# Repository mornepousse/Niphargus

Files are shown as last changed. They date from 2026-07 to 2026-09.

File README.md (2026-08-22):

<p align="center">
  <picture>
    <source media="(prefers-color-scheme: dark)" srcset="images/niphargus_logo_white.svg">
    Niphargus
  </picture>
</p>

<h1 align="center">Niphargus</h1>

<p align="center">
  <em>The cave shrimp: blind, discreet, indestructible.</em><br>
  <em>La crevette des cavernes : aveugle, discrète, indestructible.</em>
</p>

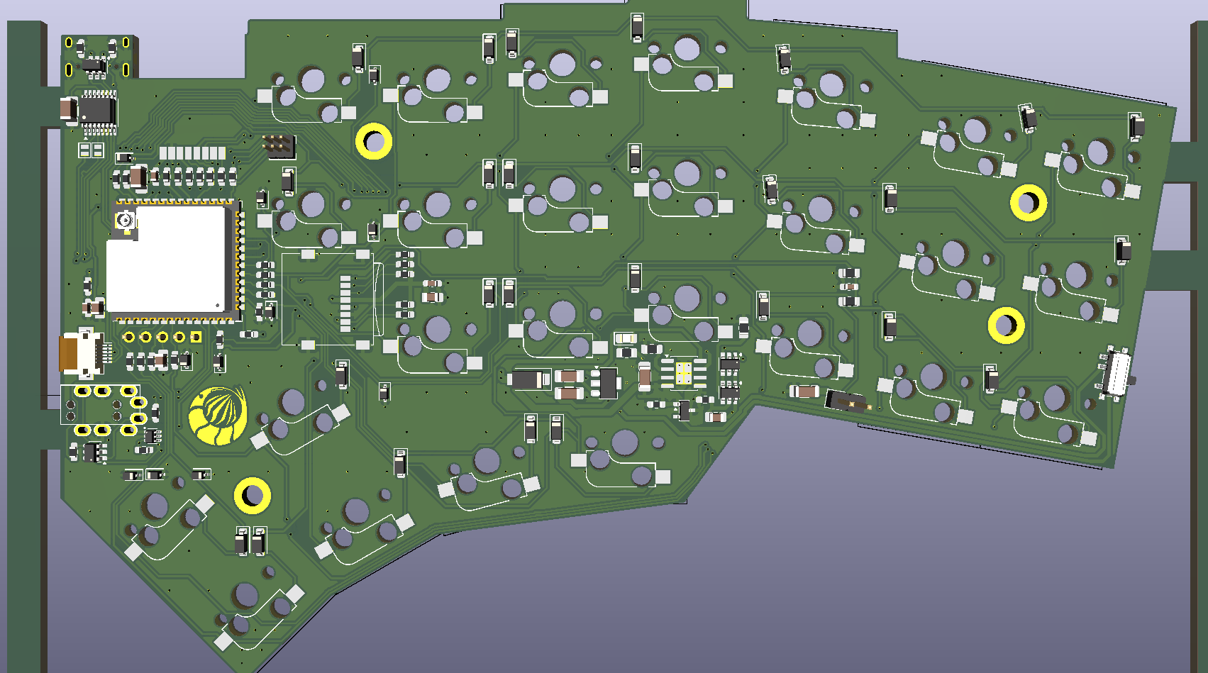
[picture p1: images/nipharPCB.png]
Niphargus PCB v2


---

## English

Niphargus is a thin, unkillable wireless split keyboard.

- **Two self-contained halves** — one ESP32-S3-WROOM-1 + nRF24L01+ and a 16340
  cell each, matrix scanning in deep sleep (RTC domain), the
  [KeSp dongle](https://github.com/mornepousse/KeSp_dongle) on the host side.
- **Wired fallback** — direct USB-C plus a TRRS jack between halves: *plugging it
  back in must be enough*. A 5 V handshake on the link makes hot-plug spark-free.
- **ESD hardening throughout** — TVS diodes on USB and TRRS, 100 Ω in series on
  every matrix line, careful ground planes. The static discharge you bring back
  to the keyboard will no longer crash it.
- **Sharp Memory LCD** (right half) for layer and battery status: holds its image
  at a few µA and never flickers. **Azoteq TPS43 trackpad** (left half), over I²C.
- **The survival kit** — an ESP32-P4 vault behind a CH334R USB hub: multi-ISO boot
  key, PGP token, storage. It only powers up when the keyboard is plugged in.

A complete redesign of the **Rouge-Gorge** (v1, 2022), a Jorne / Kyria rev2
derivative that was never built. This repository carries the full history:
Rouge-Gorge → rili → Niphargus.

**Status (2026-08)** — v2 schematic complete and reviewed, board routed, ERC and
DRC clean. Case in progress (see below). Firmware to follow.

## Français

Niphargus est un clavier split sans fil, fin et increvable.

- **Deux moitiés autonomes** — ESP32-S3-WROOM-1 + nRF24L01+ et une batterie 16340
  chacune, scan de la matrice en sommeil profond (domaine RTC),
  [dongle KeSp](https://github.com/mornepousse/KeSp_dongle) côté hôte.
- **Repli filaire** — USB-C direct et jack TRRS entre les moitiés : *rebrancher
  doit suffire*. Une poignée de main 5 V sur le lien évite les étincelles au branchement à chaud.
- **Robustesse ESD partout** — TVS sur USB et TRRS, 100 Ω série sur chaque ligne
  de matrice, plans de masse soignés. La décharge que vous ramenez au clavier ne
  le plantera plus.
- **Écran Sharp Memory LCD** (moitié droite) pour le calque et l'état des batteries :
  tient l'image à quelques µA sans jamais clignoter. **Trackpad Azoteq TPS43**
  (moitié gauche), en I²C.
- **La trousse de secours** — un coffre ESP32-P4 derrière un hub USB CH334R : clé
  bootable multi-ISO, token PGP, stockage. Il ne s'allume qu'en filaire.

Refonte complète du **Rouge-Gorge** (v1, 2022), un dérivé du Jorne et du Kyria
rev2 resté sur le papier. Le dépôt porte tout l'historique :
Rouge-Gorge → rili → Niphargus.

**État (2026-08)** — schéma v2 terminé et relu, carte routée, ERC et DRC au vert.
Boîtier en cours (ci-dessous). Firmware à suivre.

---

## Repository layout · Organisation du dépôt

| Path | Contents |
|---|---|
| `hardware/pcb/` | KiCad project — `niphar.kicad_pro` (schematic, board, footprints) |
| `hardware/order-*.csv` | Part orders: TME, LCSC, AliExpress |
| `hardware/kit-jlcpcb/` | Gerbers, BOM and CPL for JLCPCB |
| `case/` | Case generator and CAD output |
| `scripts/` | Anti-regression checks |
| `docs/` | Design specs and plans |

### Case · Boîtier

Three parts: a **CNC-machined 8.5 mm aluminium frame**, sandwiched between two
**2 mm polycarbonate plates**, 12.5 mm overall. The 16340 cell sits *beside* the
board, in a pocket milled into the frame itself.

Trois pièces : un **cadre aluminium usiné de 8,5 mm** pris entre deux **plaques
polycarbonate de 2 mm**, 12,5 mm hors tout. La 16340 se loge *à côté* de la carte,
dans une poche fraisée à même le cadre.

The frame outline is **not computed — it is drawn**. Edit `case/case_outline.svg`
(KiCad coordinates, 1 unit = 1 mm), then run:

Le contour du cadre n'est **pas calculé, il est dessiné**. Éditez
`case/case_outline.svg` (repère KiCad, 1 unité = 1 mm), puis lancez :

```sh
freecad --console case/gen_case.py
```

This regenerates the `.FCStd`, the STEP, the STL files and `case_plan.svg`.

### Anti-regression · Anti-régression

```sh
./scripts/check.sh --fast   # schematic ERC against the committed baseline
./scripts/check.sh          # + full board DRC
./scripts/install-hooks.sh  # once per clone: pre-push runs the full check
```

Green means *never more ERC/DRC errors or warnings than the committed baseline*
(`.tripwire-kicad-baseline`). CI is pinned to KiCad 10.0.4 with its own reference.

Vert signifie *jamais plus d'erreurs ni de warnings ERC/DRC que la référence
committée*. La CI est épinglée sur KiCad 10.0.4 avec sa propre référence.

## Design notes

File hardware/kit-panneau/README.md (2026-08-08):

# Kit de fabrication

> **Commandé le 2026-08-08 chez JLCPCB — 60,83 €.** Avant de souder, lire
> [`AU-MONTAGE.md`](AU-MONTAGE.md) : **J6 se soude par le dessous**, le monter
> par le dessus inverse Tip et Sleeve.

Après devis, on commande les deux cartes **séparément**, et le clavier dans sa
version **compacte**.

| Zip | Ce que c'est | Dimensions | Designs | Prix |
|---|---|---|---|---|
| `niphargus-gerbers.zip` | le clavier, 2 moitiés sécables | 340,9 × 104,8 | 2 | 54,78 € |
| `conchodytes-seul-gerbers.zip` | la souris | 39,0 × 81,5 | 1 | 6,06 € |

**60,84 €**, contre 70,89 € pour le panneau commun de départ. Le raisonnement
chiffré est dans `COMPARATIF.md`.

## Le panneau du clavier

340,9 × 104,8 mm, 4 couches, **357,3 cm²**. Les deux moitiés sont côte à côte,
la droite tête-bêche, séparées par une fente de 2,5 mm et reliées par deux
ponts de ~6,5 mm munis chacun d'un `MouseBite-Slot` à double rang.

Le tête-bêche n'est pas cosmétique : remise dans le même sens, la moitié droite
ne touche la gauche que sur **1,75 mm** — les deux bords en vis-à-vis sont
biseautés et divergents. Tête-bêche ils sont parallèles sur **70 mm**, de quoi
poser de vrais ponts, pour 1,6 cm² de plus.

⚠️ **Les mouse-bites vont au milieu du tab, jamais au ras du bord de carte** :
là, ils tombent dans le plan de masse (35 `hole_clearance`, vérifié). Ici les
perçages sont à 0,45 mm du bord, au-dessus du minimum JLC de 0,3. Et après en
avoir posé, **refiller les zones** — sinon 28 `hole_clearance` de plus, que le
refill dissout.

Empreintes réutilisables dans `MaeLid` : `MouseBite_4x0.5mm`, `_5x0.5mm`,
`_6x0.5mm`.

## Le panneau commun, écarté

`scripts/merge_panel.py` sait loger la souris dans le vide du panneau clavier.
La technique fonctionne — contour refermé autour des tabs, 76 mouse-bites — mais
le surcoût du 3ᵉ design (14,21 €) dépasse le prix de la souris seule (6,06 €).
Conservé pour le jour où le rapport de prix changerait.

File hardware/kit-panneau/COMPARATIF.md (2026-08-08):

# Comparatif de commande — à remplir avec les devis JLCPCB

Trois variantes exportées pour comparer le coût réel du multi-design.

| Zip | Contenu | Dimensions | Surface | Designs | Prix (vert, 2026-08) |
|---|---|---|---|---|---|
| `niphargus-gerbers.zip` | **clavier horizontal, retenu** | 340,9 × 104,8 | 357,3 cm² | **2** | **54,78 €** |
| *(clavier compact empilé)* | même design, moitiés imbriquées | 169,2 × 198,2 | 335 cm² | 2 | 53,65 € |
| `conchodytes-seul-gerbers.zip` | **souris, retenue** | 39,0 × 81,5 | 31,8 cm² | **1** | **6,06 €** |
| *(ancien panneau 185,4 × 212,3)* | clavier avant re-panneautage | | 393,5 cm² | 2 | 56,68 € |
| *(panneau commun, écarté)* | clavier + souris | 185,4 × 212,3 | 393,5 cm² | 3 | 70,89 € |

## Décision : commander séparément, avec le panneau horizontal

**Commandé le 2026-08-08 : 60,83 €.**

Devis JLCPCB, 4 couches vert, août 2026 :

```
   A  panneau commun 3 designs                        70,89 EUR
   B  clavier 394 cm2 empile   + souris        56,68 + 6,06 = 62,74 EUR
   C  clavier 335 cm2 empile   + souris        53,65 + 6,06 = 59,71 EUR
   D  clavier 357 cm2 horizontal + souris      54,78 + 6,06 = 60,84 EUR  <-- retenu
```

**10,05 EUR d'economie** entre le point de depart et la solution retenue.

Le panneau horizontal coute **1,13 EUR de plus** que l'empile (option C) : il a
6,4 % de surface en plus, l'imbrication verticale des deux moities n'etant pas
reproductible cote a cote. Il a ete retenu pour sa forme, pas pour son prix.

La repartition est instructive :

- **8,15 EUR** viennent du seul fait de **ne pas panneauter la souris avec le
  clavier**. Ajouter la souris au panneau coute 14,21 EUR de surcout
  multi-design alors que la carte seule vaut 6,06 EUR : on la paierait 2,3 fois
  son prix, pour une surface identique au millimetre.
- **1,90 EUR** viennent du **re-panneautage du clavier**, passe de 394 a
  357 cm2 en posant les deux moities cote a cote, la droite tete-beche, rails
  supprimes. Le prix ne suit pas la surface : le surcout multi-design est un
  forfait qui pese davantage que les cm2 gagnes — un detour par un panneau
  empile a 335 cm2 n'a rendu que 1,13 EUR de plus.

Le second point vaut d'etre retenu pour la suite : **sur un petit panneau,
economiser un design rapporte plus qu'economiser de la surface.**

Le panneau commun et `scripts/merge_panel.py` sont conserves — la technique est
au point et resservira si le rapport de prix change — mais ce n'est pas ce
qu'on commande.

### Conséquence heureuse

La souris n'est plus contrainte par le panneau du clavier. La limite de **42 mm**
de largeur, qui pesait sur la mesure de la coque M100, **disparait** : son
contour definitif pourra faire la taille necessaire.

## Ce que dit JLCPCB

Sont comptés comme designs différents les cartes dont *« les pistes, la
sérigraphie ou le masque diffèrent, dès lors qu'elles peuvent être séparées »* —
v-cut, fraisage **ou trous de perçage**. Nos mouse-bites suffisent donc à
déclencher le comptage.

Les deux moitiés du clavier étant miroir l'une de l'autre, elles comptent pour
**deux designs** à elles seules : même sans la souris, on n'est jamais à 1.

La seule échappatoire documentée — *« placer les designs dans un contour
rectangulaire, sans v-cut, tabs ni fraisage »* — ne s'applique pas ici : notre
contour épouse la forme des claviers (438 mm de bord droit sur 795 mm de
périmètre) et comporte 147 segments de fraisage intérieur. On recevrait sinon
une plaque brute à découper soi-même.

Plafond : 10 designs par panneau. On est à 3.

Sources : [What Counts as Different Designs](https://jlcpcb.com/help/article/different-design-in-your-pcb-files) ·
[In what cases will there be charged extra?](https://jlcpcb.com/help/article/in-what-cases-will-there-be-charged-extra)

## Non vérifié

Les cotes exigées pour les mouse-bites (diamètre, pas, nombre par tab)
n'apparaissent dans aucun de leurs articles — seul le v-cut est détaillé
(70 × 70 mm mini, 2 mm entre lignes parallèles). Les nôtres sont à **Ø 0,5 mm au
pas de 0,75**, valeurs d'usage courant. Si leur revue de fichiers tique, ce sont
`BITE_D` et `BITE_P` dans `scripts/merge_panel.py`.

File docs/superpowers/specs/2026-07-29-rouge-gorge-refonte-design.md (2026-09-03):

# Rouge-Gorge v2 — Design de la refonte

**Date** : 2026-07-29 · **Statut** : BROUILLON — sections en attente de validation par Mae, 3 points ouverts · **Auteure des décisions** : Mae

---

## 1. Le produit

Rouge-Gorge v2 est un clavier split **petit, bas et durable**, full wireless, qui est aussi une
**trousse de secours d'informaticien**. C'est UN produit avec DES modes — pas des variantes :

| Mode | Déclencheur | Comportement |
|---|---|---|
| **Sans-fil** | pas de câble (VBUS absent) | Clavier pur et sobre : frappes → nRF24 → dongle KaSe. USB, SD, C6 éteints. Veille en µA. |
| **Filaire** | câble USB branché (VBUS présent) | Multi-outil : clavier USB HID direct (boot protocol, utilisable au BIOS) + coffre (stockage bootable, token PGP) + **recharge**. Alimentation par le câble. |

La bascule est automatique (détection VBUS), sans bouton ni réglage : « **rebrancher doit suffire** ».
Le système complet = **deux moitiés + le dongle**. Pas de troisième objet.

Ce qui disparaît de l'ancien design : le ProMicro, les LEDs SK6812 (per-key et underglow), l'OLED,
les headers.

## 2. Architecture système

```
┌──────────── moitié G ────────────┐        ┌──────────── moitié D ────────────┐
│ ESP32-S3 (cœur clavier)          │        │ ESP32-S3 (cœur clavier)          │
│  · matrice (scan ULP en sommeil) │        │  · matrice (scan ULP en sommeil) │
│  · nRF24L01+ (SPI)      16340 ▭  │        │  · nRF24L01+ (SPI)      16340 ▭  │
│  · USB-C (HID + charge)          │◄─lien─►│  · USB-C (HID + charge)          │
└───────────────┬──────────────────┘ filaire└──────────────┬───────────────────┘
                │ nRF24 ESB (protocole KaSe)                │
                ▼                                           ▼
        ┌─────────────────── dongle KaSe (ESP32-S3, 2 radios) ────────────────┐
        │ USB HID vers l'hôte · hub CH334R                                    │
        │ [OUVERT] coffre P4 greffé derrière le hub ?                         │
        └─────────────────────────────────────────────────────────────────────┘
```

- **Cœur de chaque moitié : ESP32-S3** (module WROOM soudé à plat). Rôle HID-seul + radio — le rôle
  exact du « smart keyboard » KaSe déjà éprouvé en production (routage `usb_presence`, relais nRF24,
  pairing). Sleep archi-connu (~7 µA deep / ~240 µA light), ULP-RISC-V pour scanner la matrice en
  sommeil sans perdre la première frappe.
- **Coffre : module JC-ESP32P4-M3** (stock Mae) — USB 2.0 **haute vitesse** + digital signature
  peripheral + key management unit. Il porte le stockage et le token PGP.
- **[OUVERT №1 — la maison du coffre]** : (D) greffé derrière le CH334R du dongle (révision du
  dongle ; moitiés pures et plates ; P4 alimenté par l'hôte → conso hors équation ; « une prise =
  clavier + ISO + identité » au BIOS) **ou** (C) en mezzanine dans le volume du tube 16340 d'une
  moitié (autonome, mais surface/volume dans l'objet le plus contraint). Donnée qui tranche :
  port libre/récupérable sur le CH334R du dongle actuel, et dongle révisable ou non.
- Leçon fondatrice (échec vécu sur le dongle S3 : composite HID+PGP → clavier qui lague) :
  **l'important et l'accessoire ne partagent jamais un même device USB**. D'où le hub (CH334R,
  USB2 HS, facile à souder — éprouvé par Mae) et les siliciums séparés.

## 3. Modes & stabilité — « le clavier est là coûte que coûte »

Hiérarchie de disponibilité à quatre étages :

| Étage | Mécanisme | Garantie |
|---|---|---|
| 0 | Matrice scannée par l'ULP du S3 | une frappe est toujours captée |
| 1 | **Deux chemins vers l'hôte sur siliciums séparés** : USB direct / radio→dongle | la panne d'un chemin n'emporte pas l'autre |
| 2 | Features sacrifiables ; boot **clavier-d'abord**, features après | un crash de feature = redémarrage de la feature, pas du clavier |
| 3 | Watchdog matériel + brown-out | pire cas absolu : clignement < 1 s, auto-réparé |

L'isolation absolue sur un même chip n'existe pas ; la garantie du produit est : **aucune panne de
feature ne prive le PC des frappes plus d'une seconde**. (En mode filaire, la radio peut rester en
veille chaude comme chemin de secours — le câble paie le courant.)

## 4. Alimentation

**Cellule : 16340 (~700 mAh), en tube le long d'un bord du PCB** — le corps du clavier reste bas,
la bosse est un cylindre assumé en bordure (arrière = tilt naturel ; bord exact à dessiner).
Cellules souvent non protégées → protection sur PCB.

Chaîne : `16340 → DW01A+FS8205 (protection) → TP4056 SOP-8 (~500 mA) + load-sharing P-FET
→ régulateur 3,3 V → système`

- **Load-sharing obligatoire** : brancher = utiliser ET charger (le mode filaire l'exige).
- **Régulateur : MCP1700-3302 (SOT-23)** [VALIDÉ Mae] — 1,6 µA de repos (l'auto-décharge de la
  cellule fuit ~20× plus), 250 mA, soudable au fer, banal et remplaçable. Conséquence assumée :
  la radio WiFi/BLE du S3 ne sera jamais utilisée (pics 350-500 mA hors budget) — le lien est le
  nRF24, les mises à jour passent par USB. Coût vs buck-boost : ~3-4 jours d'autonomie par cycle.
- Jauge : diviseur haute impédance → ADC → champ `batt_dV` du heartbeat KaSe (déjà prévu au protocole).
- **Interrupteur : slide mécanique (type MSK-12C02), coupure côté système** [VALIDÉ Mae] — la
  charge reste possible clavier éteint (~3 µA résiduels), état visible, zéro firmware ; encastré
  dans le chant pour survivre au sac. Raison d'être : le transport (touches martelées = réveils +
  retries radio), pas la veille.
- Budget : ~50-80 mAh/jour de bureau → **1 à 3 semaines** d'autonomie.

## 5. Lien inter-moitiés (mode filaire uniquement)

En sans-fil, les moitiés ne se parlent pas (chacune → dongle). Le lien ne sert qu'au fallback
filaire : la moitié branchée reçoit les frappes de l'autre. **4 lignes : GND, UART croisé (TX/RX),
5 V commuté.**

**Décision : 5 V « en poignée de main »** — le contact d'alim est mort par défaut ; après
reconnaissance UART (« t'es bien ma moitié ? »), la moitié nourrie au câble ferme un **load switch
intégré** (classe AP22802/SiP32431 : limitation de courant + soft-start) et envoie le 5 V, qui
**recharge la moitié d'en face**. Un court-circuit de branchement à chaud est physiquement
impossible — c'est la réponse définitive au tueur historique de splits.

**[OUVERT №2 — le connecteur]** : jack TRRS (banal, câble remplaçable partout, mais raclage à
l'insertion et vulnérable à l'arrachage) **vs** magnétique pogo (hot-plug sûr mécaniquement,
se détache au lieu de casser, ~3 mm de haut, mais câble propriétaire ; candidat AliExpress trouvé
par Mae — specs à relever : ≥ 4 contacts, ≥ 0,5-1 A, forme embase/câble, détrompage).
Option protos : **double empreinte**, l'usage tranche.

## 6. ESD — l'exigence historique

Le scénario à tuer : l'utilisateur revient chargé de quelques kV, touche le clavier, le clavier
plante jusqu'au débranchage. Défense en couches, de l'extérieur vers l'intérieur :

| Couche | Mesure | Note |
|---|---|---|
| 0 · paratonnerre | plans de masse pleins cousus de vias ; vis sur pads GND ; plaque (alu de préférence) reliée à GND | le châssis avale la décharge avant les pistes |
| 1 · douaniers | TVS à **2 mm de chaque connecteur** : USBLC6-2 (USB-C), array 4 lignes type SRV05-4 (lien inter-moitiés), array sur SD si slot exposé | ~1 €, trois boîtiers |
| 2 · organes vitaux | CHIP_PU / lignes boot : RC + pistes courtes (+ TVS si proches d'un connecteur) | la ligne qui fait « planté sans reset » |
| 3 · matrice | ~100 Ω série sur les 11 lignes de matrice | les clamps internes digèrent le résidu |
| 4 · curatif | la hiérarchie de stabilité (§3) | une décharge exotique = clignement, pas une mort |

Surcoût total ≈ 2 €, zéro épaisseur. L'ancien design comptait 199 violations de cuivre en bord de
PCB (amorçages potentiels) — déjà en cours d'éradication dans le chantier KiCad, mesurée par la
baseline tripwire.

## 7. Mécanique

La leçon des claviers précédents : **le PCB trop haut casse les boîtiers** — coupable : le ProMicro
sur headers (12-14 mm sous PCB). Règles de la v2 :

- **Zéro header.** Tout SMD soudé à plat ; modules en découpe de PCB si besoin ; USB-C mid-mount ;
  le jack/connecteur inter-moitiés peut vivre côté touches sous la plaque (5 mm d'air en MX).
- **Dégagement sous PCB ≈ 3,5 mm** (plancher naturel = sockets hotswap 1,9 mm ; modules 3,2-3,4 mm).
- **Construction sandwich** : plaque + entretoises + fond, vis en compression pure — plus de coque
  imprimée qui fend. Plaque alu = collecteur ESD en bonus.
- Switches : **mix MX/Choc par position** (footprints hybrides existants) — en sachant que la
  hauteur du case suit le plus haut des deux.
- Le tube 16340 en bordure est le seul relief ; il peut porter le tilt.

## 8. USB filaire — la trousse de secours

Une prise branchée au BIOS d'une machine quelconque donne :

- **Le clavier** : HID *boot protocol* (dialecte BIOS) depuis le S3 de la moitié branchée — ou
  depuis le dongle.
- **Le médium d'installation** : le coffre P4 expose la SD en MSC (SDIO 4 bits, ~20-40 Mo/s réels
  — classe « bonne clé USB 2 », largement suffisant pour booter/installer). **Multi-ISO par Ventoy
  sur la SD** : le firmware reste un MSC bête, la collection d'ISO se gère par glisser-déposer.
  Volume « config » possible en plus sur la flash 16 Mo du module (keymap éditable en fichier).
- **L'identité** : token PGP sur le silicium crypto du P4 (DS peripheral + KMU : clé privée jamais
  lisible par le firmware ; secure boot + flash encryption). Confirmation de présence par
  appui-touche — le clavier a déjà les boutons.
- **Mode lecture seule** (switch physique ou bascule) : la clé de secours devient inviolable sur
  machine douteuse.
- Débit et latence cohabitent sans se gêner : le HID (8 ko/s, endpoints interrupt réservés par le
  protocole USB) est intouchable par les transferts bulk ; le plafond réel est la SD, pas le hub.
- La SD est **coupée électriquement en mode sans-fil** (transistor commandé par VBUS) : zéro fuite
  sur la batterie.

## 9. Radio

- nRF24L01+ du stock, posés à plat (découpe PCB), **protocole KaSe intact** : ESB 1 Mbps, CRC 16,
  adresses 5 octets, DPL, ARC 15/ARD 500 µs ; trames PKT_KEY/PKT_HEARTBEAT (bitmap 5×7 — couvre la
  matrice, batt_dV, link_q).
- **Pairing runtime KaSe** (canal 40, set_id dérivé du MAC du dongle, canaux 80-119) : l'isolation
  entre Rouge-Gorge et les claviers KaSe voisins est déjà résolue par construction.
- ⚠ **Corrigé le 2026-08-19** : Rouge-Gorge n'occupe **qu'un seul slot** du dongle.
  Le second appartient à la souris **Conchodytes**, qui vise le même récepteur. En
  conséquence les moitiés ne passent plus toutes deux par le dongle : la droite
  émet en direct vers la gauche, qui porte le moteur keymap et parle seule au
  dongle. Voir le design firmware dans KeSp_firmware
  (`docs/superpowers/specs/2026-08-19-niphargus-firmware-design.md`).
- Plus tard, optionnel : canal ESP-NOW « info » via le C6 du module P4 (antenne IPEX déjà sur le
  module) — coût hardware nul aujourd'hui.

## 10. Chantier & validation

- **Tripwire** : la baseline ERC/DRC (`.tripwire-kicad-baseline`) mesure la fonte des violations
  pendant la refonte — objectif **zéro** à la fin. Arbre rouge en cours de chirurgie = normal ;
  push WIP : `--no-verify`.
- **Si le coffre finit en moitié** (option C) : manip « composite sous charge » sur carte porteuse
  P4 obligatoire avant routage (leçon S3 : on ne croit plus le papier, on mesure). Si coffre au
  dongle (option D) : cette manip disparaît, chaque micro n'a qu'un rôle.
- **Ordre des protos** : PCB des moitiés d'abord (le cœur ne dépend d'aucun point ouvert) ; la
  maison du coffre se décide en parallèle.
- Après validation de ce design : plan d'implémentation détaillé (schéma → layout → case), puis le
  firmware (hors périmètre de ce document).

## Points ouverts (récapitulatif)

1. **Maison du coffre P4** : dongle révisé (D) vs mezzanine dans la bosse (C) — donnée décisive :
   port libre sur le CH334R du dongle, dongle révisable ?
2. **Connecteur inter-moitiés** : TRRS vs magnétique pogo (specs du candidat AliExpress à relever) ;
   option double empreinte sur protos.
3. **Micro-choix de schéma restants** : bord exact du tube 16340 et type de contacts cellule,
   layout final des touches. (Régulateur et interrupteur : tranchés — voir §4.)

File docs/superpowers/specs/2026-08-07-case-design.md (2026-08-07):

# Boîtier Niphargus — conception mécanique

*Brainstorm du 2026-08-07 (Mae + Claude). Toutes les cotes internes sont mesurées sur
`hardware/pcb/niphar.kicad_pcb` dans son état routé, pas estimées.*

## 1. Intention

Reprendre l'objectif d'origine — **fin et durable** — sans reproduire l'échec des v1 (coque
imprimée qui fend, PCB mal soutenu). Trois pièces, aucune imprimée, et une silhouette qui
tire parti du seul relief inévitable : la pile.

## 2. Structure retenue : trois pièces

| Pièce | Matière | Épaisseur | Fabrication |
|---|---|---|---|
| Plaque à switchs | polycarbonate transparent | **2,0 mm** | découpe |
| Cadre (logement accu compris) | **aluminium usiné** | **8,5 mm** | CNC — test JLCPCB |
| Fond | polycarbonate transparent | **2,0 mm** | découpe |

**Clavier plat à 12,5 mm hors tout.** Le logement de l'accu est usiné *dans* le bloc du
cadre, il n'est plus une pièce rapportée ; la trappe a disparu — l'accu dépasse par une
fenêtre de la plaque haute. Choix Mae du 2026-08-07 : plaque à 2 mm (et non 1,5) — les
clips MX ne se verrouillent donc pas, les switchs sont tenus par les sockets hotswap.

**Assemblage** : 6 vis M3 traversantes (Ø3,2) plaque → cadre → fond, positionnées par Mae.
Attention, les 4 vis de coin n'ont que **1,4 mm de matière** autour du perçage : à élargir
localement avant usinage (les 2 autres sont à +1,9 et +2,4 mm).

## 3. Empilage interne (cotes mesurées sur la carte routée)

```
        ┌───────────────────────┐  plaque PC 2,0        z 8,5 → 10,5
        │   3,4 mm  (norme MX)  │  ← module P4 (3,2) y tient à 0,2 près
   ─────┼───────────────────────┼─────  PCB 1,6         z 3,5 → 5,1
cadre   │   3,5 mm              │  ← module S3 3,1 · nRF24 · interrupteur · microSD
  8,5   └───────────────────────┘  fond PC 2,0          z -2 → 0
```

Jeu autour du PCB : **0,5 mm** (tolérance fraisage PCB ±0,2 + usinage ±0,1). Le PCB est
positionné par les 4 vis M3, pas par le cadre.

**Jack TRRS** : sort **par le dessus** (côté touches), décision Mae du 2026-08-07 —
ouverture de z=5,1 à 8,5 dans le chant, plus un dégagement de 7,5 mm dans la plaque haute.
Le fichier PCB place pourtant `J6` en `B.Cu` : si le jack est bien monté sur le dessus,
c'est **le footprint qui est sur la mauvaise face**, à corriger avant de commander.
Réserve de cote : au-dessus du PCB il n'y a que 3,4 + 2 = 5,4 mm, contre ~6,3 mm de jack
au catalogue — à mesurer au pied à coulisse.

## 4. Accu : À CÔTÉ de la carte, pas dessous

La 16340 (Ø16,5 × 34,5) est logée **hors du contour du PCB**, le long du bord inférieur
gauche (segment 27,4·90 → 81,4·80,3, pente −10°), sous les touches SW5/SW14/SW21 au sens
du plan. Centre à ~53,6 · 96,5, axe à 11 mm du bord. Le cadre s'élargit localement au lieu de s'épaissir, en restant à 8,5 mm.
Poche **rectangulaire débouchante** (37 × 17,5, coins R3 — une passe de fraise), l'accu
repose sur la plaque de fond transparente et dépasse par une fenêtre de la plaque haute.
Plus de fond à usiner, plus de trappe. La séparation entre la poche et la cavité du PCB
a été **supprimée** (123 mm²) pour gagner en encombrement, en gardant un **pontet de 6 mm
à chaque bout** — sans lui le bloc se détache du cadre.

**Repères** : KiCad et FreeCAD partagent x (horizontal), y (vertical), z (profondeur) ;
seule différence, y pointe vers le bas dans KiCad et vers le haut dans FreeCAD — le
générateur convertit (y_fc = −y_kicad), les plans SVG restent en repère KiCad.

## 5. Fabrication : prototype d'abord

1. **Proto plexi/PC découpé** : les trois pièces à plat (cadre en couches empilées pour
   simuler les 8,5 mm), pour valider ajustement, ouvertures, ergonomie et sens du biseau.
   Bon marché, jetable, aucun engagement.
2. **Cadre alu CNC** ensuite, une fois la géométrie éprouvée. Devis instantané et gratuit
   chez JLC en téléversant un STEP. Ordre de grandeur attendu : **60-150 € les deux
   moitiés** anodisées. Leviers de prix : épaisseur brute, nombre de bridages, rayons
   intérieurs (viser **R ≥ 3 mm**), anodisation.
3. **Repli** si le devis pique : cadre en deux couches découpées (profil en escalier au
   lieu du coin).

**Règle de dessin CNC** : pas d'angle intérieur vif — la fraise est ronde. Un dessin pensé
pour l'impression 3D ne s'usine pas.

## 6. Modèle 3D — `case/`

**Le contour du cadre n'est plus calculé, il est dessiné.** `case/gen_case.py`
(`freecad --console`) lit `case/case_outline.svg`, le SVG que Mae édite, et en tire
les trois solides + `case_plan.svg` de contrôle.

Ce que le script lit dans le SVG, identifié par la taille de l'emprise : contour extérieur,
contour intérieur, contour du PCB (repère), 26 découpes de touches, rectangle de l'accu,
et les trous Ø3,2 des vis. Le calage sur le repère KiCad est `DX,DY = -28,030 / -137,600`,
**validé à 0,009 mm** en recoupant les 26 découpes avec la position des switchs.

Ce que le script ajoute lui-même : les ouvertures USB-C / TRRS / interrupteur, percées
**perpendiculairement au chant** (normale au bord le plus proche — prendre la direction du
point le plus proche donnait un angle faux), et les dégagements de la plaque haute.

**Piège vérifié** : l'origine d'un footprint KiCad n'est pas son centre. `U16` (module P4)
est décalé de **20,51 mm**, `J12` de 5,08 mm. Toujours calculer l'emprise réelle des pads.
Dégagements actuels : module P4 28,8 × 29,2 à (172,16 · 53,68) ; connecteur écran `J12`
(header 1×05) 3,7 × 13,9 à (171,46 · 69,98).

L'ancien générateur paramétrique `gen_pd.py` (contour par offset du PCB) a été supprimé
le 2026-08-07 ; il reste dans l'historique git si besoin.

**Contenu du dossier** : `gen_case.py` et `case_outline.svg` sont les deux **sources** —
tout le reste est régénéré à partir d'elles (`.FCStd`, `.step`, `.stl`, `case_plan.svg`).

Généré **par script paramétrique** (CadQuery/build123d ou `freecadcmd`, en shell éphémère
NixOS) à partir des cotes réelles du PCB : contour, trous de montage, positions des
connecteurs. Un paramètre change → le STEP se régénère. `kicad-cli pcb export step` fournit
en plus le PCB complet avec ses composants comme référence d'encombrement.

## 7. Points de fixation

4 trous M3 par moitié, déjà sur la carte : (40,3 · 49,6) (43,7 · 68,2) (139,5 · 40,3)
(157,9 · 94,0) — repère KiCad. Ce sont des `MountingHole_3.2mm_M3_DIN965_Pad`, donc
**reliés à GND** : les vis participent au chemin ESD dès que le cadre est en alu.

**Non tranché** : vis traversantes plaque→fond avec le cadre en compression, ou taraudage
dans le cadre alu. Le nombre de points est peut-être à revoir (4 par moitié sur
177 × 108 mm, à confirmer au proto — une plaque PC de 2 mm fléchit).

## 8. Ouvertures à dessiner

Dans le chant du cadre : **USB-C** (côté touches), **jack TRRS** (côté fond),
**interrupteur à glissière** (accès latéral, doit pouvoir être actionné). Dans les plaques :
**trackpad** (43 mm, côté gauche), **écran Sharp** (côté droit), **fente microSD** (accès
au coffre P4), découpe-berceau du jack dans le fond, éventuelles lucarnes de dégagement.

Positions relevées sur la carte (repère KiCad, moitié gauche) : USB-C (181 · 26) ·
TRRS (187 · 80) · interrupteur (28 · 76) · trackpad (182 · 73) · microSD (145 · 64) ·
module P4 (158 · 68) · connecteur pile (67 · 80).

## 9. Reste à faire

- [ ] **Élargir la paroi autour des 4 vis de coin** (1,4 mm de matière, trop peu pour du PC)
- [ ] **Capot polycarbonate de protection** par-dessus le module P4 et l'écran (Mae, plus tard)
- [ ] Vérifier la face de `J6` dans KiCad (`B.Cu` alors que le jack sort par le dessus)
- [ ] Trancher le sens du biseau (au proto)
- [ ] Dessiner les ouvertures aux vraies cotes des connecteurs
- [ ] Vérifier au pied à coulisse la hauteur réelle du jack MJ-4PP-9 (6,3 mm = valeur catalogue)
- [ ] Choisir la finition (anodisation : couleur, satiné/brossé)
- [ ] Générer le premier STEP et relever le devis JLC

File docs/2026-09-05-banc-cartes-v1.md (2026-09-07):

# Banc v1 — relevés et pistes ouvertes (5 septembre 2026)

Tout ce qui suit attend un multimètre. Rien n'est à faire avant d'avoir mesuré :
les deux pannes ci-dessous ont chacune plusieurs causes possibles, et deux
d'entre elles ne coûtent rien à écarter.

---

## 1. Point de chauffe sur U21 — RÉSOLU (LDO remplacé), PCB CORRIGÉ

> **U21 remplacé, la moitié droite fonctionne.** Le pontage de masque avait mis
> `GND`, l'entrée et la sortie `+3.3V_D` en court : le régulateur y est passé.
> Un HT7833 neuf et le rail remonte.
>
> ⚠️ **Le défaut de masque est TOUJOURS sur la carte.** Le composant neuf est
> posé sur les mêmes trois pastilles, sans vernis entre elles. Ça fonctionne
> aujourd'hui parce que la soudure ne ponte pas — rien ne garantit que ça tienne
> à un cycle thermique, une reprise au fer ou un choc. **Isoler les pastilles**
> (vernis, kapton) reste à faire, ici et sur toutes les moitiés droites déjà
> fabriquées.
>
> Le PCB est corrigé pour les fabrications suivantes (commit `53564e4`).

**Symptôme** : gros point de chauffe sur U21, le LDO 3,3 V de la moitié droite.

**Cause**, nommée par le DRC de KiCad lancé avec `--refill-zones` :

```
[error] L'ouverture du masque de soudure de dessous relie des elements
        de nets differents
    - Pad 1 [GND]         de U21
    - Pad 2 [Net-(D51-K)] de U21
[error] idem entre Pad 2 [Net-(D51-K)] et Pad 3 [+3.3V_D]
```

Les trois pastilles de U21 partageaient **une seule ouverture de masque** :
GND, l'entrée et la sortie 3,3 V sans vernis entre elles, du cuivre nu continu.
La soudure ponte toute seule.

**Origine** : les trois pads portaient une rotation de 180° que la sérigraphie
et le contour Fab n'avaient pas. Sur les pads 1 et 3, roundrect symétriques,
sans effet — **GND et la sortie ne sont PAS interverties, le composant est dans
le bon sens, ne le retourne pas.** Mais le pad 2 est un pad `custom` : son
polygone de languette, retourné, étalait une ouverture de masque par-dessus les
trois pastilles.

U20, le même LDO à gauche, n'avait pas l'anomalie : empreinte à 180 et pads à
180, soit 0 d'écart. U21 était à 0 avec des pads à 180.

**Corrigé** dans le commit `53564e4` : suppression des trois rotations de pad.
3 violations disparues, aucune nouvelle.

### Ce qui reste à faire sur la carte physique

C'est un défaut de fabrication, pas de montage — **toutes les moitiés droites
déjà fabriquées sont concernées**.

1. Dessouder le pontage entre les pastilles de U21 (tresse, puis loupe).
2. Le cuivre nu reste : un peu de vernis ou de kapton entre les pastilles évite
   que ça re-ponte au remontage.
3. Avant de réalimenter : pas de court franc entre pad 2 et pad 1, ni entre
   pad 2 et pad 3.

### Reste ouvert

`courtyards_overlap` entre **U21 et C23** — le condensateur chevauche le
régulateur depuis son déplacement. Le remettre à son ancienne position
supprime le chevauchement mais laisse une piste en l'air (`track_dangling` sur
`Net-(D51-K)`) : le routage a suivi la nouvelle place. À replacer proprement
dans KiCad, avec le routage.

---

## 2. Aucune tension sur la moitié gauche en mode batterie — RÉSOLU

> **CAUSE : la broche 1 de Q4 (FS8205) n'était pas soudée.**
>
> Broche 1 = `S1` = `-BATT`, la source du FET de décharge. Patte en l'air, donc
> aucun chemin de retour pour la batterie — ni en décharge, ni en charge.
> Ressoudée, la moitié gauche démarre sur batterie.
>
> **Pourquoi la continuité ne l'a pas vu.** `U23 pad 6 ↔ Q4 pad 1` bipait
> correctement : une broche non soudée **repose** sur sa pastille, et la pointe
> de touche l'y écrase. Le contact se fait pendant la mesure et disparaît dès
> qu'on retire la pointe. **Aucun test de continuité ne peut attraper une
> soudure froide sur une patte posée.** Il faut un contrôle visuel, ou pousser
> la patte latéralement pendant la mesure.
>
> **Ce qui a fini par le trahir** : le pont maintenu entre `-BATT` et `GND`
> faisait passer OD à 3,5 V, mais l'état ne tenait pas au retrait du pont. Or si
> FET1 conduisait, son canal maintiendrait `GND` sur `-BATT` et l'état
> s'auto-entretiendrait. Il ne tenait pas ⇒ la commande arrivait, le canal ne
> conduisait pas ⇒ le défaut était dans Q4 ou ses soudures de puissance, pas
> dans le pilotage.
>
> Le reste de la chaîne était sain et se comportait logiquement : `GND`
> flottait faute de retour, CS lisait 0,5 à 2,2 V selon la charge — bien
> au-dessus du seuil de 150 mV — donc le DW01A coupait la décharge et gardait la
> charge ouverte. Comportement conforme à sa datasheet du début à la fin.

### Ce qui reste vrai et vérifié dans l'analyse ci-dessous

Le brochage du DW01A et celui du FS8205 ont été contrôlés sur les datasheets
fabricant à cette occasion. **Ils sont justes** — c'est consigné plus bas et ça
reste valable pour toute panne future sur cette chaîne.

---

### Analyse d'origine (conservée)

**Symptôme** : rien en batterie sur la gauche. Tout fonctionne sur USB.

### Le design est hors de cause — vérifié, sourcé

C'était l'inquiétude légitime : si le symbole maison `rouge_gorge:FS8205` avait
un brochage faux, c'était toutes les cartes à refaire. **Ce n'est pas le cas.**

**DW01A** — datasheet H&M Semiconductor, celle citée dans le schéma
(`https://hmsemi.com/downfile/DW01A.PDF`), section *Pin Configuration* :

| Broche | Symbole | Câblage de U23 | |
|---|---|---|---|
| 1 | OD — grille du FET de décharge | `Net-(Q4-G1)` | OK |
| 2 | CS — sense de courant | → R73 **1 k** → `GND` | OK |
| 3 | OC — grille du FET de charge | `Net-(Q4-G2)` | OK |
| 4 | TD — broche de test | non connectée | OK |
| 5 | VCC — via une résistance R1 | ← R70 **100 Ω** ← `+BATT` | OK |
| 6 | GND | `-BATT` | OK |

Le *Typical Application Circuit* de la même datasheet donne R1 = 100 Ω et
R2 = 1 kΩ : les valeurs de la carte au composant près. Et la masse du DW01A va
bien au négatif de la **cellule** pendant que CS va au négatif du **système**.

**FS8205** — deux fabricants indépendants, tous deux avec un dessin numéroté :

- JSCJ/JCET *CJL8205A Rev 2.0*, section *Equivalent Circuit*, broches
  numérotées directement sur le schéma
- UMW *8205A*, dessin *SOT23-6 top view* avec le repère de broche 1

| pad | Câblage de Q4 | Fonction | UMW | JSCJ |
|---|---|---|---|---|
| 1 | `-BATT` | S1 | OK | OK |
| 2 | drains | D1/D2 | OK | OK |
| 3 | `GND` | S2 | OK | OK |
| 4 | `Net-(Q4-G2)` | G2 | OK | OK |
| 5 | drains | D1/D2 | OK | OK |
| 6 | `Net-(Q4-G1)` | G1 | OK | OK |

> **Ne pas se fier aux recherches web sur ce composant.** Trois recherches ont
> donné trois brochages différents, tous faux, dont un qui inversait précisément
> les broches 1 et 6 — de quoi condamner un lot de cartes à tort. Seuls les PDF
> lus directement font foi. Même leçon que pour le XC6206 sur Conchodytes.

### La topologie, et pourquoi le symptôme est cohérent

```
J10 pad1 = -BATT ──> Q4 FS8205 ──> GND
J10 pad2 = +BATT ──> Q2 AO3407 ──> SW54 ──> D52-K ──> U20 VIN
                └──> R70 100R ──> VCC du DW01A
```

**Le FS8205 est dans le chemin de MASSE**, entre `-BATT` et `GND`. S'il ne
conduit pas, la batterie n'a aucun retour : on lit la cellule sur J10 et zéro
partout ailleurs. Sur USB tout marche, la masse venant du connecteur. C'est
exactement le symptôme.

### Mesures à faire, batterie branchée et USB débranché

| # | Mesure | Attendu | Sinon |
|---|---|---|---|
| 1 | `-BATT` ↔ `GND` | ≈ 0 V | tension pleine → chemin de masse ouvert, c'est là |
| 2 | J10 pad 2 ↔ pad 1 | 3,0 – 4,2 V | < 2,4 V → cellule sous le seuil, protection verrouillée |
| 3 | U23 broche 5 (bornes de R70) | ≈ Vbat | 0 V → R70 ou DW01A absent/mort |
| 4 | U23 broches 1 et 3 | ≈ Vbat | 0 V → protection en sécurité, ou pas de VCC |

**Commencer par la 1**, c'est elle qui oriente tout le reste.

### Le test gratuit, à faire en premier

Le **verrouillage par décharge profonde** du DW01A : détection à 2,40 V,
remise en service à 3,0 V (datasheet, *Product Name List*). Sous le seuil la
protection coupe la masse et ne se réarme **qu'à l'application d'un chargeur**.
Symptôme : rien en batterie, tout va bien en USB, indéfiniment.

Brancher l'USB dix minutes, débrancher, retenter. Si ça repart, c'était ça, et
il n'y a rien à réparer.

### La question qui vaut dix mesures

**Est-ce que la moitié droite fonctionne sur batterie ?** Même circuit, mêmes
composants, même symbole. Si la droite marche, la panne est locale à gauche.

---

## 3. Le ratchet de check.sh n'a pas vu le défaut de U21

Quand le déplacement de C23 a été poussé (`15e3549`), `check.sh` était vert. Le
DRC était pourtant passé de 473 à 164 violations : un recalcul de zones avait
effacé des centaines de warnings de remplissage, et **quatre erreurs neuves sont
passées sous cette amélioration globale**, dont le chevauchement U21/C23.

Le ratchet compare des **comptes**. Il ne peut pas voir une erreur critique
apparaître pendant qu'une centaine d'autres disparaissent.

Deux corrections à envisager pour `scripts/check.sh` :

1. Lancer le DRC **avec `--refill-zones`**. Sans ça le résultat dépend de l'état
   de remplissage sauvegardé, qui n'est pas déterministe d'une session KiCad à
   l'autre — c'est ce qui a masqué le vrai défaut pendant tout ce temps.
2. Suivre les violations **par type**, pas seulement leur total. Une nouvelle
   `clearance` ou un nouveau `solder_mask_bridge` doit être rouge même si le
   total baisse.

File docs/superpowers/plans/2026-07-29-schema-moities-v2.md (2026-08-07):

v# Schéma KiCad des moitiés Rouge-Gorge v2 — Plan d'implémentation

> **Exécution en binôme** : Mae dessine dans KiCad (GUI), Claude fournit chaque bloc (composants,
> valeurs, table de connexions), vérifie au tripwire et relit le `.kicad_sch` (format texte).
> Les étapes utilisent des cases `- [ ]`. Une tâche = un bloc = un commit.

**But** : le schéma complet des deux moitiés Rouge-Gorge v2, ERC zéro erreur, prêt pour le layout.

**Architecture** (décision Mae 2026-07-29 : **pas de PCB réversible, pas de deuxième projet — un seul projet, un seul `.kicad_pcb` contenant les deux moitiés côte à côte**, deux contours sur Edge.Cuts) : projet KiCad neuf `rouge-gorge/`, feuille chapeau `moitie.kicad_sch` contenant les 4 feuilles (alim / mcu+radio / matrice / liens), instanciée 2× à la racine (gauche/droite) — les tâches 1-4 se font sur une seule instance, la 2ᵉ instance arrive en Tâche 5. Réf. : design doc `docs/superpowers/specs/2026-07-29-rouge-gorge-refonte-design.md`.

**Stack** : KiCad 10.0.x · tripwire (`./scripts/check.sh --fast` = ERC ratchet) · libs locales existantes (`hardware/pcb/*.pretty`, `mae.kicad_sym`) + libs officielles KiCad.

## Contraintes globales

- **Zéro header** — tout composant est SMD soudé ou en socket plat validé au design doc.
- **La radio WiFi/BLE du S3 ne sera jamais utilisée** (MCP1700 250 mA — décision Mae).
- **Hors périmètre de ce plan** : le coffre P4 (point ouvert №1), le firmware, le layout PCB.
- **Baseline tripwire neuve** : sur ce projet, vert = **0 erreur ERC** (pas d'héritage toléré).
- **Résidu DRC connu du choix « 2 moitiés, 1 PCB »** : les nets globaux (GND, +3V3, VSYS, +BATT, VBUS_5V) existent dans les deux moitiés sans cuivre entre elles → le DRC verra ~5 « unconnected items » incompressibles entre les deux planches. Piste vers le zéro : **exclusions DRC** posées une fois sur ces violations précises (stockées dans le `.kicad_pcb`, normalement honorées par `kicad-cli` — à vérifier au moment du layout) ; sinon le résidu est documenté et gelé dans la baseline. **Décision Mae 2026-07-29 : panneau sécable** — 1 seul gerber, les deux moitiés reliées par tabs + mouse-bites (ajoutés par script juste avant commande ; un tab peut porter le GND → résidu unconnected éliminable). Commande fab : « panel by customer, different designs : 2 ». Miroir du côté droit : script `mirror_panel.py` (positions x→2a−x, angle empreinte →−θ, angles internes absolus +δ, pads dé-netés, uuids neufs) — conservé en scratchpad, à archiver dans `scripts/` à la phase layout.
- Coordination : Mae peut garder corne-cherry ouvert (projet séparé) ; elle **sauvegarde** avant chaque revue de Claude.
- Le connecteur inter-moitiés est dessiné **générique 4 pins** (`J_LINK`) — le choix TRRS vs magnétique (point ouvert №2) se fera au layout, éventuellement en double empreinte.

## Carte des pins ESP32-S3-WROOM-1 (référence normative — MCU tranché par Mae 2026-07-29 ; remap depuis la version MINI-1 : GPIO33/34 non câblés sur WROOM-1, GPIO35-37 réservés PSRAM octale sur variantes R8/R16V → évités par prudence)

| Fonction | GPIO | Contrainte respectée |
|---|---|---|
| Lignes matrice ROW0-3 (sorties scan) | 1, 2, 4, 5 | RTC ✓ (scan ULP en sommeil) |
| Colonnes matrice COL0-6 (entrées, pull-down) | 6, 7, 8, 9, 10, 11, 12 | RTC ✓ (réveil EXT1 any-high) |
| Jauge batterie (ADC) | 13 | ADC2 — OK car WiFi jamais actif |
| ~~Détection VBUS~~ → **CS écran (net `CS_DPL`)** | 14 | VBUS_DET abandonné (2026-07-31) ; CS dédié, actif HAUT — câblé ✓ |
| UART lien TX / RX | 17 / 18 | — |
| USB D− / D+ | 19 / 20 | pins USB natifs (fixe) |
| EN du load switch 5 V (poignée de main) | 21 | — |
| nRF24 : CE / CSN | 15 / 16 | libres, hors strapping |
| SPI partagé nRF24+LCD : SCK / MOSI+SI / MISO / IRQ | 38 / **40** / 39 / 41 | GPIO matrix ; MOSI/MISO tels que dessinés par Mae ; le LCD (write-only) partage SCK et MOSI |
| TP_RDY (trackpad, gauche) | **42** | plus de partage — le CS écran a son pin dédié (14) ; CS LCD actif HAUT |
| Trackpad I2C : SDA / SCL (gauche) | **47 / 48** | ex-lien UART S3↔P4, abandonné (2026-07-30) |
| Boot / prog (J_PROG) | 0, 43, 44 | strapping — pull-up 10k sur 0 |
| Interdits | 3, 45, 46 (strapping), 35-37 (PSRAM octale), 33/34 (absents du module) | |

**Périphériques (décisions 2026-07-30)** : écran **Sharp LS011B7DH03** à droite (SCS=42 actif haut,
SCLK=38, SI=40, DISP→3V3, EXTMODE/EXTCOMIN→GND, VCOM logiciel) ; trackpad **Azoteq TPS43-201A-S**
à gauche (FPC 6-pin : RDY=42, NRST=RC pull-up+100nF, SDA=47, SCL=48) ; **le S3 est PLEIN** —
« batterie pleine » se lit via VBAT_SENSE en ADC (≥ ~4,15 V), pas de GPIO pour STDBY.
**Restructure Mae** : matrice gauche déplacée DANS la feuille s3 (câblage direct SW→100R→MCU,
nets anonymes) ; la feuille Matrix ne porte plus que la droite (`col*_d`/`row*_d`, en attente du 2ᵉ MCU).

---

### Tâche 0 : Scaffold du projet + bascule tripwire

**Fichiers :**
- Créer (Mae, GUI) : `rouge-gorge/rouge-gorge.kicad_pro`, `.kicad_sch`, `.kicad_pcb`
- Modifier (Claude) : `scripts/kicad-check.sh` (cibles SCH/PCB), `CLAUDE.md` (chemins surveillés déjà OK : `rouge-gorge/` n'y est pas → l'ajouter), `.tripwire-kicad-baseline` (reset)

**Interfaces :** produit le squelette de projet + 4 feuilles hiérarchiques vides nommées `alim`, `mcu_radio`, `matrice`, `liens` que les tâches 1-4 remplissent.

- [ ] **Étape 1 (Mae)** : KiCad → Fichier → Nouveau projet → `rouge-gorge/rouge-gorge` à la racine du repo. Dans le schéma racine, poser UNE feuille hiérarchique (Placer → Feuille) : `moitie.kicad_sch`, nommée `gauche`. Entrer dans `moitie` et y poser les 4 feuilles : `alim.kicad_sch`, `mcu_radio.kicad_sch`, `matrice.kicad_sch`, `liens.kicad_sch`. (La 2ᵉ instance `droite` de `moitie` sera posée en Tâche 5, une fois l'instance unique verte.) Recopier les tables de libs : Préférences → Gérer les librairies de symboles/empreintes → ajouter (projet) `mae.kicad_sym`, `rouge_gorge.kicad_sym` et les `.pretty` de `hardware/pcb/` utiles (`key`, `MaeLid`, `EKR82-footprint`). Sauvegarder.
- [ ] **Étape 2 (Claude)** : retarget `scripts/kicad-check.sh` : `SCH="rouge-gorge/rouge-gorge.kicad_sch"`, `PCB="rouge-gorge/rouge-gorge.kicad_pcb"` ; supprimer `.tripwire-kicad-baseline` (la baseline se ré-initialise au premier run) ; ajouter `rouge-gorge/` à la puce chemins surveillés de CLAUDE.md.
- [ ] **Étape 3 (vérif)** : `./scripts/check.sh --fast` → vert, baseline ré-initialisée à ~0/0 (schéma quasi vide). `./scripts/check.sh` → DRC : le PCB vide initialisera sa référence (probablement 1 erreur `invalid_outline` — c'est la référence de départ, elle fondra au layout).
- [ ] **Étape 4 (commit)** : `git add rouge-gorge/ scripts/kicad-check.sh CLAUDE.md .tripwire-kicad-baseline && git commit -m "feat(v2): projet KiCad rouge-gorge + bascule tripwire"`

### Tâche 1 : Feuille `alim` — 16340 → système

**Fichiers :** Modifier (Mae) : `rouge-gorge/alim.kicad_sch`

**Interfaces :** produit les nets `+BATT` (cellule), `VSYS` (aval load-sharing), `+3V3` (sortie MCP1700), `VBUS_5V` (entrée USB), `VBAT_SENSE` (vers GPIO13), `GND`. Consomme `VBUS_5V` de la feuille `liens`.

Chaîne complète et valeurs :

```
16340 (+) ─ B+ ─┬─ DW01A(+FS8205 dual-FET) protection ─ +BATT
                │    DW01A : VCC via R 100Ω + C 100nF ; CS via R 1kΩ ; FS8205 entre B− et GND
+BATT ─┬─ TP4056 (BAT) ← VBUS_5V (VCC, C 10µF)   Rprog = 2,4 kΩ → ~500 mA
       │    TEMP→GND (désactivé) ; CE→VCC ; CHRG → LED rouge + R 1 kΩ vers VBUS_5V
       └─ Q1 AO3407 (P-FET, load sharing) ─ VSYS
            gate Q1 → VBUS_5V via R 10k (VBUS présent = FET bloqué)
VBUS_5V ─ D1 Schottky SS14 ─ VSYS        (câble branché : le système mange le 5 V… via 3V3)
VSYS ─ SW1 slide MSK-12C02 (coupure côté système) ─ MCP1700-3302E/TT ─ +3V3
            MCP1700 : Cin 1µF, Cout 1µF céramique
+BATT ─ R 1M ─┬─ R 1M ─ GND   (jauge)    ┬ = VBAT_SENSE, + C 100nF vers GND
```

- [x] **Étape 1 (Claude)** : liste de courses livrée (2026-07-29, réfs LCSC vérifiées en ligne, symboles vérifiés dans les libs KiCad 10 installées) — voir annexe « Liste de courses feuille alim » en fin de plan. Symbole `FS8205` créé dans `hardware/pcb/rouge_gorge.kicad_sym` (absent des libs officielles ; pinout SOT23-6 vérifié sur datasheet Fortune).
- [ ] **Étape 2 (Mae)** : dessiner la feuille selon la chaîne ci-dessus, netlabels exactement `+BATT`, `VSYS`, `+3V3`, `VBUS_5V`, `VBAT_SENSE`. PWR_FLAG sur `+BATT` et `VBUS_5V`. Sauvegarder.
- [ ] **Étape 3 (vérif)** : `./scripts/check.sh --fast` → vert (0 erreur ; le ratchet reste 0). Claude relit `alim.kicad_sch` (texte) et recoupe chaque net contre la chaîne ci-dessus — écarts signalés, corrigés, re-check.
- [ ] **Étape 4 (commit)** : `git add rouge-gorge/ .tripwire-kicad-baseline && git commit -m "feat(v2): feuille alim — 16340, protection, charge 500mA, load-sharing, MCP1700"`

### Tâche 2 : Feuille `mcu_radio` — S3-MINI-1 + nRF24

**Fichiers :** Modifier (Mae) : `rouge-gorge/mcu_radio.kicad_sch`

**Interfaces :** consomme `+3V3`, `GND`, `VBAT_SENSE`, `VBUS_5V` (via diviseur → `VBUS_DET`). Produit : `ROW0..ROW3`, `COL0..COL6` (vers `matrice`), `USB_DP`/`USB_DM`, `LINK_TX`/`LINK_RX`, `LINK_5V_EN` (vers `liens`).

Contenu (voir carte des pins en tête de plan — elle est normative) :

- `RF_Module:ESP32-S3-MINI-1` (déjà dans ton brouillon s3.kicad_sch — le reprendre). Découplage : C 10µF + 2× C 100nF sur 3V3.
- EN : R 10k vers +3V3 + C 1µF vers GND. GPIO0 : R 10k vers +3V3.
- **Connecteur de prog `J_PROG` 6 pins par moitié** (décision Mae 2026-07-29, remplace les pads TP_BOOT/TP_TX0/TP_RX0) — brochage ESP-Prog : 1=EN, 2=3V3, 3=TX0 (GPIO43), 4=GND, 5=RX0 (GPIO44), 6=IO0 (GPIO0). Symbole `Conn_02x03_Odd_Even` ou `Conn_01x06` ; « zéro header » réglé au layout (bas profil / pads / Tag-Connect).
- Détection VBUS : `VBUS_5V ─ R 100k ─┬─ R 100k ─ GND`, ┬ = net `VBUS_DET` → GPIO14, + C 100nF.
- `VBAT_SENSE` → GPIO13.
- nRF24 : symbole `RF:NRF24L01_Breakout` (celui de KaSe V2), connecteur 2×4 femelle bas profil ou soudé à plat — empreinte au layout. Alim module : C 10µF + 100nF au plus près. CE/CSN/MOSI/SCK/MISO/IRQ → GPIO 33/34/35/36/37/38.
- Netlabels de sortie : `ROW0..3`, `COL0..6`, `USB_DP` (GPIO20), `USB_DM` (GPIO19), `LINK_TX` (17), `LINK_RX` (18), `LINK_5V_EN` (21).

- [ ] **Étape 1 (Mae)** : dessiner ; sauvegarder.
- [ ] **Étape 2 (vérif)** : `./scripts/check.sh --fast` vert + revue texte Claude (chaque GPIO contre la carte des pins — c'est LA revue critique du projet : une matrice hors RTC = réveil cassé, découvert au firmware).
- [ ] **Étape 3 (commit)** : `git commit -m "feat(v2): feuille mcu_radio — S3-MINI-1, nRF24, pinout RTC"` (avec `git add rouge-gorge/ .tripwire-kicad-baseline`).

### Tâche 3 : Feuille `matrice` — 26 touches hybrides

**Fichiers :** Modifier (Mae) : `rouge-gorge/matrice.kicad_sch`

**Interfaces :** consomme `ROW0..3`, `COL0..6`. Rien d'autre ne la touche.

- 26 × (`SW_Push` + diode **1N4148W SOD-123 SMD**). Convention : ROW (sortie) → switch → diode → COL, **cathode côté colonne** (scan rows-drive + réveil EXT1 cohérents).
- **R 100Ω série sur chacune des 11 lignes** (4 ROW + 7 COL), côté MCU (couche 3 du plan ESD) — placées sur cette feuille, entre le netlabel entrant et le peigne de la matrice ; les nets côté touches s'appellent `ROW0_SW..`/`COL0_SW..`.
- Grille électrique 4×7 = 28 positions, 26 peuplées (2 libres en réserve). L'affectation physique des touches (layout, mix MX/Choc) est une décision de layout — ici seule l'électricité compte.
- Empreintes hybrides MX/Choc existantes (`EKR82-footprint`) assignées au layout, pas maintenant.

- [ ] **Étape 1 (Mae)** : dessiner (astuce : dessiner 1 cellule switch+diode propre, puis répéter/coller en grille 4×7).
- [ ] **Étape 2 (vérif)** : `./scripts/check.sh --fast` vert + revue texte Claude (26 diodes, orientation, 11 résistances série, nets `_SW`).
- [ ] **Étape 3 (commit)** : `git commit -m "feat(v2): feuille matrice — 4x7, diodes SOD-123, 100R ESD série"`.

### Tâche 4 : Feuille `liens` — USB-C, lien inter-moitiés, ESD

**Fichiers :** Modifier (Mae) : `rouge-gorge/liens.kicad_sch`

**Interfaces :** consomme `USB_DP/DM`, `LINK_TX/RX`, `LINK_5V_EN`, produit `VBUS_5V`.

- **USB-C** (USB 2.0, 16 pads, ex. HRO TYPE-C-31-M-12) : CC1 et CC2 → R 5,1k vers GND chacune ; VBUS → net `VBUS_5V` ; D+/D− → **USBLC6-2SC6** (à 2 mm du connecteur au layout) → `USB_DP`/`USB_DM` ; SHIELD → GND via R 1M ∥ C 100nF.
- **Lien inter-moitiés `J_LINK`** : symbole `Connector_Generic:Conn_01x04` — brochage normatif : 1=GND, 2=LINK_RX, 3=LINK_TX, 4=LINK_5V. (Empreinte TRRS MJ-4PP-9 et/ou magnétique 4P : au layout, double empreinte possible — point ouvert №2.)
- **Poignée de main 5 V** : `VBUS_5V → U_LS AP22802AW5-7 (load switch, courant limité) → LINK_5V`, EN ← `LINK_5V_EN` + R 100k pull-down (mort par défaut). **Et le chemin retour** : `LINK_5V → D2 Schottky SS14 → VBUS_5V` (la moitié non branchée est nourrie par sa sœur : son TP4056 charge, son VBUS_DET monte — même mécanique que le câble).
- **ESD lien** : **SRV05-4** (SOT-23-6) sur les 4 lignes du J_LINK, au plus près du connecteur. R 100Ω série sur LINK_TX et LINK_RX (côté MCU).
- Le slide switch et le TP4056 étant sur `alim`, cette feuille ne produit que `VBUS_5V` — un seul PWR_FLAG (déjà posé en alim).

- [ ] **Étape 1 (Mae)** : dessiner ; sauvegarder.
- [ ] **Étape 2 (vérif)** : `./scripts/check.sh --fast` vert + revue texte Claude (sens du load switch, pull-down EN, diode retour, TVS sur les 4 lignes).
- [ ] **Étape 3 (commit)** : `git commit -m "feat(v2): feuille liens — USB-C, J_LINK poignée de main 5V, TVS"`.

### Tâche 5 : Racine, ERC zéro, clôture

**Fichiers :** Modifier (Mae) : `rouge-gorge/rouge-gorge.kicad_sch` (racine) ; Modifier (Claude) : design doc (§ statut), plan (cases cochées)

- [ ] **Étape 1 (Mae)** : câbler les 4 feuilles à l'intérieur de `moitie` (pins hiérarchiques : `+3V3`, `GND`, `VBUS_5V`, `ROW/COL`, `USB_*`, `LINK_*`, `VBAT_SENSE`, `VBUS_DET`), puis poser la **2ᵉ instance** de `moitie.kicad_sch` à la racine (Placer → Feuille, même fichier, nom `droite`), annotation complète des deux instances (Outils → Annoter — les refs se dédoublent automatiquement), attribution des empreintes différée au layout SAUF celles déjà fixées (MCP1700 SOT-23, diodes SOD-123, TVS SOT-23-6/SOT-143, AO3407 SOT-23, TP4056 SOP-8, USB-C, MSK-12C02).
- [ ] **Étape 2 (vérif finale)** : `./scripts/check.sh` complet → **ERC 0 erreur / 0 warning visé** (les warnings restants se justifient un par un ou s'éliminent) ; baseline committée à son plancher.
- [ ] **Étape 3 (Claude)** : revue texte intégrale du projet (cohérence inter-feuilles des netlabels — le point faible classique des hiérarchies) + mise à jour du design doc (« schéma moitiés : FAIT »).
- [ ] **Étape 4 (commit)** : `git commit -m "feat(v2): schéma moitiés complet — ERC 0"` puis relecture d'ensemble par Mae dans KiCad avant d'attaquer le layout.

---

## Annexe — Liste de courses feuille `alim` (livrée 2026-07-29, réfs LCSC vérifiées)

| # | Composant | Boîtier | Symbole KiCad | LCSC | Note |
|---|---|---|---|---|---|
| 1 | DW01A (protection cellule) | SOT-23-6 | `Battery_Management:DW01A` ✓ officiel | C351410 (PUOLOP) | alt. C2927799 (YONGYUTAI) |
| 2 | FS8205 (dual N-FET, paire du DW01A) | **SOT23-6** | `rouge_gorge:FS8205` (créé, pinout 1=S1 2=D12 3=S2 4=G2 5=D12 6=G1) | C32254 (Fortune) | alt. TSSOP-8 FS8205A C16052 ; VGS(th) 0,45-1,2 V OK pour DW01A |
| 3 | TP4056 (chargeur, Rprog 2,4 kΩ → ~500 mA) | ESOP-8 | `Battery_Management:TP4056-42-ESOP8` ✓ officiel | C16581 (TOPPOWER) | pad thermique dessous |
| 4 | AO3407 (P-FET load sharing) | SOT-23 | `Transistor_FET:AO3401A` (même pinout G/S/D, mettre Value=AO3407) | C351408 (PUOLOP) | alt. C727158 (TWGMC, RDS 87 mΩ) |
| 5 | SS14 (Schottky VBUS→VSYS) | SMA | `Diode:SS14` ✓ officiel | C2480 (MDD) | générique multi-fab |
| 6 | MCP1700-3302E/TT (LDO 3,3 V 250 mA, 1,6 µA) | SOT-23 | `Regulator_Linear:MCP1700x-330xxTT` ✓ officiel | C39051 (Microchip) | |
| 7 | MSK-12C02 (slide switch coupure système) | SMD | `Switch:SW_SPDT` générique | C431540 (SHOU HAN) | empreinte au layout |
| 8 | R/C du bloc | 0603 sugg. | `Device:R`, `Device:C` | basic parts | 100Ω, 1k, 2,4k, 10k, 2×1M ; 100nF ×3, 1µF ×2, 10µF ×2 |
| 9 | Cellule 16340 (contacts/holder) | — | `Device:Battery_Cell` | — | contact ressort vs holder = décision layout (design doc) |

Composants `liens` déjà repérés au passage (Tâche 4) : `Power_Protection:USBLC6-2SC6` ✓, `Power_Protection:SRV05-4` ✓, `Connector:USB_C_Receptacle_USB2.0_16P` ✓, `Diode:1N4148W` ✓ (matrice), load switch : `SiP32431DR3` ✓ officiel (l'AP22802 n'a pas de symbole officiel — SiP32431 était l'alternative validée au design doc).

## Annexe — Liste de courses BOM complète v2 (2026-08-01, réfs LCSC vérifiées en ligne)

Complète l'annexe alim ci-dessus (DW01A, FS8205, TP4056, AO3407, SS14, MCP1700, MSK-12C02 déjà référencés). Quantités pour LE PANNEAU (2 moitiés) :

| Qté | Composant | Boîtier | LCSC | Note |
|---|---|---|---|---|
| 2 | ESP32-S3-WROOM-1-**N8R2** | module CMS | **C2913204** | ⚠️ l'empreinte au schéma est `WROOM-1U` (antenne externe u.FL) — si c'est voulu, prendre le 1U-N8R2 **C3013944** ; sinon corriger l'empreinte vers WROOM-1 (antenne PCB, reco clavier) et prendre C2913204 |
| 1 | CH334R (hub USB 2.0 4 ports) | QSOP-16 | **C4154405** | ~0,30 $ |
| 2 | USBLC6-2SC6 (ESD USB) | SOT-23-6 | **C7519** (ST) | éviter les clones à 2 lettres près |
| 2 | SRV05-4 (ESD TRRS) | SOT-23-6 | **C13612** (Semtech .TCT) | alt. budget : Leiditech C384887, Bourns C118757 |
| 1 | AMS1117-3.3 (LDO coffre P4) | SOT-223 | **C6186** (AMS) | |
| 2 | SiP32431DR3-T1GE3 (load switch 5 V lien) | SC-70-6 | **C141606** (Vishay) | |
| 2 | USB-C TYPE-C-31-M-12 (16P, USB 2.0) | CMS + 4 pattes | **C165948** (HRO) | = exactement l'empreinte `USB_C_Receptacle_HRO_TYPE-C-31-M-12` du schéma |
| 1 | microSD Würth 693072010801 (hinge) | CMS | — PAS sur LCSC | Mouser/Farnell/DigiKey ; alt. LCSC push-push TF-01A **C91145** (HRO) mais il faudra CHANGER l'empreinte avant routage |
| 2 | nRF24L01+ (module breakout 2×4) | module | — AliExpress | comme v1 ; empreinte `MaeLid:NRF24L01` |
| 1 | Module ESP32-P4 `JC-ESP32P4-M3` | module | — AliExpress/Taobao | empreinte V0.2 déjà sur le PCB |
| 2 | Écran Sharp LS011B7DH03 | FPC | — Mouser/DigiKey | 1 monté à droite (populate-per-half) |
| 1 | Trackpad Azoteq TPS43-201A-S | FPC 6 pin ZIF | — Mouser/DigiKey | gauche seulement + connecteur ZIF 6P 0,5 mm à référencer au layout |
| 52+4 | Switchs Choc/MX + diodes matrice + jack TRRS MJ-4PP-9 | — | — AliExpress | filière v1 (README) ; diodes matrice hors BOM kicad (symboles legacy) |
| ~60 | R/C/LED 0603-0805-1206 (100Ω, 100k, 10k, 1k, 2k4, 4,7k, 5k1, 1M ; 100nF, 1µF, 10µF, 22µF ; LED 0805) | 0603/0805/1206 | basic parts JLC | prendre les « Basic » du catalogue pour éviter les frais extended si assemblage JLC |

## Auto-revue du plan (faite)

- **Couverture du spec** : §4 alim ✓ (T1) ; §2 cœur S3 + nRF24 ✓ (T2) ; matrice/ULP ✓ (carte des pins + T3) ; §5 lien poignée de main ✓ (T4) ; §6 ESD couches 1-3 ✓ (T1/T3/T4 ; couche 0 = layout, hors plan) ; §7 zéro header ✓ (contraintes globales) ; coffre/§8 exclus explicitement (points ouverts) ; §10 tripwire ✓ (T0 + chaque tâche).
- **Placeholders** : les réfs LCSC exactes des composants sont livrées à la Tâche 1 Étape 1 (dépendance stock/dispo du jour — donnée externe, pas un TBD de conception).
- **Cohérence des noms** : nets normatifs définis une fois (interfaces de tâche) et réutilisés à l'identique ; carte des pins unique en tête.

## Annexe — Brochage matrice RÉEL et conventions firmware (revue 2026-08-06, source netlist)

La carte des pins « normative » ci-dessus reste valable pour tout SAUF la matrice : Mae a
permuté rows/cols au routage (liberté actée — tout reste en GPIO1-12, domaine RTC, réveil
EXT1 possible). **Le firmware doit porter DEUX tables** :

| ligne | GAUCHE (U6) | DROITE (U5) |
|---|---|---|
| row0 | GPIO1 | GPIO2 |
| row1 | GPIO2 | GPIO12 |
| row2 | GPIO8 | GPIO4 |
| row3 | GPIO6 | GPIO5 |
| col0 | GPIO4 | GPIO6 |
| col1 | GPIO5 | GPIO7 |
| col2 | GPIO7 | GPIO8 |
| col3 | GPIO9 | GPIO9 |
| col4 | GPIO10 | GPIO11 |
| col5 | GPIO11 | GPIO10 |
| col6 | GPIO12 | GPIO1 |

Conventions actées :
- **Sens de scan** : chaîne réelle COL→SW→anode-diode-cathode→ROW. Le firmware PILOTE les
  colonnes et LIT les rows ; le réveil sommeil profond (EXT1) s'arme sur les ROWS.
- **TRRS** : câble droit, R1↔R1/R2↔R2 → TX arrive sur TX. Le croisement est fait en
  FIRMWARE (matrice GPIO : une moitié échange U1TXD/U1RXD). Ne jamais activer les deux TX
  push-pull sans ce swap (contention limitée par les 2×100Ω, mais contention quand même).
- **Tip TRRS** protégé par le canal 3 du SRV05 (net TIP_5V) depuis la revue.
- **microSD du coffre** : cartes insérées/retirées HORS TENSION uniquement (décision Mae
  2026-08-06 — pas de TVS sur les lignes SD). Card-detect absent (connecteur Würth) :
  détection logicielle par polling CMD.
- **LDO moitiés = HT7833** (SOT-89 : 1=GND 2=VIN 3=VOUT) depuis la revue ; CH334R en mode
  sans quartz avec R48/R49 SUPPRIMÉS par Mae (RESET# a un pull-up interne 25k).
- Jauge batterie sur ADC2_CH2 : ADC2 inutilisable si le WiFi est actif (nRF24-only : OK).

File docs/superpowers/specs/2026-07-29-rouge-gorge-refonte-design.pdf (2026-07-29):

# Rouge-Gorge v2 — Design de la refonte

2026-07-29 · BROUILLON — sections en attente de validation par Mae · 3 points ouverts · toutes décisions : Mae

### 1. Le produit

Un clavier split petit, bas et durable, full wireless, qui est aussi une trousse de secours d'informaticien. C'est UN produit avec DES modes — pas des variantes :

Mode | Déclencheur | Comportement
Sans-fil | pas de câble (VBUS absent) | Clavier pur et sobre : frappes → nRF24 → dongle KaSe. USB, SD, C6 éteints. Veille en µA.
Filaire | câble USB branché (VBUS présent) | Multi-outil : clavier USB HID direct (boot protocol, utilisable au BIOS) + coffre (stockage bootable, token PGP) + recharge. Alimenté par le câble.

Bascule automatique par détection VBUS : « rebrancher doit suffire ». Le système = deux moitiés + le dongle, pas de troisième objet. Disparaissent de l'ancien design : ProMicro, LEDs SK6812, OLED, headers.

### 2. Architecture système

┌──────────── moitié G ────────────┐ | ┌──────────── moitié D ────────────┐
│ ESP32-S3 (cœur clavier) | │ | │ ESP32-S3 (cœur clavier) | │
│ · matrice (scan ULP en sommeil) │ | │ · matrice (scan ULP en sommeil) │
│ · nRF24L01+ (SPI) | 16340 ▭ │ | │ · nRF24L01+ (SPI) | 16340 ▭ │
│ · USB-C (HID + charge) | │◄─lien─►│ · USB-C (HID + charge) | │
└───────────────┬──────────────────┘ filaire└──────────────┬───────────────────┘
│ nRF24 ESB (protocole KaSe) | │
▼ | | ▼
┌─────────────────── dongle KaSe (ESP32-S3, 2 radios) ────────────────┐
│ USB HID vers l'hôte · hub CH334R | │
│ [OUVERT] coffre P4 greffé derrière le hub ? | │
└─────────────────────────────────────────────────────────────────────┘

Cœur de chaque moitié : ESP32-S3 (module WROOM soudé à plat) — rôle HID-seul + radio, le rôle exact du « smart keyboard » KaSe déjà éprouvé (routage usb_presence , relais nRF24, pairing). Sleep archi-connu (~7 µA deep / ~240 µA light) ; ULP-RISC-V scanne la matrice en sommeil sans perdre la première frappe.
Coffre : module JC-ESP32P4-M3 (stock) — USB 2.0 haute vitesse + digital signature peripheral + key management unit. Il porte le stockage et le token PGP.

[OUVERT №1 — la maison du coffre] : (D) greffé derrière le CH334R du dongle — révision du dongle ; moitiés pures et plates ; P4 alimenté par l'hôte, conso hors équation ; « une prise = clavier + ISO + identité » au BIOS — ou (C) en mezzanine dans le volume du tube 16340 d'une moitié (autonome, mais surface/volume dans l'objet le plus contraint). Donnée qui tranche : port libre/récupérable sur le CH334R du dongle, dongle révisable ?

Leçon fondatrice (échec vécu : composite HID+PGP sur le S3 du dongle → clavier qui lague) : l'important et l'accessoire ne partagent jamais un même device USB. D'où le hub (CH334R, USB2 HS, facile à souder — éprouvé par Mae) et les siliciums séparés.

### 3. Modes & stabilité — « le clavier est là coûte que coûte »

Étage | Mécanisme | Garantie
0 | Matrice scannée par l'ULP du S3 | une frappe est toujours captée
1 | Deux chemins vers l'hôte sur siliciums séparés : USB direct / radio→dongle | la panne d'un chemin n'emporte pas l'autre
2 | Features sacrifiables ; boot clavier-d'abord, features après | un crash de feature redémarre la feature, pas le clavier
3 | Watchdog matériel + brown-out | pire cas : clignement < 1 s, auto-réparé

L'isolation absolue sur un même chip n'existe pas ; la garantie du produit : aucune panne de feature ne prive le PC des frappes plus d'une seconde. En mode filaire, la radio peut rester en veille chaude comme chemin de secours (le câble paie le courant).

### 4. Alimentation

Cellule : 16340 (~700 mAh) en tube le long d'un bord du PCB — corps bas, bosse = cylindre assumé en bordure (arrière = tilt naturel ; bord exact à dessiner). Cellules souvent non

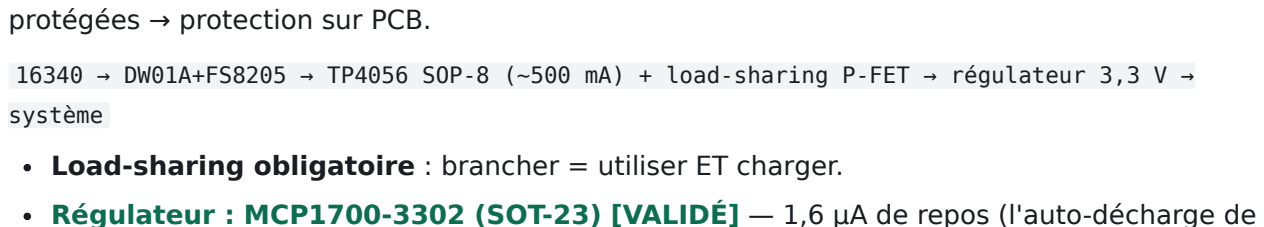
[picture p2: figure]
protégées → protection sur PCB.; système

16340 → DW01A+FS8205 → TP4056 SOP-8 (~500 mA) + load-sharing P-FET → régulateur 3,3 V →

Load-sharing obligatoire : brancher = utiliser ET charger.
Régulateur : MCP1700-3302 (SOT-23) [VALIDÉ] — 1,6 µA de repos (l'auto-décharge de la cellule fuit ~20× plus), 250 mA, soudable au fer, banal. Conséquence assumée : radio WiFi/BLE du S3 jamais utilisée (pics 350-500 mA hors budget) — lien = nRF24, mises à jour = USB. Coût vs buck-boost : ~3-4 jours d'autonomie par cycle.
Jauge : diviseur haute impédance → ADC → champ batt_dV du heartbeat KaSe (déjà au protocole).
Interrupteur : slide mécanique (MSK-12C02), coupure côté système [VALIDÉ] — charge possible clavier éteint (~3 µA résiduels), état visible, zéro firmware, encastré dans le chant. Raison d'être : le transport (touches martelées en sac = réveils + retries radio), pas la veille.
Budget ~50-80 mAh/jour → 1 à 3 semaines d'autonomie.

### 5. Lien inter-moitiés (mode filaire uniquement)

En sans-fil, les moitiés ne se parlent pas (chacune → dongle). Le lien ne sert qu'au fallback filaire. 4 lignes : GND, UART croisé, 5 V commuté.

Décision : 5 V « en poignée de main » — contact d'alim mort par défaut ; après reconnaissance UART, la moitié nourrie au câble ferme un load switch intégré (classe AP22802/SiP32431 : limitation de courant + soft-start) et envoie le 5 V, qui recharge la moitié d'en face. Le court-circuit de branchement à chaud devient physiquement impossible — la réponse définitive au tueur historique de splits.

[OUVERT №2 — le connecteur] : jack TRRS (banal, câble remplaçable partout ; mais raclage à l'insertion, vulnérable à l'arrachage) vs magnétique pogo (hot-plug sûr mécaniquement, se détache au lieu de casser, ~3 mm de haut ; mais câble propriétaire — candidat AliExpress trouvé, specs à relever : ≥ 4 contacts, ≥ 0,5-1 A, forme embase/câble, détrompage). Option protos : double empreinte, l'usage tranche.

### 6. ESD — l'exigence historique

Scénario à tuer : l'utilisateur revient chargé de quelques kV, touche le clavier → plantage jusqu'au débranchage. Défense en couches :

Couche | Mesure | Note
0 · paratonnerre | plans de masse cousus de vias ; vis sur pads GND ; plaque (alu de préférence) reliée à GND | le châssis avale la décharge avant les pistes
1 · douaniers | TVS à 2 mm de chaque connecteur : USBLC6-2 (USB-C), array 4 lignes type SRV05-4 (lien inter-moitiés), array SD si slot exposé | ~1 €, trois boîtiers
2 · organes vitaux | CHIP_PU / boot : RC + pistes courtes (+ TVS si près d'un connecteur) | la ligne qui fait « planté sans reset »
3 · matrice | ~100 Ω série sur les 11 lignes | les clamps internes digèrent le résidu
4 · curatif | hiérarchie de stabilité (§3) | décharge exotique = clignement, pas une mort

Surcoût ≈ 2 €, zéro épaisseur. L'ancien design comptait 199 violations de cuivre en bord de PCB (amorçages potentiels) — éradication en cours, mesurée par la baseline tripwire.

### 7. Mécanique

La leçon des claviers précédents : le PCB trop haut casse les boîtiers — coupable : le ProMicro sur headers (12-14 mm sous PCB). Règles v2 :

Zéro header. Tout SMD à plat ; modules en découpe de PCB si besoin ; USB-C mid-mount ; le connecteur inter-moitiés peut vivre côté touches sous la plaque (5 mm d'air en MX). Dégagement sous PCB ≈ 3,5 mm (plancher = sockets hotswap 1,9 mm ; modules 3,2-3,4 mm).
Construction sandwich : plaque + entretoises + fond, vis en compression pure — plus de coque imprimée qui fend. Plaque alu = collecteur ESD en bonus.
Switches : mix MX/Choc par position (footprints hybrides existants) — la hauteur du case suit le plus haut des deux.
Le tube 16340 en bordure est le seul relief ; il peut porter le tilt.

### 8. USB filaire — la trousse de secours

Une prise branchée au BIOS d'une machine quelconque donne :

Le clavier : HID boot protocol (dialecte BIOS) depuis le S3 de la moitié branchée — ou depuis le dongle.
Le médium d'installation : le coffre P4 expose la SD en MSC (SDIO 4 bits, ~20-40 Mo/s — classe « bonne clé USB 2 », largement de quoi booter/installer). Multi-ISO par Ventoy sur la SD : firmware = MSC bête, collection d'ISO gérée par glisser-déposer. Volume « config » possible sur la flash 16 Mo (keymap en fichier éditable).
L'identité : token PGP sur le silicium crypto du P4 (DS peripheral + KMU : clé privée jamais lisible par le firmware ; secure boot + flash encryption). Confirmation de présence par appui-touche — le clavier a déjà les boutons.
Mode lecture seule (switch ou bascule) : clé de secours inviolable sur machine douteuse. Débit et latence cohabitent : le HID (8 ko/s, endpoints interrupt réservés par le protocole USB) est intouchable par le bulk ; le plafond réel est la SD, pas le hub CH334R.
La SD est coupée électriquement en sans-fil (transistor commandé par VBUS) : zéro fuite batterie.

### 9. Radio

nRF24L01+ du stock, posés à plat (découpe PCB), protocole KaSe intact : ESB 1 Mbps, CRC 16, adresses 5 o, DPL, ARC 15/ARD 500 µs ; trames PKT_KEY / PKT_HEARTBEAT (bitmap 5×7, batt_dV, link_q).
Pairing runtime KaSe (canal 40, set_id dérivé du MAC dongle, canaux 80-119) : isolation Rouge-Gorge / claviers KaSe voisins résolue par construction.
Rouge-Gorge occupe les 2 slots d'un dongle → dongle dédié.
Plus tard, optionnel : canal ESP-NOW « info » via le C6 du module P4 (antenne IPEX déjà sur le module) — coût hardware nul aujourd'hui.

### 10. Chantier & validation

Tripwire : la baseline ERC/DRC mesure la fonte des violations pendant la refonte — objectif zéro à la fin. Arbre rouge en pleine chirurgie = normal ; push WIP : --no-verify .
Si coffre en moitié (C) : manip « composite sous charge » sur carte porteuse P4 obligatoire avant routage (leçon S3 : on ne croit plus le papier, on mesure). Si coffre au dongle (D) : la manip disparaît, chaque micro n'a qu'un rôle.
Ordre des protos : PCB des moitiés d'abord (le cœur ne dépend d'aucun point ouvert) ; la maison du coffre se décide en parallèle.
Après validation : plan d'implémentation détaillé (schéma → layout → case), puis firmware (hors périmètre de ce document).

### Points ouverts (récapitulatif)

### 1. Maison du coffre P4 — dongle révisé (D) vs mezzanine dans la bosse (C). Donnée

décisive : port libre sur le CH334R, dongle révisable ?

### 2. Connecteur inter-moitiés — TRRS vs magnétique pogo (specs du candidat AliExpress

à relever) ; option double empreinte sur protos.

### 3. Micro-choix de schéma restants — bord du tube 16340 et contacts cellule, layout

final des touches. (Régulateur et interrupteur : tranchés, voir §4.)

Rouge-Gorge v2 · design brainstormé et décidé par Mae · document généré le 2026-07-29 · source : docs/superpowers/specs/2026-07-29-rouge-gorge-refonte-design.md

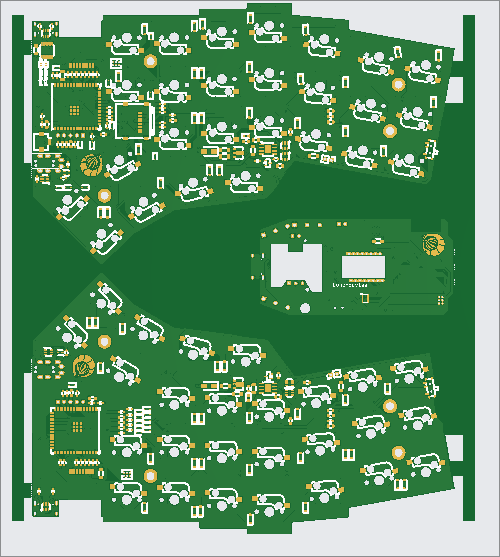
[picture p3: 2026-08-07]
hardware/kit-panneau/Pasted image.png

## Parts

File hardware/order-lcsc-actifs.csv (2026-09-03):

LCSC Part Number | Quantity | Description | Package | Niphargus | Conchodytes | Besoin | Notes
C81598 | 100 | 1N4148W diode de matrice | SOD-123 | 52 | 0 | 52 | D1-D48 + U1-U4 (ces 4 sont des diodes malgre leur reference en U)
C2827707 | 30 | SD05C-01F TVS unidirectionnelle | SOD-323 | 22 | 0 | 22 | protection ESD des lignes de matrice
C2480 | 6 | SS14 Schottky 1A 40V | SMA | 2 | 1 | 3 | chemin USB / batterie
C16581 | 6 | TP4056-42-ESOP8 chargeur Li-ion | SOIC-8-1EP | 2 | 1 | 3
C50936 | 6 | HT7833 LDO 3.3V 500mA | SOT-89-3 | 2 | 1 | 3 | PIEGE : brochage 1=GND 2=VIN 3=VOUT, PAS celui du MCP1700 SOT-23
C351410 | 6 | DW01A protection de cellule | SOT-23-6 | 2 | 1 | 3 | va par paire avec le FS8205
C32254 | 6 | FS8205 double MOSFET de protection | SOT-23-6 | 2 | 1 | 3 | va par paire avec le DW01A
C351408 | 6 | AO3407 P-MOSFET load-share | SOT-23 | 2 | 1 | 3
C7519 | 6 | USBLC6-2SC6 TVS USB | SOT-23-6 | 2 | 1 | 3
C13612 | 5 | SRV05-4 TVS 4 lignes | SOT-23-6 | 2 | 0 | 2 | TRRS ; alternative budget Leiditech C384887
C141606 | 5 | SiP32431DR3 load switch | SOT-363 SC-70-6 | 2 | 0 | 2 | poignee de main 5V du lien TRRS
C4154405 | 3 | CH334R hub USB 2.0 | QSOP-16 | 1 | 0 | 1 | WCH - introuvable hors Chine
C6186 | 3 | AMS1117-3.3 LDO du coffre P4 | SOT-223-3 | 1 | 0 | 1
C20612443 | 2 | PMW3360DM-T2QU capteur optique | DIP-16 optique | 0 | 1 | 1 | A VERIFIER : code releve sur lcsc.com, pas dans le schema. Lentille LM19-LSI a commander a part
C2891260 | 5 | XC6206P202MR-G LDO 2.0V 120mA | SOT-23 | 0 | 1 | 1 | REMPLACE le 1.8V : 1.80 est le MINIMUM datasheet (typ 1.90, max abs 2.10). 2.0V +-2% = 1.96-2.04, dans la plage. ATTENTION : brochage SOT-23 du XC6206 = 1 VSS, 2 VOUT, 3 VIN — les pistes des pads 2 et 3 de U100 sont INVERSEES sur le PCB, a corriger avant de commander (voir NOTE-LDO-PMW3360.md)
A CHOISIR | 10 | LED temoin de charge | 0805 | 2 | 1 | 3 | aucune reference au schema - couleur au gout
A CHOISIR | 5 | LED infrarouge 940nm eclairage capteur | 0805 | 0 | 1 | 1 | aucune reference au schema - verifier l'intensite requise par le PMW3360

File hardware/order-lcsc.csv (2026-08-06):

LCSC Part Number | Quantity | Description | Package | Qty per board | Notes | Link
C4154405 | 3 | CH334R hub USB 2.0 | QSOP-16 | 1 | WCH - introuvable hors Chine | https://lcsc.com/product-detail/C4154405.html
C16581 | 5 | TP4056-42-ESOP8 | ESOP-8 | 2 |  | https://lcsc.com/product-detail/C16581.html
C351410 | 5 | DW01A | SOT-23-6 | 2 |  | https://lcsc.com/product-detail/C351410.html
C32254 | 5 | FS8205 | SOT-23-6 | 2 |  | https://lcsc.com/product-detail/C32254.html
C351408 | 5 | AO3407 | SOT-23 | 2 |  | https://lcsc.com/product-detail/C351408.html
C431540 | 5 | MSK-12C02 | SMD | 2 | SHOU HAN | https://lcsc.com/product-detail/C431540.html
C165948 | 5 | USB-C TYPE-C-31-M-12 16P | SMD | 2 | HRO - VERROUILLE par l'empreinte de la carte | https://lcsc.com/product-detail/C165948.html
C1591 | 200 | 100nF X7R 50V Samsung | 0603 | 9 | tous les 100nF unifies en 0603 | https://lcsc.com/product-detail/C1591.html
C28323 | 100 | 1uF Samsung | 0805 | 8 | tous les 1uF unifies en 0805 | https://lcsc.com/product-detail/C28323.html
C128855 | 100 | 10uF X5R 25V YAGEO | 1206 | 13 | tous les 10uF unifies en 1206 par Mae (ex-22uF C16 inclus) | https://lcsc.com/product-detail/C128855.html

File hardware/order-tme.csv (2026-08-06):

Symbol | Quantity | Description | Package | Qty per board | Notes | Link
SD05C.TCT | 50 | TVS bidir 5V Semtech | SOD-323 | 22 | equivalent du SD05C-01FTG | https://www.tme.eu/en/details/sd05c.tct/bidirectional-smd-transil-diodes/semtech/
SRV05-4.TCT | 5 | TVS array Semtech | SOT-23-6 | 2 |  | https://www.tme.eu/en/details/srv05-4.tct/protection-diodes-arrays/semtech/
USBLC6-2SC6 | 5 | ESD USB ST | SOT-23-6 | 2 | ~216k en stock | https://www.tme.eu/en/details/usblc6-2sc6/protection-diodes-arrays/stmicroelectronics/
FH12-6S-0.5SH(55) | 3 | ZIF Hirose 6P 0.5mm contacts bas | SMD | 1 | trackpad | https://www.tme.eu/en/details/fh12-6s-0.5sh-55/connectors-ffc-fpc-0-5mm/hirose/fh12-6s-0-5sh-55/
LD1117S33TR | 3 | LDO 3.3V ST | SOT-223 | 1 | remplacant direct AMS1117-3.3 (meme pinout SOT-223) | https://www.tme.com/us/en-us/details/ld1117s33tr/ldo-fixed-voltage-regulators/stmicroelectronics/
SIP32431DR3-T1GE3 | 5 | Load switch Vishay | SC-70-6 | 2 |  | https://www.tme.com/us/en-us/details/sip32431dr3-t1ge3/power-switches-integrated-circuits/vishay/
HT7833 | 5 | LDO 3.3V 500mA Holtek | SOT-89 | 2 | remplace MCP1700 (250mA trop juste pour les pics du S3) - meme brochage SOT-89 ; mettre a jour Value+LCSC des symboles U20/U21/U420/U421 a la prochaine session schema | https://www.tme.eu/fr/katalog/?search=HT7833
SS14 | 5 | Schottky 1A 40V onsemi | SMA | 2 | symbole TME SS14-FAI | https://www.tme.eu/en/details/ss14-fai/smd-schottky-diodes/onsemi/ss14/
1N4148W | 200 | Diode matrice Lite-On | SOD-123 | 52 | symbole TME 1N4148W-LIT | https://www.tme.eu/en/details/1n4148w-lit/smd-universal-diodes/diodes-lite-on-semiconductor/1n4148w/
0603WAF1000T5E | 200 | 100R 1% Royalohm | 0603 | 40 |  | https://www.tme.eu/en/details/0603waf1000t5e/smd-resistors/royalohm/
0603WAF1002T5E | 100 | 10k 1% Royalohm | 0603 | 10 |  | https://www.tme.eu/en/details/0603waf1002t5e/smd-resistors/royalohm/
0603WAF5101T5E | 100 | 5k1 1% Royalohm | 0603 | 4 | CC USB-C | https://www.tme.eu/en/details/0603waf5101t5e/smd-resistors/royalohm/
0603WAF4701T5E | 100 | 4k7 1% Royalohm | 0603 | 2 | I2C trackpad | https://www.tme.eu/en/details/0603waf4701t5e/smd-resistors/royalohm/
0805W8F2401T5E | 100 | 2k4 1% Royalohm | 0805 | 2 | PROG TP4056 - page vue via locale SG; ce lien /en/ a confirmer | https://www.tme.eu/en/details/0805w8f2401t5e/smd-resistors/royalohm/
0805W8F1001T5E | 100 | 1k 1% Royalohm | 0805 | 4 |  | https://www.tme.eu/en/details/0805w8f1001t5e/smd-resistors/royalohm/
0805S8F1004T5E | 100 | 1M 1% Royalohm serie S | 0805 | 4 | jauge VBAT_SENSE - la serie W n'est pas chez TME | https://www.tme.com/us/en-us/details/0805s8f1004t5e/smd-resistors/royalohm/
0603WAF1003T5E | 100 | 100k 1% Royalohm | 0603 | 5 |  | https://www.tme.eu/en/details/0603waf1003t5e/smd-resistors/royalohm/

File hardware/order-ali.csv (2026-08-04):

Item | Quantity | Description | Qty per board | Statut | Notes | Link
Module nRF24L01+ | 4 | Radio 2.4GHz breakout 2x4 pin | 2 | a verifier tiroir | prendre des PA/LNA-free (portee clavier suffisante) - 2 rechanges | https://fr.aliexpress.com/w/wholesale-nrf24l01%2B.html
Module ESP32-P4 JC-ESP32P4-M3 | 1 | Coffre - module V0.2 | 1 | a commander | empreinte V0.2 sur le PCB - verifier la revision vendue | https://fr.aliexpress.com/w/wholesale-esp32-p4-module.html
Jack TRRS MJ-4PP-9 | 4 | Jack 3.5mm 4 poles CMS | 2 | a commander | lien v1 qui marchait - 2 rechanges | https://fr.aliexpress.com/item/33029465106.html
Cable TRRS 4 poles | 2 | Liaison inter-moities | 1 | a verifier tiroir | cable DROIT (croisement gere en firmware) - liens v1 | https://fr.aliexpress.com/item/1005002888851426.html
Switchs MX hotswap sockets | 60 | Sockets Kailh MX | 52 | a verifier tiroir | lien v1 (MX_Socket) - marge casse | https://fr.aliexpress.com/item/1005003873653184.html
Switchs mecaniques | 60 | MX ou Choc au gout | 52 | a verifier tiroir | ex. Kailh Cream du README v1 | https://fr.aliexpress.com/item/1005003694230110.html
Keycaps | 1 | Set profil au gout | 1 | a verifier tiroir | liens v1 : AF SA / cerise | https://fr.aliexpress.com/item/1005003935785708.html
Cellule 16340 | 4 | Li-ion 3.7V (avec ou sans teton selon holder) | 2 | a commander | prendre des protegees ou non selon contacts retenus - decision layout holder en attente | https://fr.aliexpress.com/w/wholesale-16340-battery.html
Contacts ou holder 16340 | 2 | Contacts ressort CMS ou holder | 2 | a commander | ATTENTE decision layout (design doc) - empreinte pas encore posee | https://fr.aliexpress.com/w/wholesale-16340-holder.html
Antenne u.FL 2.4GHz | 2 | Pour les WROOM-1U du tiroir | 2 | a commander si pas en tiroir | antenne IPEX/u.FL courte + verifier longueur cable | https://fr.aliexpress.com/w/wholesale-ufl-antenna-2.4ghz.html

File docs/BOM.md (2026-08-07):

Creation date: 02/12/2023

By ordering on [JLCPCB](https://cart.jlcpcb.com/quote?orderType=1&stencilLayer=2&stencilWidth=100&stencilLength=100&stencilCounts=5):

x 5 = 10.60$

u = 2.12$ x 2 = 4.24$

| Id | Reference | Package | Quantity | Designation | Supplier and ref | Ali price |
|----|---|---|---|---|---|---|
| 1  | D1,D2,D3...| Diode_TH_SOD123EKR | 26 | D |  [aliexpress](https://fr.aliexpress.com/item/1005003631407506.html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) , [TME](https://www.tme.eu/fr/details/1n5711w-7-f/diodes-schottky-smd/diodes-incorporated/) | 0.0546€ x 26 = 1.42€ |
| 2  | L1,L2,L3...| SK6812MINI_rev | 26 | SK6812MINI |  [aliexpress](https://fr.aliexpress.com/item/1005003021596311.html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) | 0.0704€ x 26 = 1.83€ |
| 3  | SW1,SW2,SW3...| MX_Socket_18mm | 26 | SW_PUSH | [aliexpress](https://fr.aliexpress.com/item/1005003873653184.html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)  | 0.1285€ x 26 = 3.34€ |
| 5  | U1 | ProMicro_v2 | 1 | ProMicro | [aliexpress](https://fr.aliexpress.com/item/1005003622414316.html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)  | 6.155€ |
| 8  | JP1 | JPC2 | 1 |  1X4Pin | [aliexpress](https://fr.aliexpress.com/item/4000979967513.html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)  | 0.182€ |
| 9  | J2 | OLED | 1 | OLED |  [aliexpress](https://fr.aliexpress.com/item/33024849277.html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) | 3.10€ |
| 10 | J1 | MJ-4PP-9 | 1 | MJ-4PP-9 |  [aliexpress](https://fr.aliexpress.com/item/33029465106.html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) | 0.246€ |
| 11 | RSW1 | ResetSW | 1 | SW_PUSH | [aliexpress](https://fr.aliexpress.com/item/1005004067514307.html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)  | 0.137€ |
| 12 | L22,L23,L24... | SK6812MINI_underglow_rev | 7 | SK6812MINI |  [aliexpress](https://fr.aliexpress.com/item/1005003021596311.html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) | 0.0704€ x 7 = 0.49€ |

Total price : 16.45€ x 2 = 32.90€

Other Parts:
| Name | links |
|---|---|
| Jack TRRS cable | [ali1](https://fr.aliexpress.com/item/1005003415667083.html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) [ali2](https://fr.aliexpress.com/item/33006667627.html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) [ali3](https://fr.aliexpress.com/item/1005002888851426.html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) |
| Switchs | [ali1](https://fr.aliexpress.com/item/1005003436102892.html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), [ali Khail Cream](https://fr.aliexpress.com/item/1005003694230110.html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) |
| Keycaps | [AF SA](https://fr.aliexpress.com/item/1005003935785708.html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), [cerise](https://fr.aliexpress.com/item/1005003932690197.html?gatewayAdapt=glo2fra) |

Simulate the final price (case not included):

| PCB | SMDs | Switchs | Keycaps[?](https://fr.aliexpress.com/item/1005003935785708.html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) | Total |
|---|---|---|---|---|
| 3.97€ | 32.90€ | 18.06€ | 48.98€ | 103.91€ |

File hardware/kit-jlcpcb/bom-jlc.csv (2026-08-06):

Comment | Designator | Footprint | LCSC Part #
100 | R3,R4,R5,R6,R7,R8,R9,R10,R11,R12,R13,R14,R15,R16,R17,R18,R19,R20,R21,R22,R23,R24,R25,R26,R27,R28,R30,R31,R36,R37,R38,R39,R40,R41,R44,R45,R46,R47,R70,R71 | R_0603_1608Metric_Pad0.98x0.95mm_HandSolder | C22775
100k | R35,R42,R43,R60,R61 | R_0603_1608Metric_Pad0.98x0.95mm_HandSolder | C25803
100nF | C1,C2,C5,C6,C7,C8,C17,C21,C22 | C_0603_1608Metric_Pad1.08x0.95mm_HandSolder | C14663
10k | R1,R2,R33,R34,R54,R55,R56,R57,R58,R59 | R_0603_1608Metric_Pad0.98x0.95mm_HandSolder | C25804
10uF | C11,C12,C13,C15,C16,C19,C20,C23,C24,C25,C26,C29,C30 | C_1206_3216Metric_Pad1.33x1.80mm_HandSolder | C128855
1M | R64,R65,R66,R67 | R_0805_2012Metric_Pad1.20x1.40mm_HandSolder | C17514
1N4148W | D1,D2,D3,D4,D5,D6,D7,D8,D9,D10,D11,D12,D13,D14,D15,D16,D17,D18,D19,D20,D21,D22,D23,D24,D25,D26,D27,D28,D29,D30,D31,D32,D33,D34,D35,D36,D37,D38,D39,D40,D41,D42,D43,D44,D45,D46,D47,D48,U1,U2,U3,U4 | D_SOD-123 | C81598
1k | R62,R63,R72,R73 | R_0805_2012Metric_Pad1.20x1.40mm_HandSolder | C17513
1uF | C3,C4,C9,C10,C14,C18,C27,C28 | C_0805_2012Metric_Pad1.18x1.45mm_HandSolder | C28323
2k4 | R68,R69 | R_0805_2012Metric_Pad1.20x1.40mm_HandSolder | C17526
4.7k | R29,R32 | R_0603_1608Metric_Pad0.98x0.95mm_HandSolder | C23162
5k1 | R50,R51,R52,R53 | R_0603_1608Metric_Pad0.98x0.95mm_HandSolder | C23186
AMS1117-3.3 | U17 | SOT-223-3_TabPin2 | C6186
AO3407 | Q1,Q2 | SOT-23 | C351408
CH334R | U13 | QSOP-16_3.9x4.9mm_P0.635mm | C4154405
DW01A | U22,U23 | SOT-23-6 | C351410
ESP32-S3-WROOM-1 | U5,U6 | ESP32-S3-WROOM-1U | C2913204
FS8205 | Q3,Q4 | SOT-23-6 | C32254
HT7833 | U20,U21 | SOT-89-3 | C50936
SD05C-01F | D100,D101,D102,D103,D104,D105,D106,D107,D108,D109,D110,D111,D112,D113,D114,D115,D116,D117,D118,D119,D120,D121 | D_SOD-323 | C2827707
SRV05-4 | U9,U10 | SOT-23-6 | C13612
SS14 | D51,D52 | D_SMA | C2480
SW_SPDT | SW53,SW54 | SW_SPDT_PCM12 | C431540
SiP32431DR3 | U11,U12 | SOT-363_SC-70-6 | C141606
TP4056-42-ESOP8 | U18,U19 | SOIC-8-1EP_3.9x4.9mm_P1.27mm_EP2.41x3.3mm_ThermalVias | C16581
TPS43_FPC | J3 | Hirose_FH12-6S-0.5SH_1x06-1MP_P0.50mm_Horizontal | C202118
USBLC6-2SC6 | U14,U15 | SOT-23-6 | C7519
USB_C_Receptacle_USB2.0_16P | J7,J8 | USB_C_Receptacle_HRO_TYPE-C-31-M-12 | C165948

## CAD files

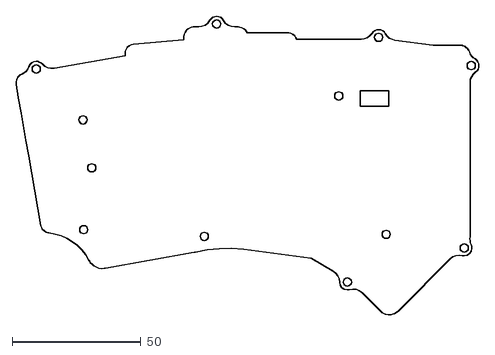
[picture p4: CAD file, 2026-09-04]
case/plate_bottom_PC.dxf
179.6 x 115.8

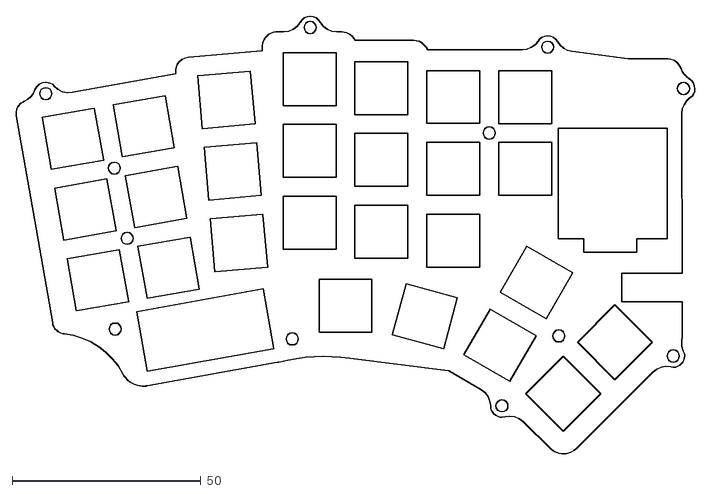
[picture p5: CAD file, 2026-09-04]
case/plate_top_PC.dxf
179.6 x 115.8

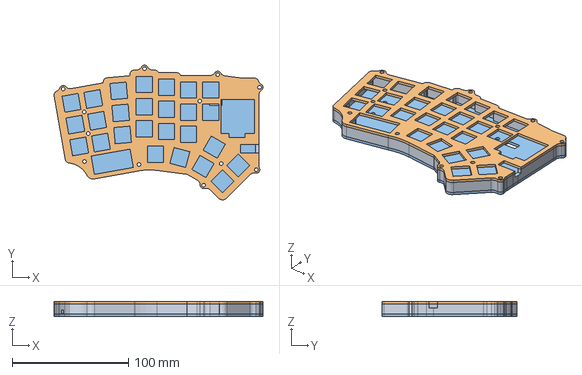
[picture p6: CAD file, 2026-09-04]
case/niphar-case-left.step
179.6 x 115.8 x 12.5 mm

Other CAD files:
case/plate_top_PC_edit.dxf
case/niphar-case-left.FCStd

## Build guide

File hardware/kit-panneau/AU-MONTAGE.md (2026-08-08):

# À lire avant de souder

Cartes commandées le **2026-08-08** chez JLCPCB, 4 couches vert, 60,83 € les
deux designs du clavier plus la souris Conchodytes. Assemblage **à la main**.

## ⚠️ J6 se soude PAR LE DESSOUS

Les deux jacks TRRS ne sont pas sur la même face :

| Connecteur | Face dans le fichier | Moitié |
|---|---|---|
| J5 | `F.Cu` — dessus | droite |
| **J6** | **`B.Cu` — DESSOUS** | **gauche** |

Les deux USB-C (J7, J8) sont en `F.Cu` tous les deux : l'asymétrie ne touche que
le TRRS, et porte la signature d'un basculement de face lors du placement
miroir. Le routage est cohérent avec cette face — l'ERC et le DRC sont verts.

**Souder J6 par le dessus casserait le clavier.** Un jack traversant monté sur
l'autre face a son brochage en miroir : Tip et Sleeve s'échangent, donc les 5 V
du lien inter-moitiés arrivent sur la masse. Le brochage n'est juste que si le
corps du connecteur sort **sous** la carte.

Conséquence pour le boîtier — il n'est pas usiné, c'est encore rattrapable : la
moitié gauche a besoin de son ouverture TRRS **sous** la carte, la droite
**au-dessus**.

## Autres points non vérifiés

- **Hauteur du MJ-4PP-9** : 5,4 mm disponibles dans le cadre alu de 8,5 mm,
  contre ~6,3 mm au catalogue. À mesurer sur la pièce réelle avant d'usiner.
- **Vis du sandwich** : 6 des 8 n'ont que 1,4 mm de matière autour du perçage.
  Ça tient en aluminium ; c'est le polycarbonate de 2 mm qui cassera.
- **Souris Conchodytes** : le rail +1,8 V du PMW3360 vient de la consigne de
  Mae, pas d'une lecture de datasheet. À confirmer avant de mettre sous tension.
  Lentille **LM19-LSI** à commander séparément.

## Séparer le panneau

Deux ponts de ~6,5 mm reliant les moitiés, chacun avec un `MouseBite-Slot` à
double rang : casser le long des deux rangées, la bandelette centrale de 1,5 mm
part à la chute et chaque carte garde un bord net. Ébavurer à la lime douce.

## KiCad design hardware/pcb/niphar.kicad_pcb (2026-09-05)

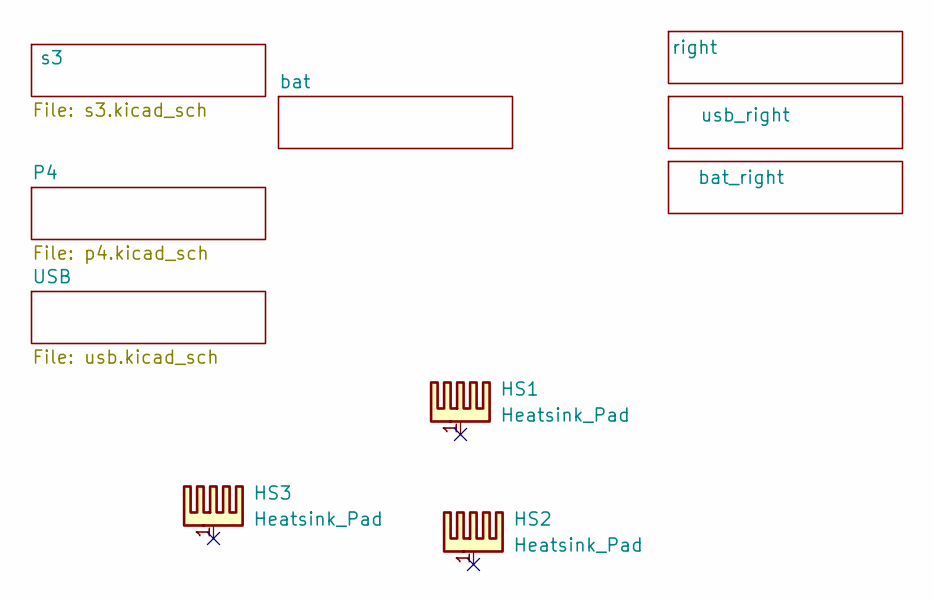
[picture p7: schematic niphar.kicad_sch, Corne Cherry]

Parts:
HS1, HS2: Heatsink_Pad; Niphargus_10mm_Cu
HS3: Heatsink_Pad; Niphargus_text_3mm_silk

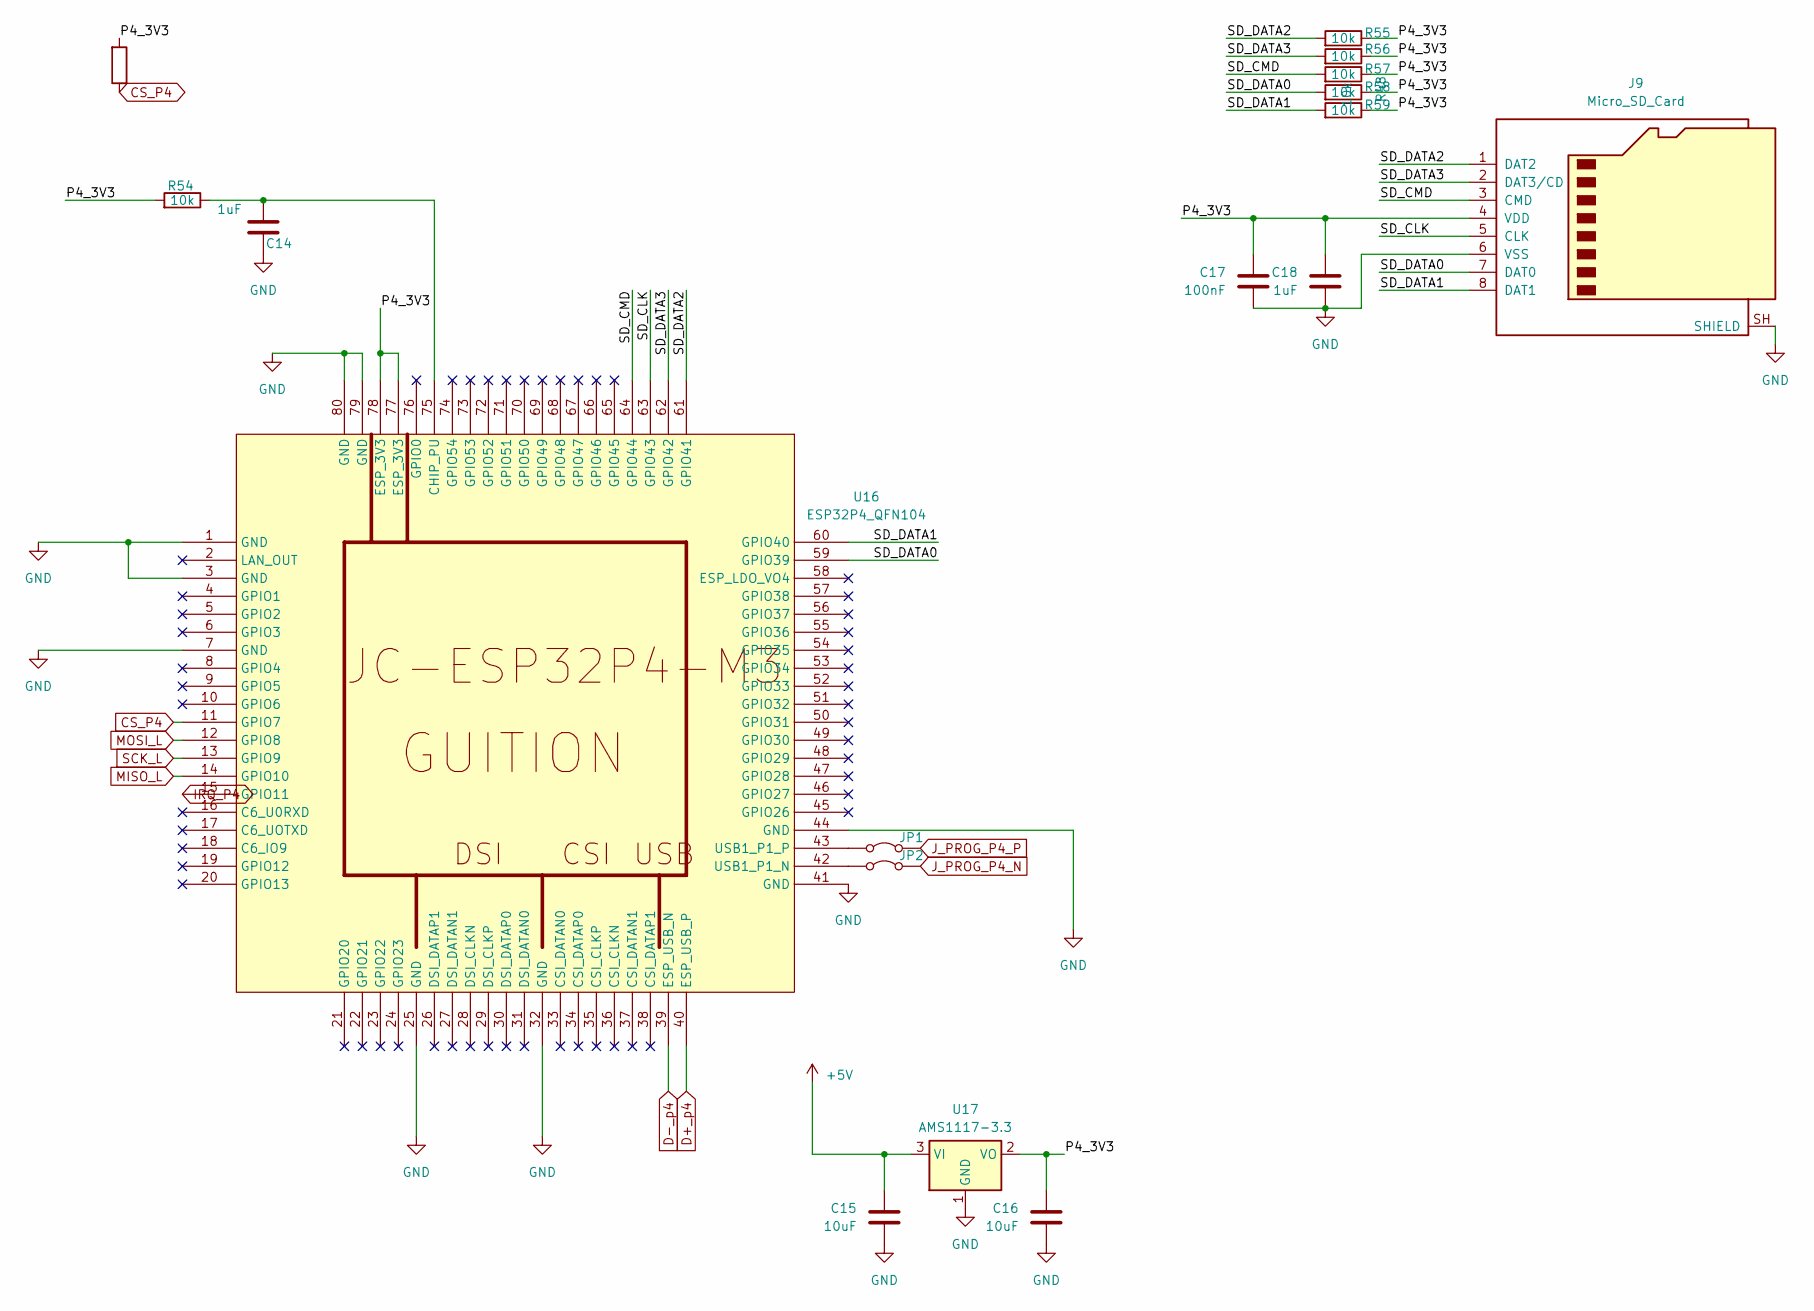
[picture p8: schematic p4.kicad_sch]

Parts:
C14, C18: 1uF; C_0805_2012Metric_Pad1.18x1.45mm_HandSolder
C15, C16: 10uF; C_1206_3216Metric_Pad1.33x1.80mm_HandSolder
C17: 100nF; C_0603_1608Metric_Pad1.08x0.95mm_HandSolder
J9: Micro_SD_Card; microSD_HC_Wuerth_693072010801
JP1, JP2: Jumper_2_Bridged; Jumper
R48, R54, R55, R56, R57, R58, R59: 10k; R_0603_1608Metric_Pad0.98x0.95mm_HandSolder
U16: ESP32P4_QFN104; JC-ESP32P4-M3_V0.2
U17: AMS1117-3.3; SOT-223-3_TabPin2; LCSC C6186

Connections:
+5V: C15.2, U17.3 (VI); also elsewhere on the board
/P4/P4_3V3: C16.2, C17.2, C18.2, J9.4 (VDD), R48.2, R54.2, R55.1, R56.1, R57.1, R58.1, R59.1, U16.77 (ESP_3V3), U16.78 (ESP_3V3), U17.2 (VO)
/P4/SD_CLK: J9.5 (CLK), U16.63 (GPIO43)
/P4/SD_CMD: J9.3 (CMD), R57.2, U16.64 (GPIO44)
/P4/SD_DATA0: J9.7 (DAT0), R58.2, U16.59 (GPIO39)
/P4/SD_DATA1: J9.8 (DAT1), R59.2, U16.60 (GPIO40)
/P4/SD_DATA2: J9.1 (DAT2), R55.2, U16.61 (GPIO41)
/P4/SD_DATA3: J9.2 (DAT3/CD), R56.2, U16.62 (GPIO42)
CS_P4: R48.1, U16.11 (GPIO7); also elsewhere on the board
D+_p4: U16.40 (ESP_USB_P); also elsewhere on the board
D-_p4: U16.39 (ESP_USB_N); also elsewhere on the board
GND: C14.1, C15.1, C16.1, C17.1, C18.1, J9.6 (VSS), J9.SH (SHIELD), U16.1 (GND), U16.3 (GND), U16.7 (GND), U16.25 (GND), U16.32 (GND), U16.41 (GND), U16.44 (GND), U16.79 (GND), U16.80 (GND), U17.1 (GND); also elsewhere on the board
IRQ_P4: U16.15 (GPIO11); also elsewhere on the board
J_PROG_P4_N: JP2.2 (B); also elsewhere on the board
J_PROG_P4_P: JP1.2 (B); also elsewhere on the board
MISO_L: U16.14 (GPIO10); also elsewhere on the board
MOSI_L: U16.12 (GPIO8); also elsewhere on the board
unnamed: JP1.1 (A), U16.43 (USB1_P1_P)
unnamed: JP2.1 (A), U16.42 (USB1_P1_N)
unnamed: C14.2, R54.1, U16.75 (CHIP_PU)
SCK_L: U16.13 (GPIO9); also elsewhere on the board

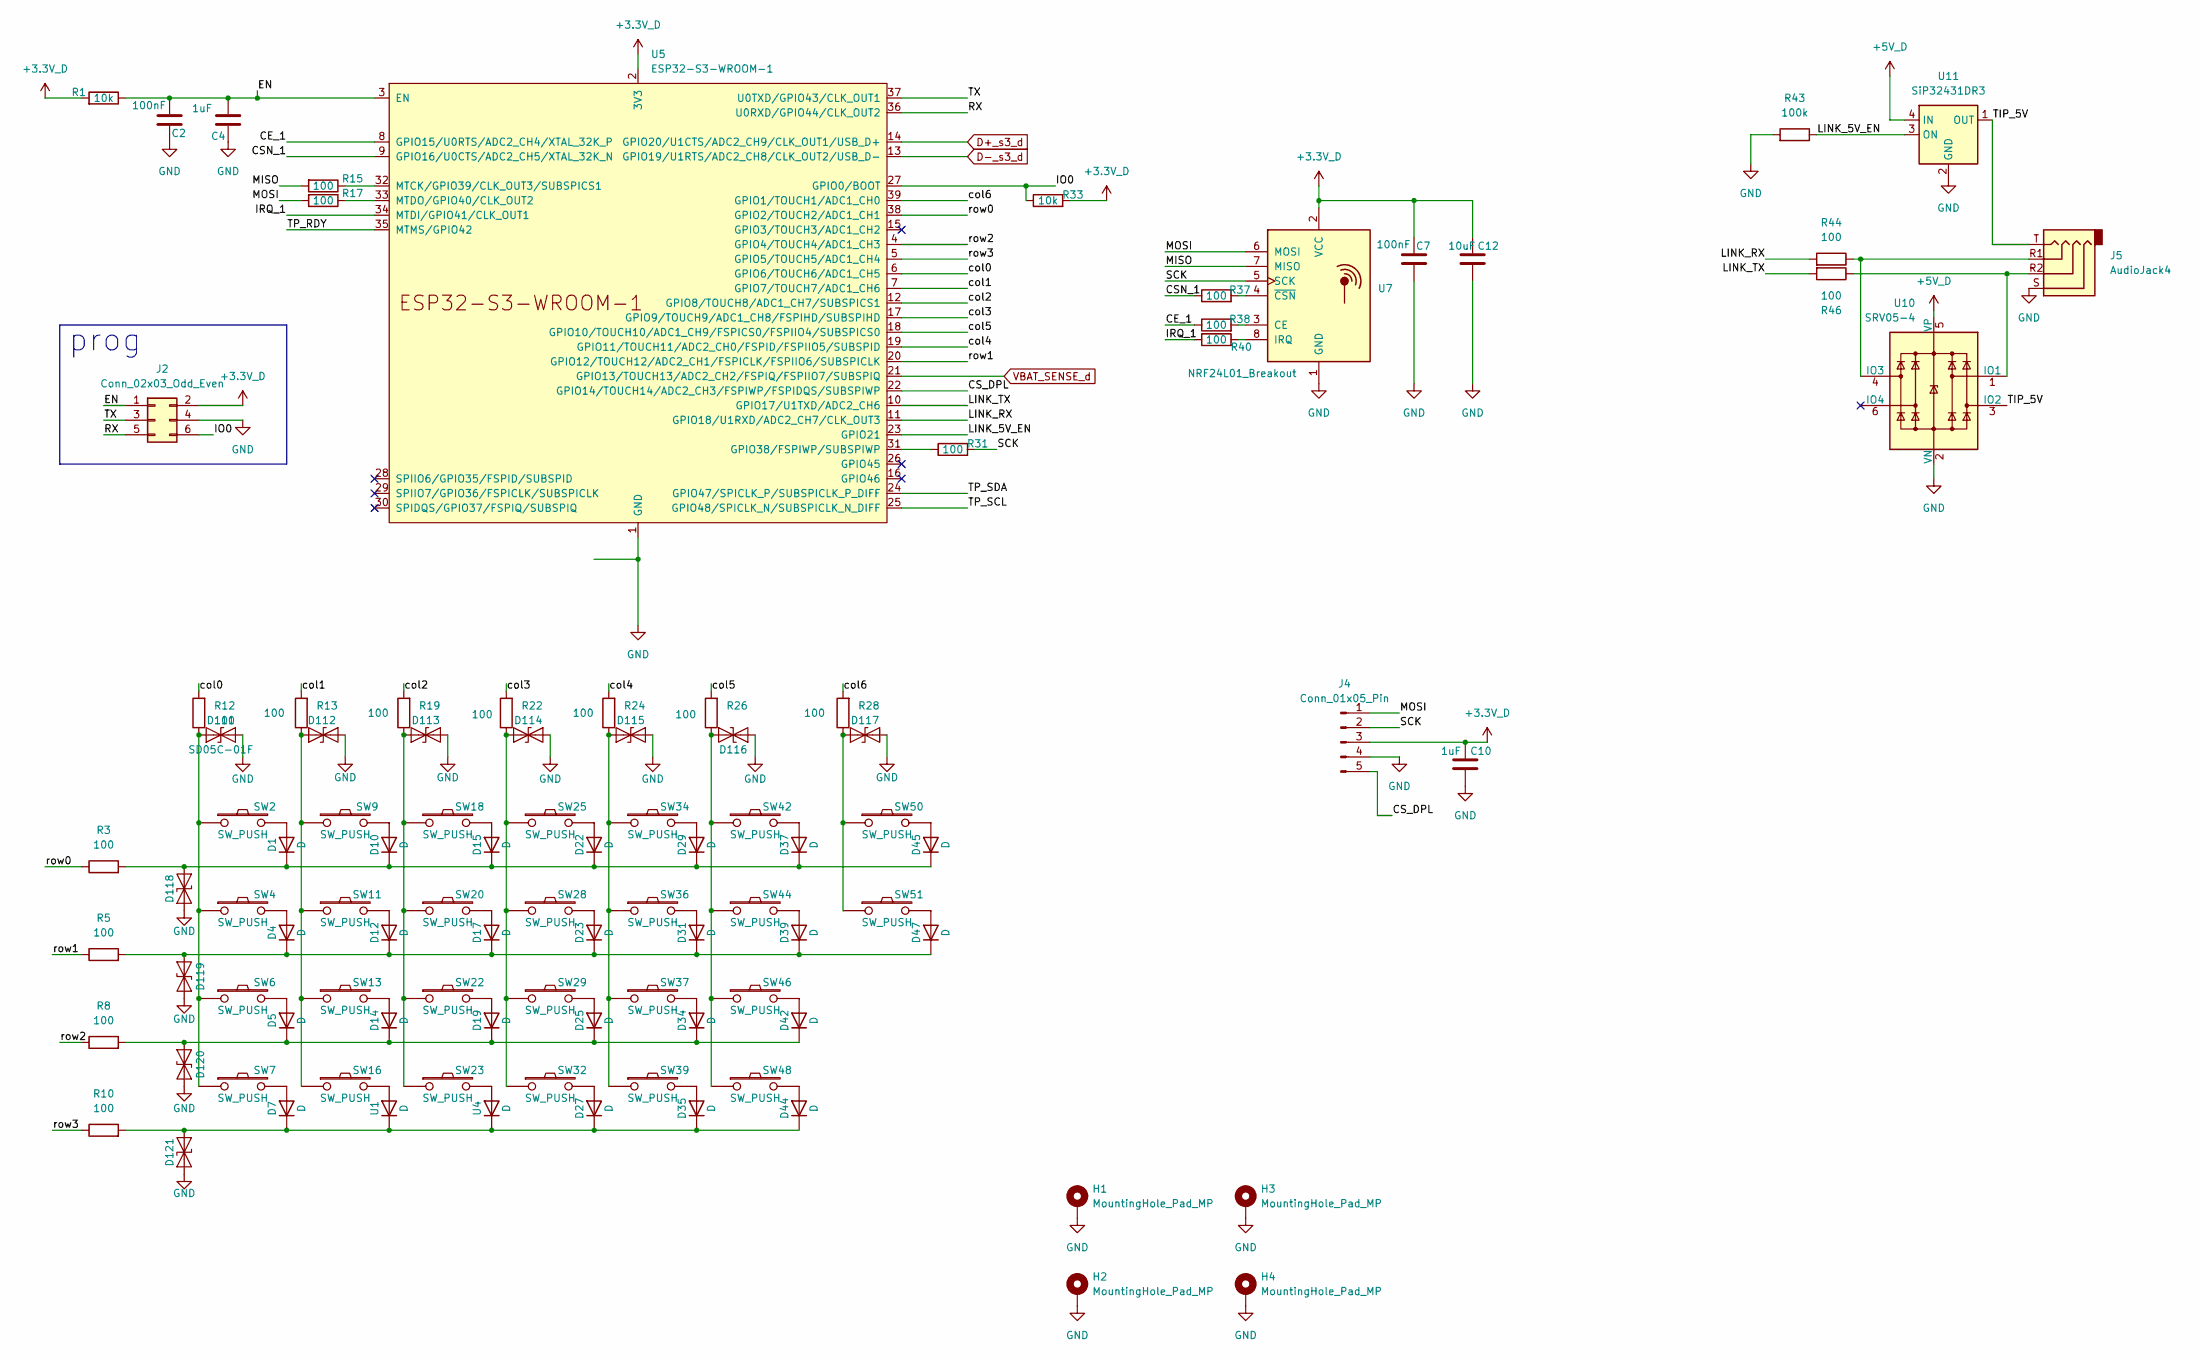
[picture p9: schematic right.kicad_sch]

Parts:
C2, C7: 100nF; C_0603_1608Metric_Pad1.08x0.95mm_HandSolder
C4, C10: 1uF; C_0805_2012Metric_Pad1.18x1.45mm_HandSolder
C12: 10uF; C_1206_3216Metric_Pad1.33x1.80mm_HandSolder
D1, D4, D5, D7, D10, D12, D14, D15, D17, D19, D22, D23, D25, D27, D29, D31, D34, D35, D37, D39, D42, D44, D45, D47: D; D_SOD-123
D111, D112, D113, D114, D115, D116, D117, D118, D119, D120, D121: SD05C-01F; D_SOD-323; LCSC C2827707
H1, H2, H3, H4: MountingHole_Pad_MP; MountingHole_3.2mm_M3_DIN965_Pad
J2: Conn_02x03_Odd_Even; PinHeader_2x03_P1.27mm_Vertical
J4: Conn_01x05_Pin; PinHeader_1x05_P2.54mm_Vertical
J5: AudioJack4; MJ-4PP-9_rev3
R1, R33: 10k; R_0603_1608Metric_Pad0.98x0.95mm_HandSolder
R3, R5, R8, R10, R12, R13, R15, R17, R19, R22, R24, R26, R28, R31, R37, R38, R40, R44, R46: 100; R_0603_1608Metric_Pad0.98x0.95mm_HandSolder
R43: 100k; R_0603_1608Metric_Pad0.98x0.95mm_HandSolder
SW2, SW4, SW6, SW7, SW9, SW11, SW13, SW16, SW18, SW20, SW22, SW23, SW25, SW28, SW29, SW32, SW34, SW36, SW37, SW39, SW42, SW44, SW46, SW48, SW50, SW51: SW_PUSH; SW_Cherry_MX_1.00u_PCB
U1, U4: D; D_SOD-123
U5: ESP32-S3-WROOM-1; ESP32-S3-WROOM-1U; LCSC C2913204
U7: NRF24L01_Breakout; NRF24L01
U10: SRV05-4; SOT-23-6; LCSC C13612
U11: SiP32431DR3; SOT-363_SC-70-6; LCSC C141606

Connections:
+3.3V_D: C7.2, C10.2, C12.2, J2.2, J4.3, R1.2, R33.2, U5.2 (3V3), U7.2 (VCC); also elsewhere on the board
+5V_D: U10.5 (VP), U11.4 (IN); also elsewhere on the board
/right/CE_1: R38.1, U5.8 (GPIO15/U0RTS/ADC2_CH4/XTAL_32K_P)
/right/CSN_1: R37.1, U5.9 (GPIO16/U0CTS/ADC2_CH5/XTAL_32K_N)
/right/CS_DPL: J4.5, U5.22 (GPIO14/TOUCH14/ADC2_CH3/FSPIWP/FSPIDQS/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)
/right/EN: C2.2, C4.2, J2.1, R1.1, U5.3 (EN)
/right/IO0: J2.6, R33.1, U5.27 (GPIO0/BOOT)
/right/IRQ_1: R40.1, U5.34 (MTDI/GPIO41/CLK_OUT1)
/right/LINK_5V_EN: R43.1, U5.23 (GPIO21), U11.3 (ON)
/right/LINK_RX: R44.2, U5.11 (GPIO18/U1RXD/ADC2_CH7/CLK_OUT3)
/right/LINK_TX: R46.2, U5.10 (GPIO17/U1TXD/ADC2_CH6)
/right/MISO: R15.2, U7.7 (MISO)
/right/MOSI: J4.1, R17.2, U7.6 (MOSI)
/right/RX: J2.5, U5.36 (U0RXD/GPIO44/CLK_OUT2)
/right/SCK: J4.2, R31.2, U7.5 (SCK)
/right/TIP_5V: J5.T, U10.3 (IO2), U11.1 (OUT)
/right/TP_RDY: U5.35 (MTMS/GPIO42)
/right/TP_SCL: U5.25 (GPIO48/SPICLK_N/SUBSPICLK_N_DIFF)
/right/TP_SDA: U5.24 (GPIO47/SPICLK_P/SUBSPICLK_P_DIFF)
/right/TX: J2.3, U5.37 (U0TXD/GPIO43/CLK_OUT1)
/right/col0: R12.2, U5.6 (GPIO6/TOUCH6/ADC1_CH5)
/right/col1: R13.2, U5.7 (GPIO7/TOUCH7/ADC1_CH6)
/right/col2: R19.2, U5.12 (GPIO8/TOUCH8/ADC1_CH7/SUBSPICS1)
/right/col3: R22.2, U5.17 (GPIO9/TOUCH9/ADC1_CH8/FSPIHD/SUBSPIHD)
/right/col4: R24.2, U5.19 (GPIO11/TOUCH11/ADC2_CH0/FSPID/FSPIIO5/S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)
/right/col5: R26.2, U5.18 (GPIO10/TOUCH10/ADC1_CH9/FSPICS0/FSPIIO4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)
/right/col6: R28.2, U5.39 (GPIO1/TOUCH1/ADC1_CH0)
/right/row0: R3.1, U5.38 (GPIO2/TOUCH2/ADC1_CH1)
/right/row1: R5.1, U5.20 (GPIO12/TOUCH12/ADC2_CH1/FSPICLK/FSPIIO6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)
/right/row2: R8.1, U5.4 (GPIO4/TOUCH4/ADC1_CH3)
/right/row3: R10.1, U5.5 (GPIO5/TOUCH5/ADC1_CH4)
D+_s3_d: U5.14 (GPIO20/U1CTS/ADC2_CH9/CLK_OUT1/USB_D+); also elsewhere on the board
D-_s3_d: U5.13 (GPIO19/U1RTS/ADC2_CH8/CLK_OUT2/USB_D-); also elsewhere on the board
GND: C2.1, C4.1, C7.1, C10.1, C12.1, D111.2 (A2), D112.2 (A2), D113.2 (A2), D114.2 (A2), D115.2 (A2), D116.2 (A2), D117.2 (A2), D118.2 (A2), D119.2 (A2), D120.2 (A2), D121.2 (A2), H1.MP, H2.MP, H3.MP, H4.MP, J2.4, J4.4, J5.S, R43.2, U5.1 (GND), U5.40 (GND), U5.41 (GND), U7.1 (GND), U10.2 (VN), U11.2 (GND), U11.5 (GND); also elsewhere on the board
unnamed: D1.2 (A), SW2.2
unnamed: D1.1 (K), D10.1 (K), D15.1 (K), D22.1 (K), D29.1 (K), D37.1 (K), D45.1 (K), D118.1 (A1), R3.2
unnamed: D4.2 (A), SW4.2
unnamed: D5.2 (A), SW6.2
unnamed: D7.2 (A), SW7.2
unnamed: D10.2 (A), SW9.2
unnamed: D12.2 (A), SW11.2
unnamed: D14.2 (A), SW13.2
unnamed: D15.2 (A), SW18.2
unnamed: D17.2 (A), SW20.2
unnamed: D19.2 (A), SW22.2
unnamed: D22.2 (A), SW25.2
unnamed: D23.2 (A), SW28.2
unnamed: D25.2 (A), SW29.2
unnamed: D27.2 (A), SW32.2
unnamed: D29.2 (A), SW34.2
unnamed: D31.2 (A), SW36.2
unnamed: D34.2 (A), SW37.2
unnamed: D35.2 (A), SW39.2
unnamed: D37.2 (A), SW42.2
unnamed: D39.2 (A), SW44.2
unnamed: D42.2 (A), SW46.2
unnamed: D44.2 (A), SW48.2
unnamed: D45.2 (A), SW50.2
unnamed: D47.2 (A), SW51.2
unnamed: D111.1 (A1), R12.1, SW2.1, SW4.1, SW6.1, SW7.1
unnamed: D112.1 (A1), R13.1, SW9.1, SW11.1, SW13.1, SW16.1
unnamed: D113.1 (A1), R19.1, SW18.1, SW20.1, SW22.1, SW23.1
unnamed: D114.1 (A1), R22.1, SW25.1, SW28.1, SW29.1, SW32.1
unnamed: D115.1 (A1), R24.1, SW34.1, SW36.1, SW37.1, SW39.1
unnamed: D116.1 (A1), R26.1, SW42.1, SW44.1, SW46.1, SW48.1
unnamed: D117.1 (A1), R28.1, SW50.1, SW51.1
unnamed: D4.1 (K), D12.1 (K), D17.1 (K), D23.1 (K), D31.1 (K), D39.1 (K), D47.1 (K), D119.1 (A1), R5.2
unnamed: D5.1 (K), D14.1 (K), D19.1 (K), D25.1 (K), D34.1 (K), D42.1 (K), D120.1 (A1), R8.2
unnamed: D7.1 (K), D27.1 (K), D35.1 (K), D44.1 (K), D121.1 (A1), R10.2, U1.1 (K), U4.1 (K)
unnamed: SW16.2, U1.2 (A)
unnamed: SW23.2, U4.2 (A)
unnamed: R31.1, U5.31 (GPIO38/FSPIWP/SUBSPIWP)
unnamed: R15.1, U5.32 (MTCK/GPIO39/CLK_OUT3/SUBSPICS1)
unnamed: R17.1, U5.33 (MTDO/GPIO40/CLK_OUT2)
unnamed: R38.2, U7.3 (CE)
unnamed: R40.2, U7.8 (IRQ)
unnamed: R37.2, U7.4 (~CSN)
unnamed: J5.R2, R46.1, U10.1 (IO1)
unnamed: J5.R1, R44.1, U10.4 (IO3)
VBAT_SENSE_d: U5.21 (GPIO13/TOUCH13/ADC2_CH2/FSPIQ/FSPIIO7/S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); also elsewhere on the board

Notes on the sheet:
prog

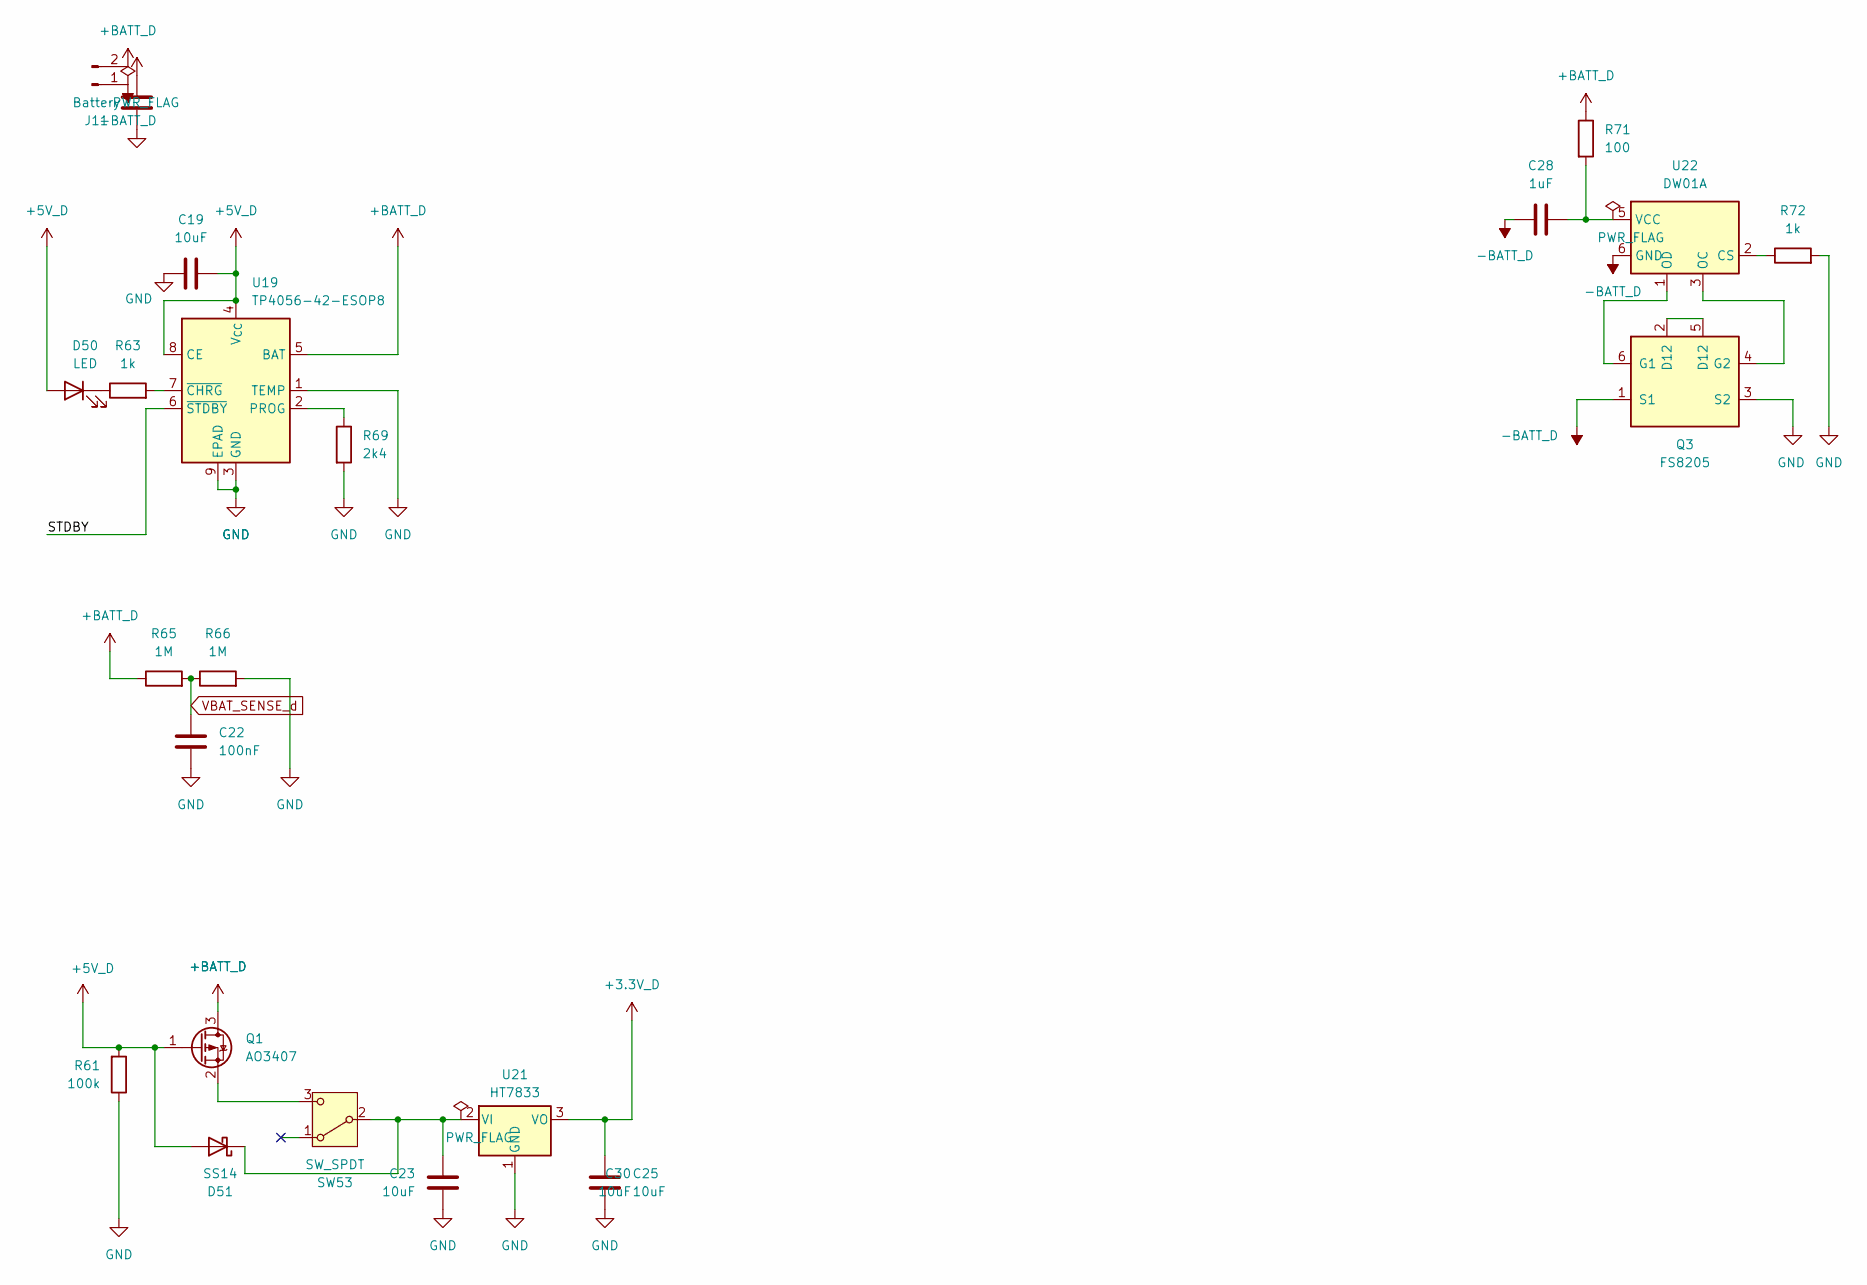
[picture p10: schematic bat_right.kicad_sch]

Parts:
C19, C23, C25, C30: 10uF; C_1206_3216Metric_Pad1.33x1.80mm_HandSolder
C22: 100nF; C_0603_1608Metric_Pad1.08x0.95mm_HandSolder
C28: 1uF; C_0805_2012Metric_Pad1.18x1.45mm_HandSolder
D50: LED; LED_0805_2012Metric_Pad1.15x1.40mm_HandSolder
D51: SS14; D_SMA; LCSC C2480
J11: Battery; PinHeader_1x02_P2.54mm_Vertical
Q1: AO3407; SOT-23; LCSC C351408
Q3: FS8205; SOT-23-6; LCSC C32254
R61: 100k; R_0603_1608Metric_Pad0.98x0.95mm_HandSolder
R63, R72: 1k; R_0805_2012Metric_Pad1.20x1.40mm_HandSolder
R65, R66: 1M; R_0805_2012Metric_Pad1.20x1.40mm_HandSolder
R69: 2k4; R_0805_2012Metric_Pad1.20x1.40mm_HandSolder
R71: 100; R_0603_1608Metric_Pad0.98x0.95mm_HandSolder
SW53: SW_SPDT; SW_SPDT_PCM12; LCSC C431540
U19: TP4056-42-ESOP8; SOIC-8-1EP_3.9x4.9mm_P1.27mm_EP2.41x3.3mm_ThermalVias; LCSC C16581
U21: HT7833; SOT-89-3; LCSC C50936
U22: DW01A; SOT-23-6; LCSC C351410

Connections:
+3.3V_D: C25.2, U21.3 (VO); also elsewhere on the board
+5V_D: C19.2, D50.2 (A), D51.2 (A), Q1.1 (G), R61.2, U19.4 (V_{CC}), U19.8 (CE); also elsewhere on the board
+BATT_D: C30.1, J11.2, Q1.3 (D), R65.1, R71.1, U19.5 (BAT)
-BATT_D: C28.2, J11.1, Q3.1 (S1), U22.6 (GND)
/bat_right/STDBY: U19.6 (~STDBY)
GND: C19.1, C22.1, C23.1, C25.1, C30.2, Q3.3 (S2), R61.1, R66.2, R69.2, R72.2, U19.1 (TEMP), U19.3 (GND), U19.9 (EPAD), U21.1 (GND); also elsewhere on the board
unnamed: D50.1 (K), R63.1
unnamed: C23.2, D51.1 (K), SW53.2 (B), U21.2 (VI)
unnamed: Q1.2 (S), SW53.3 (C)
unnamed: Q3.2 (D12), Q3.5 (D12)
unnamed: Q3.6 (G1), U22.1 (OD)
unnamed: Q3.4 (G2), U22.3 (OC)
unnamed: R69.1, U19.2 (PROG)
unnamed: R63.2, U19.7 (~CHRG)
unnamed: R72.1, U22.2 (CS)
unnamed: C28.1, R71.2, U22.5 (VCC)
VBAT_SENSE_d: C22.2, R65.2, R66.1; also elsewhere on the board

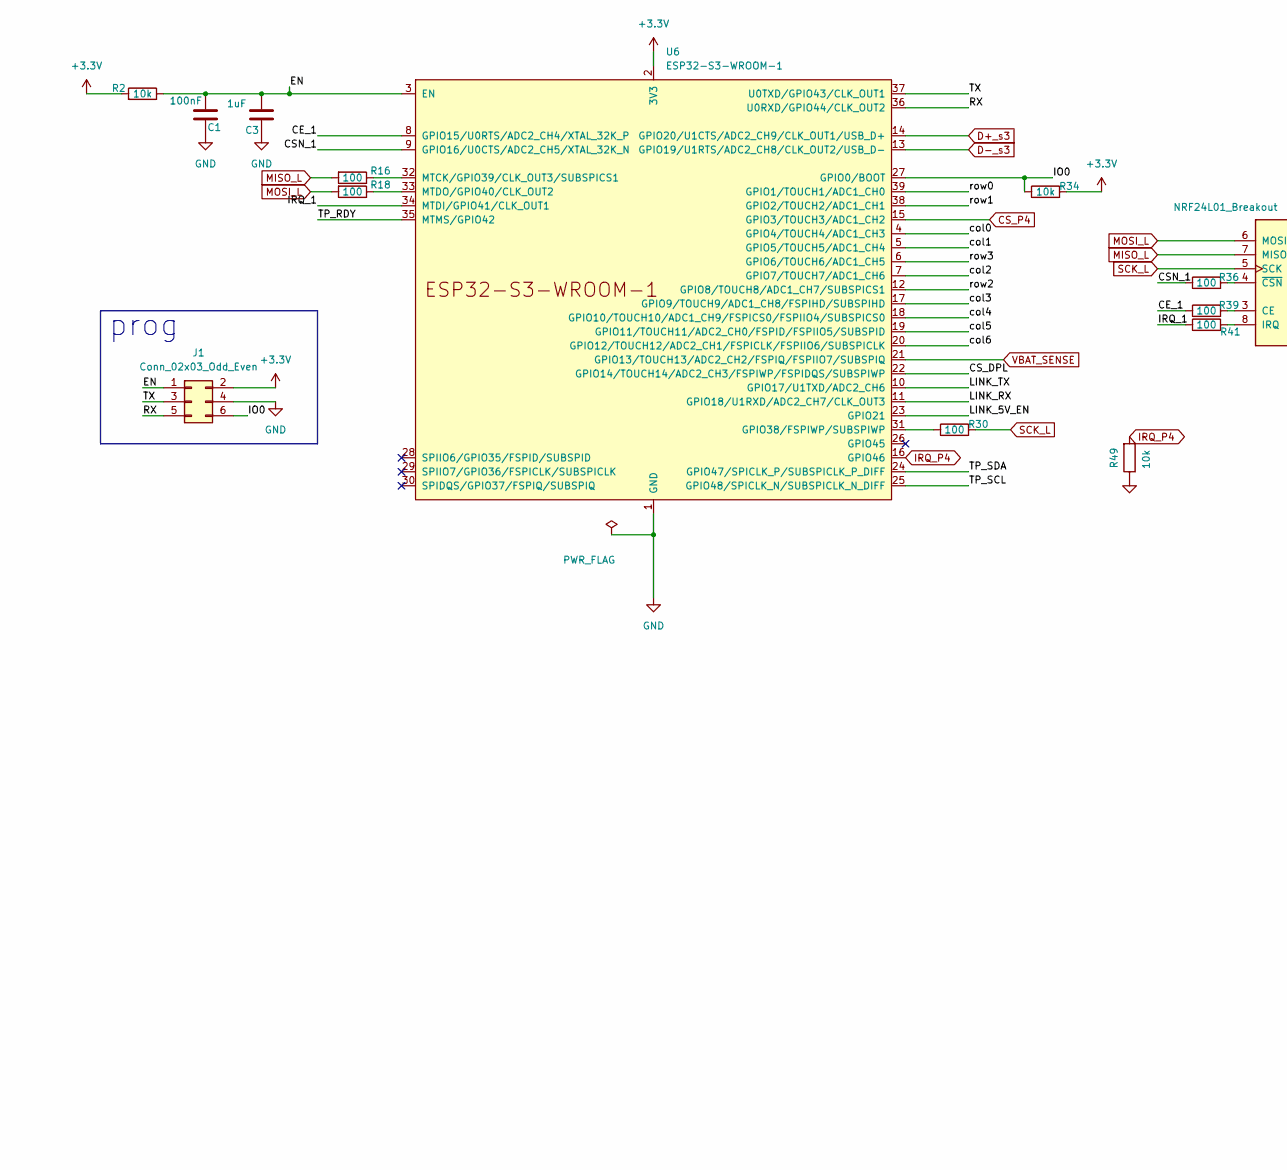
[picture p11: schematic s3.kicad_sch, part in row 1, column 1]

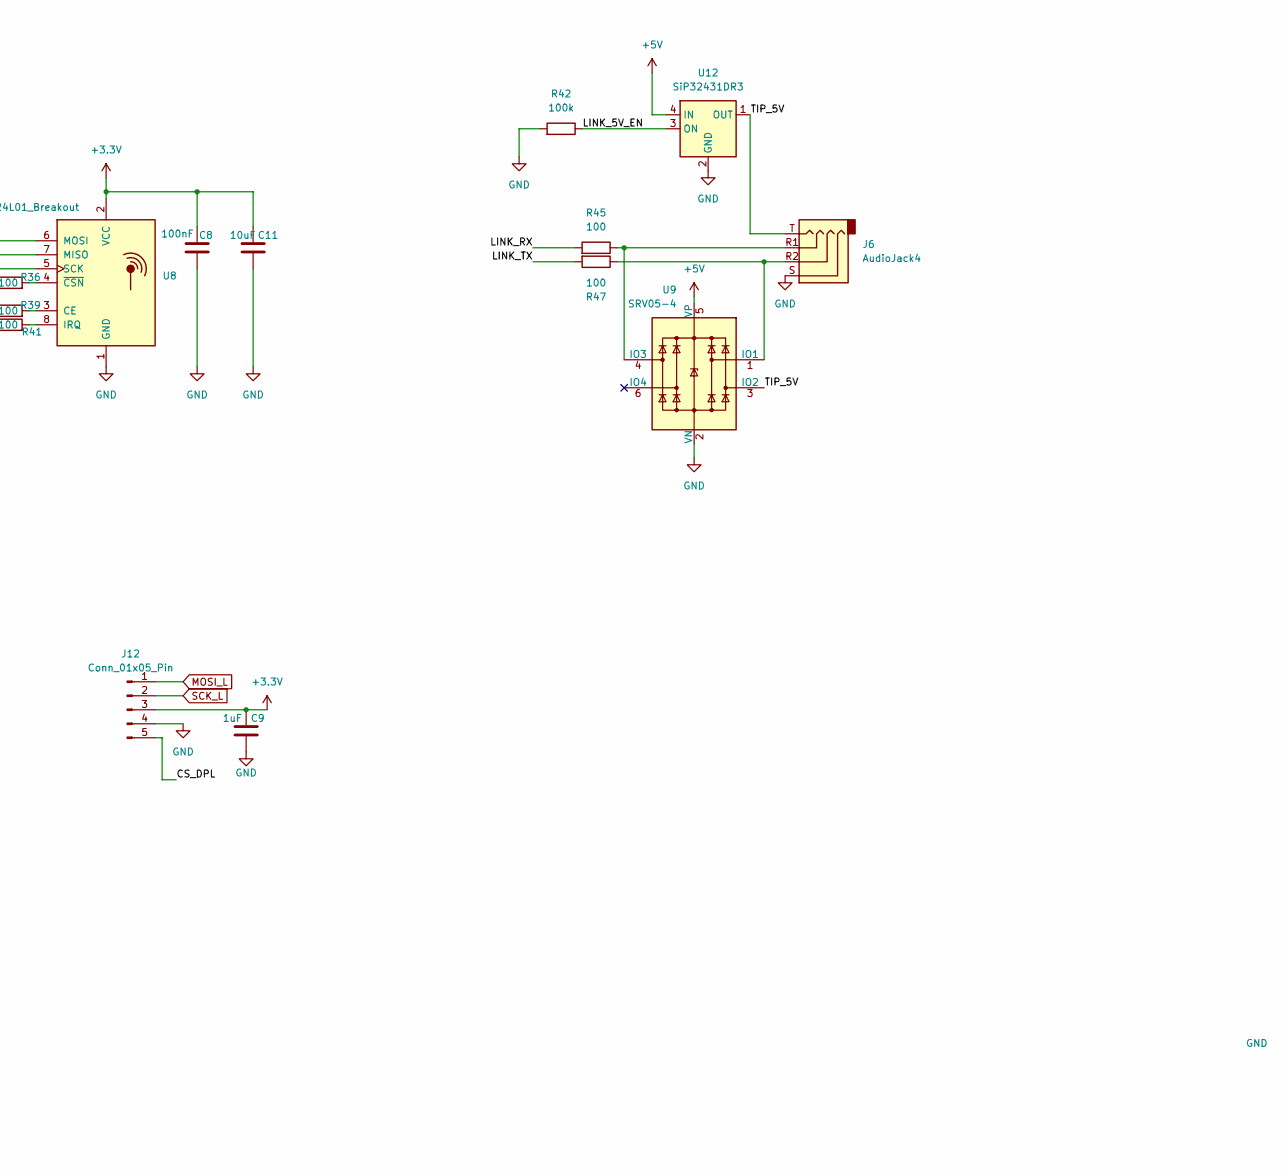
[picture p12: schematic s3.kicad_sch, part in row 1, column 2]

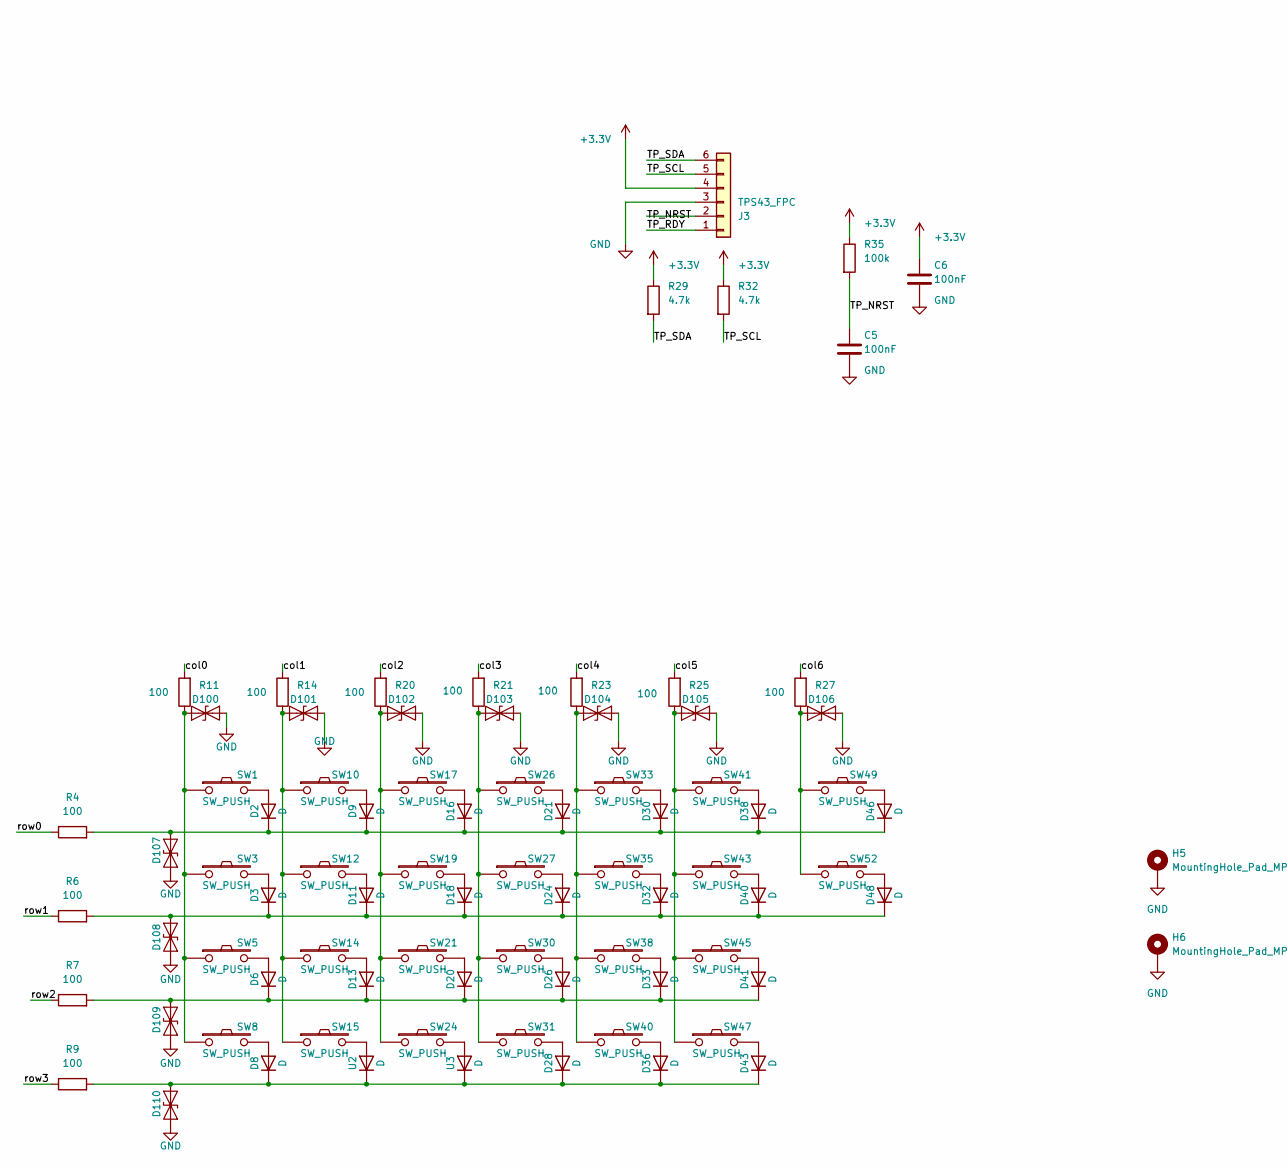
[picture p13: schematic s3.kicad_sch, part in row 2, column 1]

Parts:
C1, C5, C6, C8: 100nF; C_0603_1608Metric_Pad1.08x0.95mm_HandSolder
C3, C9: 1uF; C_0805_2012Metric_Pad1.18x1.45mm_HandSolder
C11: 10uF; C_1206_3216Metric_Pad1.33x1.80mm_HandSolder
D2, D3, D6, D8, D9, D11, D13, D16, D18, D20, D21, D24, D26, D28, D30, D32, D33, D36, D38, D40, D41, D43, D46, D48: D; D_SOD-123
D100, D101, D102, D103, D104, D105, D106, D107, D108, D109, D110: SD05C-01F; D_SOD-323; LCSC C2827707
H5, H6, H7, H8: MountingHole_Pad_MP; MountingHole_3.2mm_M3_DIN965_Pad
J1: Conn_02x03_Odd_Even; PinHeader_2x03_P1.27mm_Vertical
J3: TPS43_FPC; Hirose_FH12-6S-0.5SH_1x06-1MP_P0.50mm_Horizontal; LCSC C202118
J6: AudioJack4; MJ-4PP-9_rev3
J12: Conn_01x05_Pin; PinHeader_1x05_P2.54mm_Vertical
R2, R34, R49: 10k; R_0603_1608Metric_Pad0.98x0.95mm_HandSolder
R4, R6, R7, R9, R11, R14, R16, R18, R20, R21, R23, R25, R27, R30, R36, R39, R41, R45, R47: 100; R_0603_1608Metric_Pad0.98x0.95mm_HandSolder
R29, R32: 4.7k; R_0603_1608Metric_Pad0.98x0.95mm_HandSolder
R35, R42: 100k; R_0603_1608Metric_Pad0.98x0.95mm_HandSolder
SW1, SW3, SW5, SW8, SW10, SW12, SW14, SW15, SW17, SW19, SW21, SW24, SW26, SW27, SW30, SW31, SW33, SW35, SW38, SW40, SW41, SW43, SW45, SW47, SW49, SW52: SW_PUSH; SW_Cherry_MX_1.00u_PCB
U2, U3: D; D_SOD-123
U6: ESP32-S3-WROOM-1; ESP32-S3-WROOM-1U; LCSC C2913204
U8: NRF24L01_Breakout; NRF24L01
U9: SRV05-4; SOT-23-6; LCSC C13612
U12: SiP32431DR3; SOT-363_SC-70-6; LCSC C141606

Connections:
+3.3V: C6.1, C8.2, C9.2, C11.2, J1.2, J3.4, J12.3, R2.2, R29.1, R32.1, R34.2, R35.1, U6.2 (3V3), U8.2 (VCC); also elsewhere on the board
+5V: U9.5 (VP), U12.4 (IN); also elsewhere on the board
/s3/CE_1: R39.1, U6.8 (GPIO15/U0RTS/ADC2_CH4/XTAL_32K_P)
/s3/CSN_1: R36.1, U6.9 (GPIO16/U0CTS/ADC2_CH5/XTAL_32K_N)
/s3/CS_DPL: J12.5, U6.22 (GPIO14/TOUCH14/ADC2_CH3/FSPIWP/FSPIDQS/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)
/s3/EN: C1.2, C3.2, J1.1, R2.1, U6.3 (EN)
/s3/IO0: J1.6, R34.1, U6.27 (GPIO0/BOOT)
/s3/IRQ_1: R41.1, U6.34 (MTDI/GPIO41/CLK_OUT1)
/s3/LINK_5V_EN: R42.1, U6.23 (GPIO21), U12.3 (ON)
/s3/LINK_RX: R45.2, U6.11 (GPIO18/U1RXD/ADC2_CH7/CLK_OUT3)
/s3/LINK_TX: R47.2, U6.10 (GPIO17/U1TXD/ADC2_CH6)
/s3/RX: J1.5, U6.36 (U0RXD/GPIO44/CLK_OUT2)
/s3/TIP_5V: J6.T, U9.3 (IO2), U12.1 (OUT)
/s3/TP_NRST: C5.1, J3.2, R35.2
/s3/TP_RDY: J3.1, U6.35 (MTMS/GPIO42)
/s3/TP_SCL: J3.5, R32.2, U6.25 (GPIO48/SPICLK_N/SUBSPICLK_N_DIFF)
/s3/TP_SDA: J3.6, R29.2, U6.24 (GPIO47/SPICLK_P/SUBSPICLK_P_DIFF)
/s3/TX: J1.3, U6.37 (U0TXD/GPIO43/CLK_OUT1)
/s3/col0: R11.2, U6.4 (GPIO4/TOUCH4/ADC1_CH3)
/s3/col1: R14.2, U6.5 (GPIO5/TOUCH5/ADC1_CH4)
/s3/col2: R20.2, U6.7 (GPIO7/TOUCH7/ADC1_CH6)
/s3/col3: R21.2, U6.17 (GPIO9/TOUCH9/ADC1_CH8/FSPIHD/SUBSPIHD)
/s3/col4: R23.2, U6.18 (GPIO10/TOUCH10/ADC1_CH9/FSPICS0/FSPIIO4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)
/s3/col5: R25.2, U6.19 (GPIO11/TOUCH11/ADC2_CH0/FSPID/FSPIIO5/S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)
/s3/col6: R27.2, U6.20 (GPIO12/TOUCH12/ADC2_CH1/FSPICLK/FSPIIO6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)
/s3/row0: R4.1, U6.39 (GPIO1/TOUCH1/ADC1_CH0)
/s3/row1: R6.1, U6.38 (GPIO2/TOUCH2/ADC1_CH1)
/s3/row2: R7.1, U6.12 (GPIO8/TOUCH8/ADC1_CH7/SUBSPICS1)
/s3/row3: R9.1, U6.6 (GPIO6/TOUCH6/ADC1_CH5)
CS_P4: U6.15 (GPIO3/TOUCH3/ADC1_CH2); also elsewhere on the board
D+_s3: U6.14 (GPIO20/U1CTS/ADC2_CH9/CLK_OUT1/USB_D+); also elsewhere on the board
D-_s3: U6.13 (GPIO19/U1RTS/ADC2_CH8/CLK_OUT2/USB_D-); also elsewhere on the board
GND: C1.1, C3.1, C5.2, C6.2, C8.1, C9.1, C11.1, D100.2 (A2), D101.2 (A2), D102.2 (A2), D103.2 (A2), D104.2 (A2), D105.2 (A2), D106.2 (A2), D107.1 (A1), D108.1 (A1), D109.1 (A1), D110.1 (A1), H5.MP, H6.MP, H7.MP, H8.MP, J1.4, J3.3, J6.S, J12.4, R42.2, R49.1, U6.1 (GND), U6.40 (GND), U6.41 (GND), U8.1 (GND), U9.2 (VN), U12.2 (GND), U12.5 (GND); also elsewhere on the board
IRQ_P4: R49.2, U6.16 (GPIO46); also elsewhere on the board
MISO_L: R16.2, U8.7 (MISO); also elsewhere on the board
MOSI_L: J12.1, R18.2, U8.6 (MOSI); also elsewhere on the board
unnamed: D2.2 (A), SW1.2
unnamed: D3.2 (A), SW3.2
unnamed: D6.2 (A), SW5.2
unnamed: D8.2 (A), SW8.2
unnamed: D9.2 (A), SW10.2
unnamed: D11.2 (A), SW12.2
unnamed: D13.2 (A), SW14.2
unnamed: D16.2 (A), SW17.2
unnamed: D18.2 (A), SW19.2
unnamed: D20.2 (A), SW21.2
unnamed: D21.2 (A), SW26.2
unnamed: D24.2 (A), SW27.2
unnamed: D26.2 (A), SW30.2
unnamed: D28.2 (A), SW31.2
unnamed: D30.2 (A), SW33.2
unnamed: D32.2 (A), SW35.2
unnamed: D33.2 (A), SW38.2
unnamed: D36.2 (A), SW40.2
unnamed: D38.2 (A), SW41.2
unnamed: D40.2 (A), SW43.2
unnamed: D41.2 (A), SW45.2
unnamed: D43.2 (A), SW47.2
unnamed: D46.2 (A), SW49.2
unnamed: D48.2 (A), SW52.2
unnamed: D100.1 (A1), R11.1, SW1.1, SW3.1, SW5.1, SW8.1
unnamed: D101.1 (A1), R14.1, SW10.1, SW12.1, SW14.1, SW15.1
unnamed: D102.1 (A1), R20.1, SW17.1, SW19.1, SW21.1, SW24.1
unnamed: D103.1 (A1), R21.1, SW26.1, SW27.1, SW30.1, SW31.1
unnamed: D104.1 (A1), R23.1, SW33.1, SW35.1, SW38.1, SW40.1
unnamed: D105.1 (A1), R25.1, SW41.1, SW43.1, SW45.1, SW47.1
unnamed: D106.1 (A1), R27.1, SW49.1, SW52.1
unnamed: D2.1 (K), D9.1 (K), D16.1 (K), D21.1 (K), D30.1 (K), D38.1 (K), D46.1 (K), D107.2 (A2), R4.2
unnamed: D3.1 (K), D11.1 (K), D18.1 (K), D24.1 (K), D32.1 (K), D40.1 (K), D48.1 (K), D108.2 (A2), R6.2
unnamed: D6.1 (K), D13.1 (K), D20.1 (K), D26.1 (K), D33.1 (K), D41.1 (K), D109.2 (A2), R7.2
unnamed: D8.1 (K), D28.1 (K), D36.1 (K), D43.1 (K), D110.2 (A2), R9.2, U2.1 (K), U3.1 (K)
unnamed: SW15.2, U2.2 (A)
unnamed: SW24.2, U3.2 (A)
unnamed: R30.1, U6.31 (GPIO38/FSPIWP/SUBSPIWP)
unnamed: R16.1, U6.32 (MTCK/GPIO39/CLK_OUT3/SUBSPICS1)
unnamed: R18.1, U6.33 (MTDO/GPIO40/CLK_OUT2)
unnamed: R39.2, U8.3 (CE)
unnamed: R41.2, U8.8 (IRQ)
unnamed: R36.2, U8.4 (~CSN)
unnamed: J6.R2, R47.1, U9.1 (IO1)
unnamed: J6.R1, R45.1, U9.4 (IO3)
SCK_L: J12.2, R30.2, U8.5 (SCK); also elsewhere on the board
VBAT_SENSE: U6.21 (GPIO13/TOUCH13/ADC2_CH2/FSPIQ/FSPIIO7/S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); also elsewhere on the board

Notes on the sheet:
prog

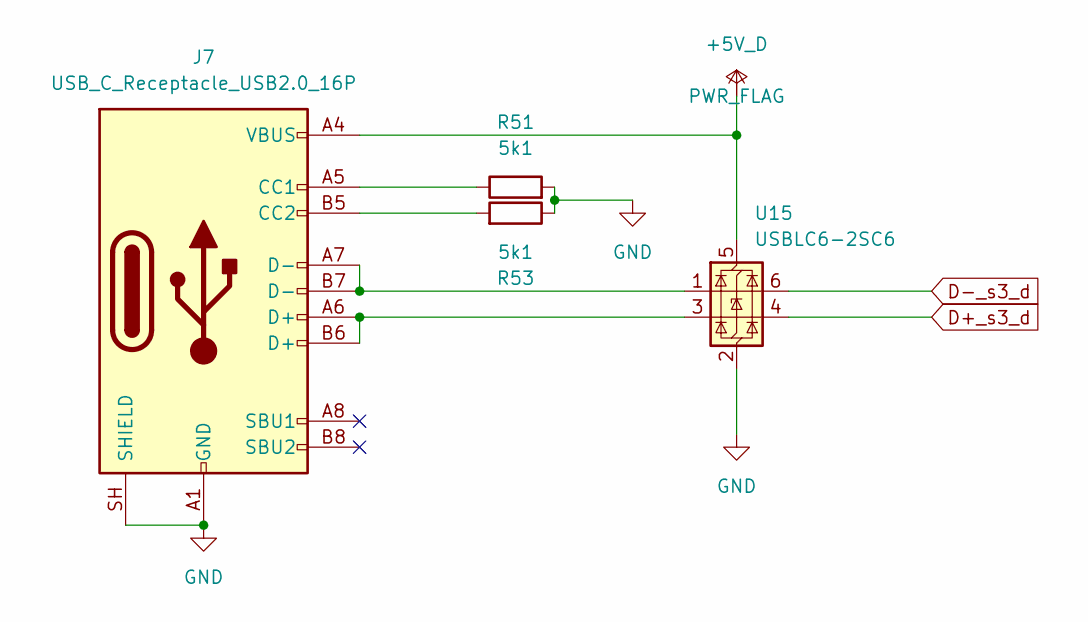
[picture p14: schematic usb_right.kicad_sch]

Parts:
J7: USB_C_Receptacle_USB2.0_16P; USB_C_Receptacle_HRO_TYPE-C-31-M-12; LCSC C165948
R51, R53: 5k1; R_0603_1608Metric_Pad0.98x0.95mm_HandSolder
U15: USBLC6-2SC6; SOT-23-6; LCSC C7519

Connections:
+5V_D: J7.A4 (VBUS), J7.A9 (VBUS), J7.B4 (VBUS), J7.B9 (VBUS), U15.5 (VBUS); also elsewhere on the board
D+_s3_d: U15.4 (I/O2); also elsewhere on the board
D-_s3_d: U15.6 (I/O1); also elsewhere on the board
GND: J7.A1 (GND), J7.A12 (GND), J7.B1 (GND), J7.B12 (GND), J7.SH (SHIELD), R51.2, R53.1, U15.2 (GND); also elsewhere on the board
unnamed: J7.A5 (CC1), R51.1
unnamed: J7.B5 (CC2), R53.2
unnamed: J7.A6 (D+), J7.B6 (D+), U15.3 (I/O2)
unnamed: J7.A7 (D-), J7.B7 (D-), U15.1 (I/O1)

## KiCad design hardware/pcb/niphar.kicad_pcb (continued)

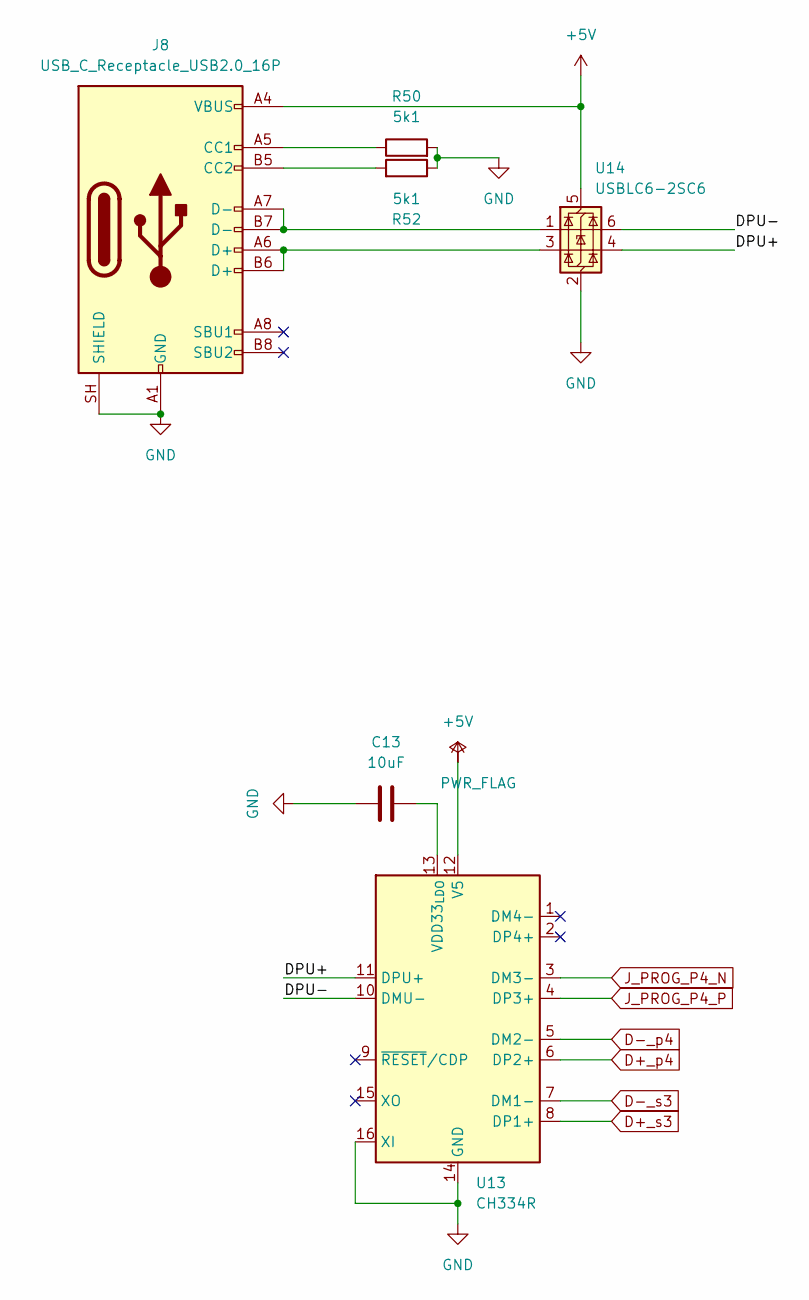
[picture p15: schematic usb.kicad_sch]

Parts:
C13: 10uF; C_1206_3216Metric_Pad1.33x1.80mm_HandSolder
J8: USB_C_Receptacle_USB2.0_16P; USB_C_Receptacle_HRO_TYPE-C-31-M-12; LCSC C165948
R50, R52: 5k1; R_0603_1608Metric_Pad0.98x0.95mm_HandSolder
U13: CH334R; QSOP-16_3.9x4.9mm_P0.635mm; LCSC C4154405
U14: USBLC6-2SC6; SOT-23-6; LCSC C7519

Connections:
+5V: J8.A4 (VBUS), J8.A9 (VBUS), J8.B4 (VBUS), J8.B9 (VBUS), U13.12 (V5), U14.5 (VBUS); also elsewhere on the board
/USB/DPU+: U13.11 (DPU+), U14.4 (I/O2)
/USB/DPU-: U13.10 (DMU-), U14.6 (I/O1)
D+_p4: U13.6 (DP2+); also elsewhere on the board
D+_s3: U13.8 (DP1+); also elsewhere on the board
D-_p4: U13.5 (DM2-); also elsewhere on the board
D-_s3: U13.7 (DM1-); also elsewhere on the board
GND: C13.2, J8.A1 (GND), J8.A12 (GND), J8.B1 (GND), J8.B12 (GND), J8.SH (SHIELD), R50.2, R52.1, U13.14 (GND), U13.16 (XI), U14.2 (GND); also elsewhere on the board
J_PROG_P4_N: U13.3 (DM3-); also elsewhere on the board
J_PROG_P4_P: U13.4 (DP3+); also elsewhere on the board
unnamed: J8.A5 (CC1), R50.1
unnamed: J8.B5 (CC2), R52.2
unnamed: J8.A6 (D+), J8.B6 (D+), U14.3 (I/O2)
unnamed: J8.A7 (D-), J8.B7 (D-), U14.1 (I/O1)
unnamed: C13.1, U13.13 (VDD33_{LDO})

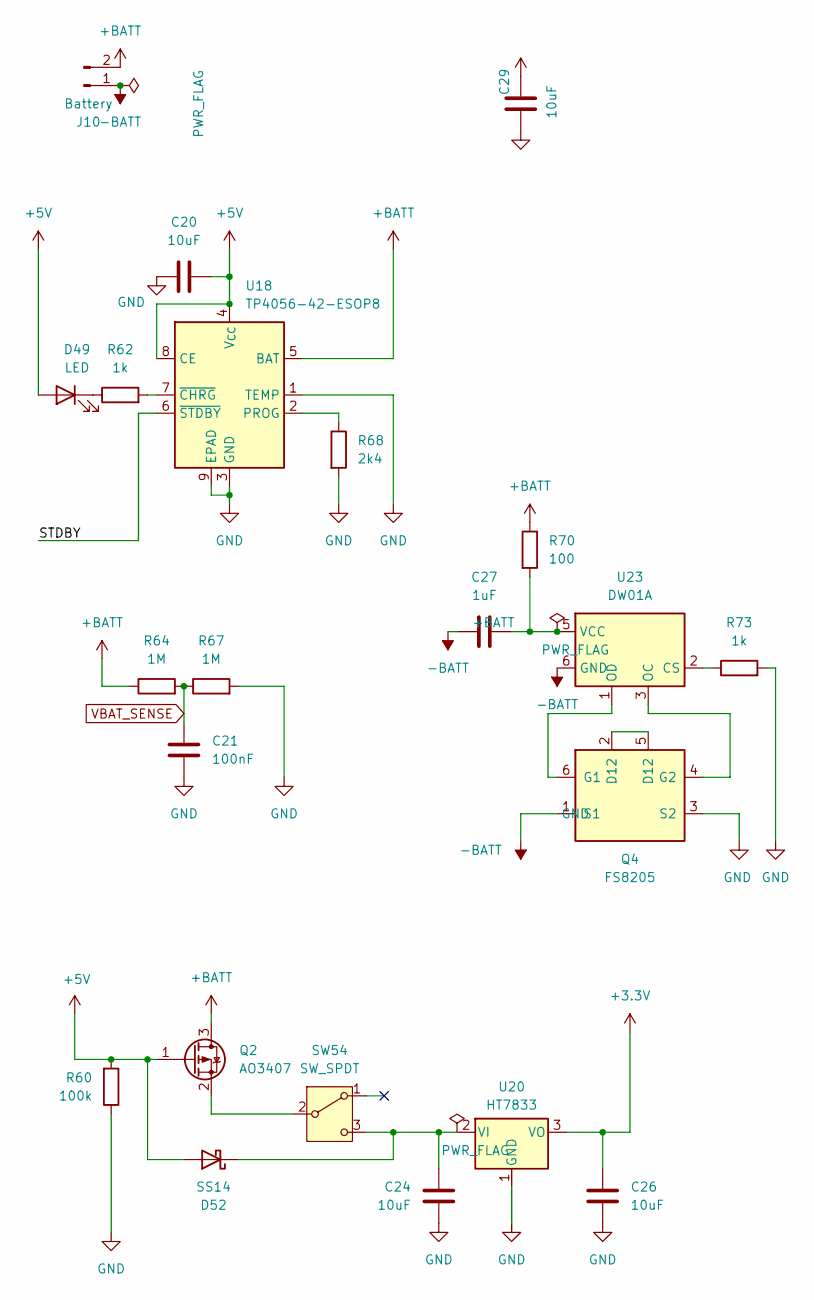
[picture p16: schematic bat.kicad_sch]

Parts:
C20, C24, C26, C29: 10uF; C_1206_3216Metric_Pad1.33x1.80mm_HandSolder
C21: 100nF; C_0603_1608Metric_Pad1.08x0.95mm_HandSolder
C27: 1uF; C_0805_2012Metric_Pad1.18x1.45mm_HandSolder
D49: LED; LED_0805_2012Metric_Pad1.15x1.40mm_HandSolder
D52: SS14; D_SMA; LCSC C2480
J10: Battery; PinHeader_1x02_P2.54mm_Vertical
Q2: AO3407; SOT-23; LCSC C351408
Q4: FS8205; SOT-23-6; LCSC C32254
R60: 100k; R_0603_1608Metric_Pad0.98x0.95mm_HandSolder
R62, R73: 1k; R_0805_2012Metric_Pad1.20x1.40mm_HandSolder
R64, R67: 1M; R_0805_2012Metric_Pad1.20x1.40mm_HandSolder
R68: 2k4; R_0805_2012Metric_Pad1.20x1.40mm_HandSolder
R70: 100; R_0603_1608Metric_Pad0.98x0.95mm_HandSolder
SW54: SW_SPDT; SW_SPDT_PCM12; LCSC C431540
U18: TP4056-42-ESOP8; SOIC-8-1EP_3.9x4.9mm_P1.27mm_EP2.41x3.3mm_ThermalVias; LCSC C16581
U20: HT7833; SOT-89-3; LCSC C50936
U23: DW01A; SOT-23-6; LCSC C351410

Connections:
+3.3V: C26.2, U20.3 (VO); also elsewhere on the board
+5V: C20.2, D49.2 (A), D52.2 (A), Q2.1 (G), R60.2, U18.4 (V_{CC}), U18.8 (CE); also elsewhere on the board
+BATT: C29.1, J10.2, Q2.3 (D), R64.1, R70.1, U18.5 (BAT)
-BATT: C27.2, J10.1, Q4.1 (S1), U23.6 (GND)
/bat/STDBY: U18.6 (~STDBY)
GND: C20.1, C21.1, C24.1, C26.1, C29.2, Q4.3 (S2), R60.1, R67.2, R68.2, R73.2, U18.1 (TEMP), U18.3 (GND), U18.9 (EPAD), U20.1 (GND); also elsewhere on the board
unnamed: D49.1 (K), R62.1
unnamed: C24.2, D52.1 (K), SW54.3 (C), U20.2 (VI)
unnamed: Q2.2 (S), SW54.2 (B)
unnamed: Q4.2 (D12), Q4.5 (D12)
unnamed: Q4.6 (G1), U23.1 (OD)
unnamed: Q4.4 (G2), U23.3 (OC)
unnamed: R68.1, U18.2 (PROG)
unnamed: R62.2, U18.7 (~CHRG)
unnamed: R73.1, U23.2 (CS)
unnamed: C27.1, R70.2, U23.5 (VCC)
VBAT_SENSE: C21.2, R64.2, R67.1; also elsewhere on the board

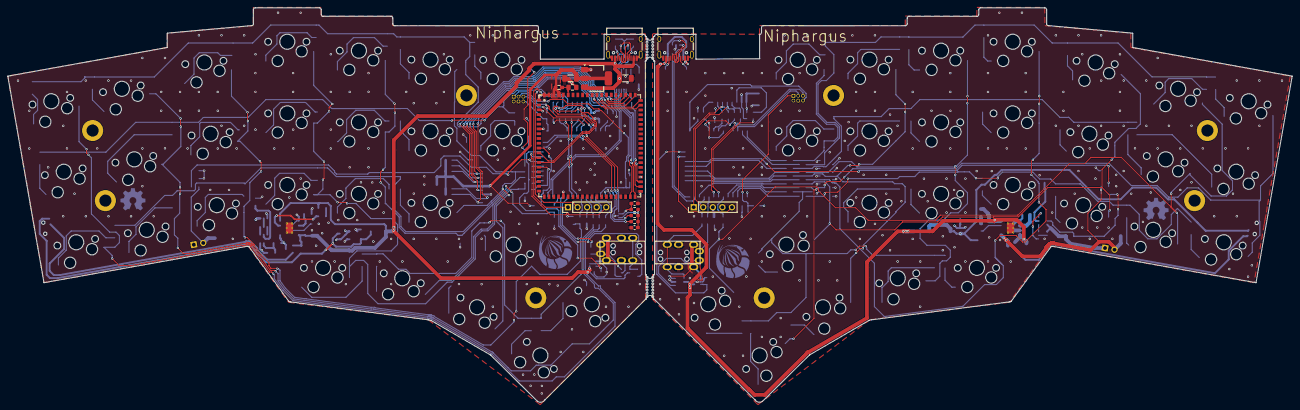
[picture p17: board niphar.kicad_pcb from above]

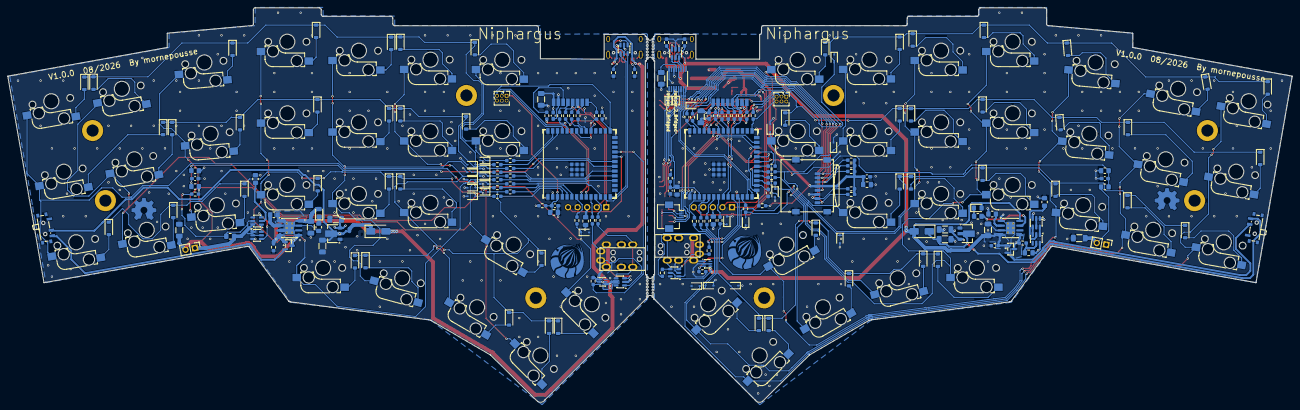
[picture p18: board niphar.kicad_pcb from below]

Board: 4 copper layers, 340.8 x 104.7 mm, 283 parts (206 on the bottom side), 208 nets.

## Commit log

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2026-07-29 WIP refonte Rili : chantier KiCad + pipeline tripwire
    - Schéma/PCB corne-cherry en cours de refonte ESP32/nRF24 (travail en cours,
    DRC assumé au-dessus de l'ancien état : baseline ratchet réalignée sur la
    réalité du chantier — 814 erreurs DRC, 175 warnings ; objectif zéro en fin
    de refonte)
    - Pipeline anti-régression tripwire : scripts/check.sh, kicad-check.sh,
    hooks git + Claude Code, CI GitHub Actions, CLAUDE.md
    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
    [Atreus62-2021-03-02-20-39-17.sch, corne-cherry.kicad_sch, s3.kicad_sch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]
2026-07-29 oracle DRC : tolérance de jitter (+10 erreurs) — hole_clearance non-déterministe
    Le test hole_clearance de KiCad 10 varie d'un run à l'autre sur ce board
    (mesuré : 814/817/818/819 erreurs, violations uniques différentes à chaque
    run). Sans tolérance, le tripwire criait au loup au hasard.
    - Rouge seulement si erreurs > réf + 10 (DRC uniquement, ERC déterministe)
    - Le ratchet ne descend que sous réf - 10 (un run chanceux ne verrouille plus
    une baseline intenable)
    - Garde-fou : réf à 0 => tolérance 0 (zéro veut dire zéro en fin de refonte)
    Preuve que l'oracle mord toujours : baseline abaissée à 800 -> rouge (818 > 810),
    baseline réelle 814 -> vert (818 <= 824).
    Co-Autho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
2026-07-29 Renommage projet KiCad : corne-cherry -> rili
    - corne-cherry/ -> rili/ ; fichiers projet corne-cherry.kicad_{pro,sch,pcb,prl}
    -> rili.* avec mise à jour des références internes (sheetfile, instances
    project) — la bibliothèque de rescue corne-cherry-rescue est préservée telle
    quelle (60+ références de symboles, la renommer casserait le schéma)
    - CI : le workflow tripwire écoutait la branche jorne, le repo rili vit sur
    main -> déclencheurs corrigés (la CI n'avait jamais tourné)
    - Références mises à jour : scripts/kicad-check.sh, hooks, CLAUDE.md,
    .gitignore (+ ignore de l'ancien corne-cherry-backups/), docs/plans
    - Lock KiCad périmé supprimé
    Vérifié : check.sh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
    [Atreus62-2021-03-02-20-39-17.sch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]
2026-07-29 CI : afficher last-fail.log et la version kicad-cli en cas d'échec
    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
2026-07-29 tripwire : baseline dédiée à l'environnement CI (.tripwire-kicad-baseline-ci)
    Constat (runs CI 10.0.4, identique au poste) : même design, mais +19 warnings
    ERC et +5 warnings DRC dans le conteneur (fontes/libs globales différentes).
    Une seule baseline ne peut pas être verte des deux côtés sans mentir d'un côté.
    - kicad-check.sh : TRIPWIRE_BASELINE surcharge le fichier de référence
    - CI : TRIPWIRE_BASELINE=.tripwire-kicad-baseline-ci (erc 0/107, drc 813/180,
    mesures des runs précédents) — même ratchet, mêmes objectifs zéro
    - CLAUDE.md : caveat documenté (env + version + jitter hole_clearance)
    Claude-Session: https: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
2026-07-30 WIP schéma v2 Niphargus + rename projet rili → niphar
    Grosse session schéma (binôme Mae/Claude) :
    - Panneau 2 moitiés : matrice droite miroir, nets séparés (col*_d/row*_d)
    - Feuille s3 : ESP32-S3-WROOM-1, matrice 11 GPIO RTC, nRF24 (SPI + 100R),
    J_PROG 6 pins (ESP-Prog), USB_DP/DM, TRRS J6 protégé (SRV05-4 shunt,
    100R série, load switch poignée de main 5V)
    - Feuille bat : chaîne 16340 complète — DW01A+FS8205, TP4056 500mA,
    load-sharing AO3407, MCP1700, jauge VBAT_SENSE (validée par netlist)
    - Feuille usb : USB-C 16P + CC 5k1 + USBLC6, hub CH334R (S3+P4, mode
    sans crystal, LDO interne isolé du rail 3V3, RESET# pull-up)
    - Feuille P4 (coffre, en cours) + Matrix ; hiér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
    [bat.kicad_sch, corne-cherry.sch, matrix.kicad_sch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]
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2026-07-31 schéma v2 : coffre P4 complet — ERC 0 erreur
    - Feuille p4 (ex sans_titre) : AMS1117-3.3 (rail P4_3V3 séparé, 10µF/22µF),
    CHIP_PU RC 100k+100nF, USB HS (ESP_USB_P/N) vers le port 2 du hub,
    microSD slot UHS-I (CLK/CMD/DAT0-3 sur GPIO39-44, pull-ups 10k),
    prog P4 via port 3 du hub (USB-Serial-JTAG + jumpers d'isolation)
    - Périphériques : écran Sharp LS011B7DH03 (SPI partagé, CS_DPL=GPIO14),
    trackpad TPS43 (I2C 47/48, RDY=42, bloc généré+validé), C6 laissé vierge
    (OTA via P4 = voie officielle)
    - Ménage ERC : 65 no_connect + 6 PWR_FLAG posés par script (fix_nc.py),
    labels fantômes S3P4 supprimés — ERC projet : 71 → 0 erreur,
    warnings 262 → 158 (ratchet enre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
    [bat.kicad_sch, matrix.kicad_sch, niphar.kicad_sch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]
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2026-08-01 schéma v2 COMPLET : les deux moitiés — ERC 0 erreur
    Architecture finale (brainstorm + nuit de réflexion, décision Mae) :
    asymétrie d'origine confirmée — UN seul coffre.
    - Gauche (s3/bat/usb/p4) : S3 + matrice + trackpad TPS43 + alim 16340
    + USB-C + hub CH334R + coffre P4 (SD multi-ISO, PGP, prog-via-hub)
    - Droite (right/bat_right/usb_right, NOUVELLES feuilles) : S3 + matrice
    + écran Sharp + alim 16340 propre + USB-C simple (USBLC6 direct, sans hub)
    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
    [bat_right.kicad_sch, niphar.kicad_sch, p4.kicad_sch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]
2026-08-03 layout v2 : carte routée — PCB↔schéma réconciliés, BOM LCSC, TVS matrice, DRC 990→24
    - réconciliation PCB↔schéma en une passe : 105 empreintes remariées (matrice ×2,
    module P4), 54 périmées supprimées, ~140 importées par F8 ; footprint TRRS
    MJ-4PP-9_rev3 créé (pads mappés de l'ancien design fonctionnel)
    - placement : moitié droite générée au miroir exact du pré-placement gauche
    (axe x=188.46048), trous de montage symétrisés, origine de grille sur l'axe
    - protection ESD matrice : 22 SD05C-01F (un par ligne, côté switchs des 100R,
    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
    [bat.kicad_sch, bat_right.kicad_sch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]
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2026-08-03 layout : sérigraphie épurée + décrochement antenne nRF — listes de commande LCSC
    - PCB : labels de sérigraphie retirés, décrochement de contour sous l'antenne
    des modules nRF24 (dégagement RF)
    - commande-lcsc.csv : BOM importable dans l'outil LCSC (33 lignes, réfs vérifiées
    en ligne, quantités pour 2 builds) — diodes matrice passées en 1N4148W C81598
    (fuite nA vs µA des Schottky v1, enjeu deep sleep)
    - commande-hors-lcsc.md : décision antenne WROOM-1/1U à trancher, filières
    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
    [commande-lcsc.csv]
2026-08-04 commande : condos 10µF/22µF re-sourcés (stock LCSC)
    C13585 → C128855 (YAGEO 1206, en stock) ; C12891 → C45783 (Samsung 0805 Basic,
    un seul exemplaire, à souder sur le pad 1206 de la sortie AMS1117 — les fortes
    capacités ont migré vers les petits boîtiers, les 1206 se raréfient).
    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
    [commande-lcsc.csv]
2026-08-04 commande : stratégie TME d'abord (réductions) — LCSC réduit au made-in-China
    commande-tme.csv : 27 lignes par MPN fabricant (Royalohm = mêmes réfs que
    UNI-ROYAL, Samsung CL, Semtech SD05C.TCT/SRV05, Hirose, Würth, WROOM) ;
    substitutions AMS1117→LD1117S33TR (drop-in ST) et SD05C-01FTG→SD05C.TCT.
    commande-lcsc.csv : 7 lignes résiduelles (WCH/TP4056/DW01A/FS8205/AO3407/
    MSK-12C02 + USB-C HRO verrouillé par l'empreinte).
    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
    [commande-lcsc.csv, commande-tme.csv]
2026-08-04 commande : liens produits dans les CSV (TME recherche exacte, LCSC direct)
    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
    [commande-lcsc.csv, commande-tme.csv]
2026-08-04 commande : liens TME réels vérifiés ligne à ligne — condos rapatriés chez LCSC
    Vérification par 4 agents parallèles (une recherche web par MPN) : 20 lignes TME
    avec leurs vraies URL produit (le format ?search= ne fonctionnait pas), SIP32431
    finalement présent, WROOM-1U hors stock (argument antenne PCB), 1M/100k 0805 en
    série S Royalohm (série W absente), microSD basculée sur Hirose DM3AT(40) en
    option A. Condensateurs Samsung CL retirés de TME (série NNNC en fin de vie
    là-bas) et re-listés chez LCSC avec les C-numbers déjà vérifiés en stock ;
    MPN 1µF 0805 erroné corrigé au passage (C28323).
    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
    [commande-lcsc.csv, commande-tme.csv]
2026-08-04 commande : ESP32 et microSD retirés — déjà en stock chez Mae
    Les empreintes de la carte (WROOM-1U, Würth 693072010801) correspondent au
    matériel réel de son tiroir — décisions antenne et microSD closes.
    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
    [commande-tme.csv]
2026-08-04 commande : 3e fichier AliExpress (commande-ali.csv)
    10 lignes avec liens (repris du README v1 quand ils existaient) et colonne
    Statut — « à vérifier tiroir » pour le matériel probablement déjà possédé.
    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
    [commande-ali.csv]
2026-08-06 commande : kit d'upload JLCPCB (gerbers panneau vertical + BOM 29 lignes + CPL)
    Panneau 185×212 mm : moitié droite tournée 180° sous la gauche, 2 rails
    (structurel droit + maintien gauche), 8 tabs à mouse-bites. BOM unifiée une
    réf par valeur (C22775/C25804 rétablis après l'inversion 100R/10k), CPL 202
    composants régénéré du panneau final.
    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
    [bom-jlc.csv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]
2026-08-06 layout : panneau vertical 2 rails dans le dépôt + baseline chantier
    Panneau 185×212 (droite tournée 180°, rails + 8 tabs mouse-bites) appliqué par
    Mae, F8 des passifs unifiés. Baseline DRC re-référencée 24/19 → 36/26 (état
    panneau, finitions DRC prévues : pistes près des lignes de rupture, vias de
    maillage orphelins dans les bandes sans cuivre).
    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
    [bat.kicad_sch, bat_right.kicad_sch, p4.kicad_sch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]
2026-08-06 commande : MCP1700 variante SOT-89 (/MB, C632000) — la /TT était qty=0 chez JLC (footprint mismatch) ; 1N4148W confirmé C81598
    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
    [bom-jlc.csv, commande-tme.csv]
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2026-08-06 fix : virgule en trop ligne C28323
    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
    [commande-lcsc.csv]
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2026-08-06 review schéma : LDO S3 corrigé (pins SOT-89) + 8 valeurs — HT7833 en place
    Revue 4 relecteurs parallèles avant commande, validée ligne à ligne sur la
    netlist. BLOQUANT réparé : U20/U21 avaient le brochage SOT-23 du MCP1700 sur
    des pastilles SOT-89 → entrée/sortie inversées pour tout LDO réel ; pins 2/3
    échangés dans la déf, Value=HT7833 (C50936), F8 + reroutage des 2 zones par
    Mae, pads vérifiés (1=GND 2=VIN 3=VOUT). Valeurs : bulk 3V3 C11/C12 et condos
    LDO C23-C26 → 10µF (C15850), CHIP_PU P4 R54→10k C14→1µF. Baseline ERC 200→202
    (lib_symbol_mismatch des défs LDO éditées). Validé par la revue : chaînes
    batterie/charge/load-share, paires USB bout en bout, hub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
    [bat.kicad_sch, bat_right.kicad_sch, p4.kicad_sch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]
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2026-08-06 review : solde complet — Tip TRRS protégé, condos +BATT, prog P4 dégagée
    - TVS Tip : canal 3 des SRV05 relié au Tip des deux jacks (net TIP_5V, validé
    netlist : jack.T + load switch OUT + SRV05 sans toucher LINK_5V_EN)
    - C29/C30 : 10µF sur +BATT/+BATT_D près des TP4056, placés et routés par Mae
    - R48/R49 supprimés par Mae (CH334R : pull-up RESET# interne 25k, mode
    sans-quartz XO flottant conforme datasheet, fuite batterie→hub éliminée)
    - pistes JP1/JP2 (prog USB du P4) écartées de la zone GND : zéro violation
    - nettoyage : no_connect orpheline de la dépose R48/R49
    - DRC 36/26 → 17/22 (ménage de routage par Mae), ratchet enregistré
    Décisions documentées : SD ma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
    [bat.kicad_sch, bat_right.kicad_sch, bom-jlc.xlsx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]
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2026-08-07 cleanup : arborescence en anglais, boîtier sur contour dessiné, ERC au vert
    Boîtier
    - nouveau générateur `case/gen_case.py` : le contour du cadre n'est plus calculé
    par offset du PCB, il est lu dans `case/case_outline.svg` que Mae édite.
    Calage sur le repère KiCad validé à 0,009 mm en recoupant les 26 découpes de
    touches avec la position des switchs.
    - 3 pièces (cadre alu 8,5 + 2 plaques PC 2 mm), 8 vis de sandwich, 4 trous M3 de
    la carte, poche accu débouchante, TRRS percé par le dessus.
    - piège corrigé : l'origine d'un footprint KiCad n'est pas son centre — U16
    (module P4) est décalé de 20,51 mm, J12 de 5,08 mm. L'emprise vient des pads.
    - suppression de `gen_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
    [Atreus62-2021-03-02-20-39-17.sch, bat.kicad_sch, bat_right.kicad_sch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]
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2026-08-07 readme : retrait de la section Rouge-Gorge v1
    La v1 (2022) n'a jamais été construite et Niphargus lui succède : sa BOM, ses
    liens fournisseurs et ses photos n'avaient plus leur place en tête de dépôt.
    L'historique reste dans git et dans docs/BOM.md.
    Elle garde une mention d'une ligne dans les deux langues — un dérivé Jorne /
    Kyria rev2 resté sur le papier — pour que la filiation Rouge-Gorge -> rili ->
    Niphargus reste lisible.
    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
2026-08-07 panneau : contour refermé autour des tabs
    En interrompant les deux bords pour créer les tabs de la souris, je laissais 12
    extrémités libres. Un contour Edge.Cuts ouvert n'est pas interprétable : le
    panneau ressortait plein dans le visualiseur du fabricant — la souris n'était
    pas détourée.
    Le vide est maintenant refermé autour de chaque tab par deux segments
    horizontaux entre le rail (14,64) et la souris (18,00), ce qui délimite
    proprement le pont de matière.
    Vérifié : 151 segments, 0 extrémité libre — même état que le panneau du clavier
    seul, qui n'a jamais eu d'interruption (ses 4 pattes sont de la matière pleine
    dans un contour fermé).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
2026-08-15 CI : supprime le nightly, re-reference la baseline conteneur
    Le cron quotidien ne servait a rien : un design KiCad ne change pas tout seul
    entre deux nuits, le run ne detectait donc jamais rien et ne produisait que des
    echecs a 3h du matin.
    Mais le cron n'etait pas la cause des echecs — TOUS les runs echouaient, y
    compris sur push, parce que .tripwire-kicad-baseline-ci n'avait jamais ete
    re-referencee depuis les re-panneautages. Comptes releves dans le run du
    2026-08-15 (conteneur kicad/kicad:10.0.4) :
    erc 0 erreurs / 744 warnings (reference : 0 / 734)
    drc 17 erreurs / 42 warnings (reference : 36 / 22)
    Les ERREURS DRC ont baisse de 36 a 17 — le design s'est ameliore. Ce son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
2026-09-03 docs : le firmware vit dans KeSp_firmware, et le dongle n'a qu'un slot pour nous
    Deux corrections issues du design firmware du 2026-08-19 :
    - CLAUDE.md annonçait un dossier firmware/ à venir ici. Faux : le firmware
    Niphargus est développé dans KaSe_firmware, où il réutilise la pile RF, le
    moteur keymap et le protocole CDC du dongle. Ce repo reste le matériel.
    Les mentions d'un futur firmware/ dans les hooks et la norme TDD suivent.
    - Spec §9 : « Rouge-Gorge occupe les 2 slots d'un dongle » est périmé. Le
    second slot appartient à la souris Conchodytes, qui vise le même récepteur.
    Conséquence sur l'architecture : les moitiés ne parlent plus toutes deux au
    dongle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
2026-09-05 U21 : les 3 pastilles partageaient une seule ouverture de masque
    Point de chauffe constate sur le regulateur 3,3 V de la moitie droite. Le DRC
    avec remplissage des zones nomme la cause :
    [error] L'ouverture du masque de soudure de dessous relie des elements de
    nets differents
    - Pad 1 [GND] de U21
    - Pad 2 [Net-(D51-K)] de U21
    [error] idem entre Pad 2 [Net-(D51-K)] et Pad 3 [+3.3V_D]
    GND, l'entree et la sortie 3,3 V sans vernis entre elles : du cuivre nu
    continu, que la soudure ponte toute seule. Ce n'est pas une erreur de montage,
    la carte est fabriquee ainsi — toutes les moities droites sont concernees.
    Origine : les trois pads de U21 portaient une rota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
    [niphar.kicad_pcb]
2026-09-05 notes de banc : U21 corrige, batterie gauche a mesurer
    Deux pannes relevees au banc sur les cartes v1, consignees parce que les
    mesures attendent un multimetre.
    U21 : cause trouvee et PCB corrige (53564e4). Reste le geste sur les cartes
    deja fabriquees — dessouder le pontage, isoler les pastilles — et le
    chevauchement de courtyard avec C23, a replacer avec son routage.
    Batterie gauche : le design est hors de cause. Brochages DW01A et FS8205
    verifies sur les datasheets fabricant, deux sources independantes numerotees
    pour le FS8205. Les valeurs R70/R73 correspondent au schema d'application du
    DW01A au composant pres. La note garde la mise en garde : trois recherches web
    ont donne trois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
2026-09-07 U21 remplace : la moitie droite fonctionne
    Le pontage de masque avait court-circuite GND, l'entree et la sortie du
    regulateur, qui y est passe. Un HT7833 neuf et le rail +3.3V_D remonte.
    Le defaut de masque reste physiquement present sur les cartes fabriquees : le
    composant neuf est pose sur les memes trois pastilles sans vernis entre elles.
    Isoler les pastilles reste a faire. Le PCB est corrige pour la suite (53564e4).
    Claude-Session: https://claude.ai/code/session_01DronP1g7SanVhLombKppxw
